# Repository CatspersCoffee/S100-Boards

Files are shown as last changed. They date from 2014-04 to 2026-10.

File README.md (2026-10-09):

# S100-Boards

S-100 bus boards designed, laid out and built for a home-built S-100 system between 2013 and 2016: Z80 and 80386 CPU cards, static and dynamic memory, I/O and SPI peripheral cards, an 18-slot backplane and bus termination. The designs are in KiCad, with Xilinx CPLD and FPGA logic on most boards.

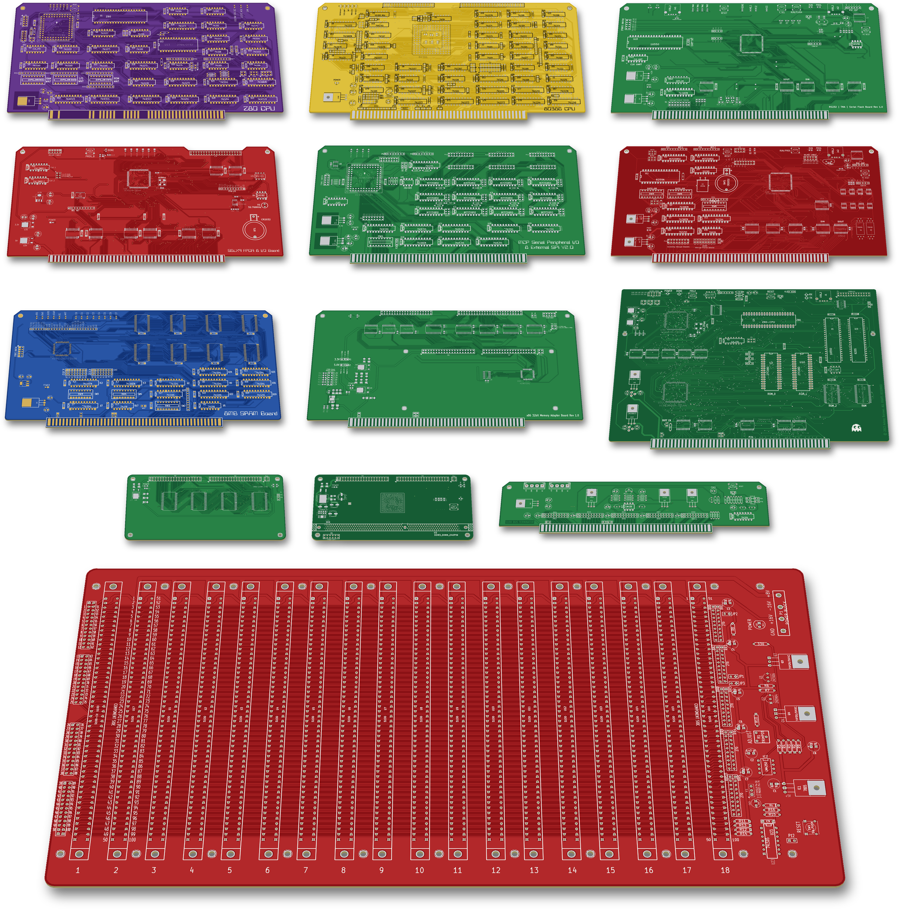
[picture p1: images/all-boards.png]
All boards, rendered from the KiCad files and fabrication gerbers


## Background

The S-100 bus began with the MITS Altair 8800 in 1975 and was standardised as IEEE-696 in 1983. Hobbyists still design new boards for it today. John Monahan's S100Computers.com and the N8VEM project are two well-known sources, and several boards here started from their designs.

This work ran from 2013 to 2016:
- **2013:** a Z80 single-board computer and the 18-slot backplane.
- **2014:** the Z80 CPU card, the 8MB SRAM boards, the serial-flash development board and the Spartan-6 I/O card.
- **2015:** the CPLD versions of the Z80 card, the 80386 CPU card, the SPI I/O board and the 32-bit memory experiments.
- **2016:** a revised backplane and the 8259A/SPI board.

The original S-100 cards of the 1970s and 80s were built from dozens of TTL chips, and later from HCMOS. A thread running through these boards is to move that glue logic into Xilinx CPLDs (XC9572, XC9572XL, XC95288XL) and Spartan-6 FPGAs. This covers bus status decoding, board select and address compare, memory bank and chip-select decoding, and I/O port decoding.
- **8MB SRAM board:** Rev 1 uses 27 TTL logic chips. Rev 2 does the same job with 14, one of them an XC9572XL.
- **Z80 CPU card:** from REV 4.0 an XC9572 takes over the S-100 status and control logic.
- **Other boards:** the CPLD or FPGA implements I/O ports and SPI interfaces that would otherwise need extra discrete logic.

## Boards

| Board | Folder | What it is | Status |
|---|---|---|---|
| Z80 CPU | [`Z80-CPU/`](Z80-CPU/) | Z80 bus-master CPU card, four revisions (REV 1.0–5.0); XC9572 CPLD from REV 4.0 | Built (all revisions) |
| 80386 CPU (V3.1) | [`80386-CPU/`](80386-CPU/) | John Monahan's S100Computers 80386 CPU board with small changes | Built |
| 18-slot backplane | [`Backplane-18-Slot/`](Backplane-18-Slot/) | 18-slot motherboard with active termination, Rev 1.0 and Rev 2.0 | Built (both) |
| Serial Flash board | [`Flash-UART/`](Flash-UART/) | USB UART, TMA lines and four SPI flash chips loaded over USB (CH341A); XC95288XL CPLD | Built |
| S6LX9 FPGA & I/O | [`S6LX9-FPGA-IO/`](S6LX9-FPGA-IO/) | Spartan-6 XC6SLX9 I/O card with RTC and serial RAM/flash | Built |
| MCP Serial Peripheral I/O | [`XC9500-IO/`](XC9500-IO/) | XC9572 CPLD + 12× MCP23S08 SPI port expanders (96 I/O lines) | Built |
| PIC-SPI | [`PIC-SPI/`](PIC-SPI/) | 8259A interrupt controller, SPI RTC/port expanders, 8× SPI flash; XC95288XL CPLD | Built |
| 8MB SRAM | [`SRAM-8MB/`](SRAM-8MB/) | 16 × 512 KB SRAM card, Rev 1 (TTL) and Rev 2.0 (XC9572XL CPLD) | Built (both) |
| x86 Memory Adapter + 4Mbit module | [`x86-Memory-Adapter/`](x86-Memory-Adapter/) | 32-bit memory adapter card (XC9572XL) and a 128K × 32 SRAM mezzanine (XC9536XL) | Module built; adapter not built |
| 4GB DRAM | [`DRAM-4GB-Unfinished/`](DRAM-4GB-Unfinished/) | Spartan-6 XC6SLX45 + DDR3 DIMM mezzanine for the memory adapter | Unfinished |
| Bus terminator | [`Bus-Terminator/`](Bus-Terminator/) | Plug-in active S-100 bus terminator | Built |
| Z80 FPGA SBC | [`Z80-FPGA-SBC/`](Z80-FPGA-SBC/) | 2013 Z80 single-board computer with XC95288XL CPLD and XC6SLX9 FPGA | Not built |
| SX6-MEM | [`SX6-MEM/`](SX6-MEM/) | Spartan-6 + SDRAM DIMM daughterboard, schematic only | Unfinished |
| NOR-SRAM loader | [`NOR-SRAM-Loader/`](NOR-SRAM-Loader/) | XC9572XL CPLD design for a serial-NOR-to-SRAM loader board | CPLD only |

Each folder has its own README with the parts, how the board works, the files, and a short "Things to check" list where something in the files looks worth a second look.

## Board views

Front and back of each board, rendered from its fabrication gerbers (or from the PCB file where no gerbers were made).

### Z80 CPU: [`Z80-CPU/`](Z80-CPU/)
The Z80 bus-master CPU card (REV 5.0 shown), with an XC9572 CPLD for the S-100 status and control logic.

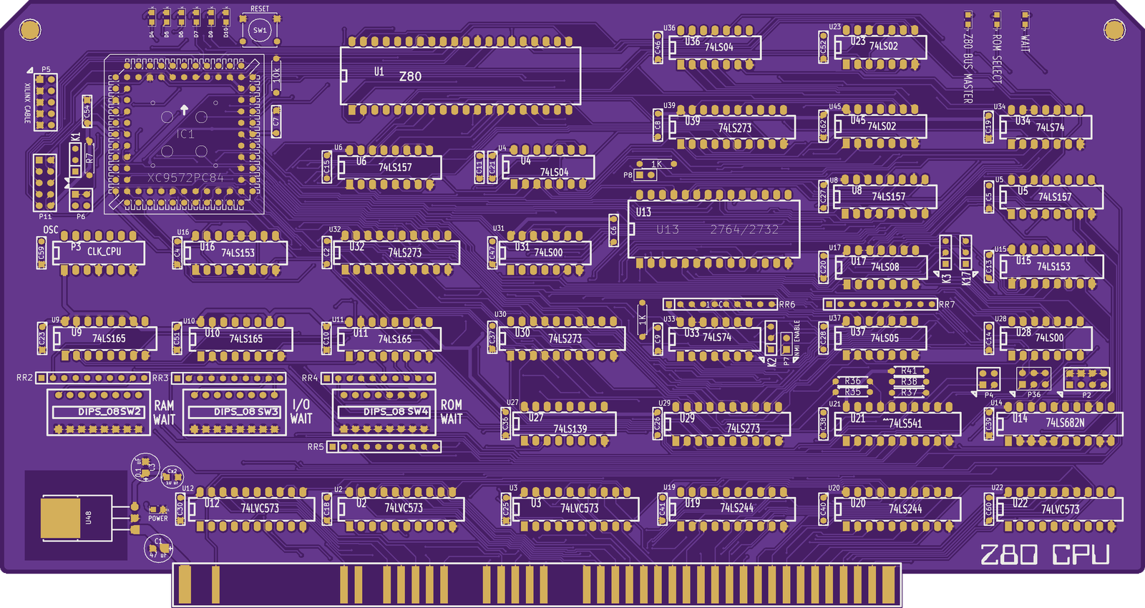
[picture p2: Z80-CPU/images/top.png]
Z80 CPU REV 5.0, front
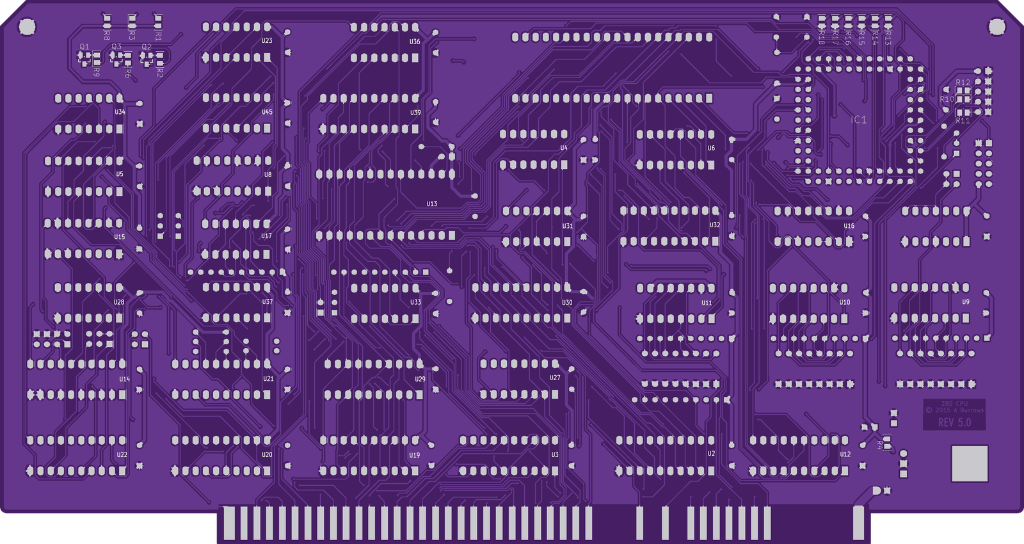
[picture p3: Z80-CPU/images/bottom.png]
Z80 CPU REV 5.0, back
 

### 80386 CPU (V3.1): [`80386-CPU/`](80386-CPU/)
John Monahan's S100Computers.com 80386 CPU board, with small V3.1 changes (TO-220 5 V regulator in place of the TO-3 7805, SMD status LEDs, a power LED).

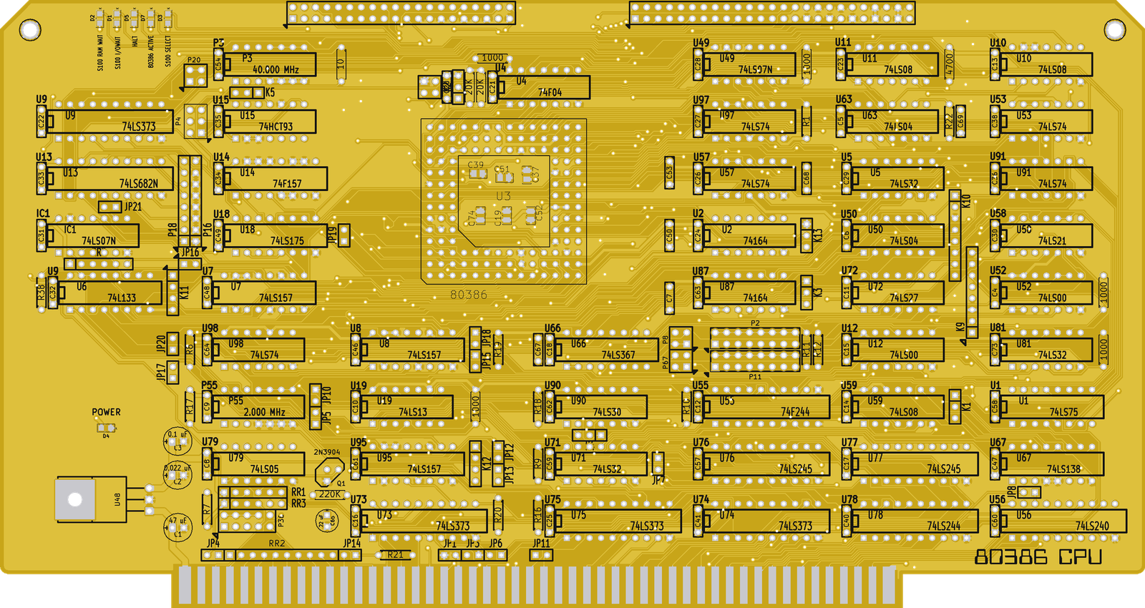
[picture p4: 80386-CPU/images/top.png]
80386 CPU, front
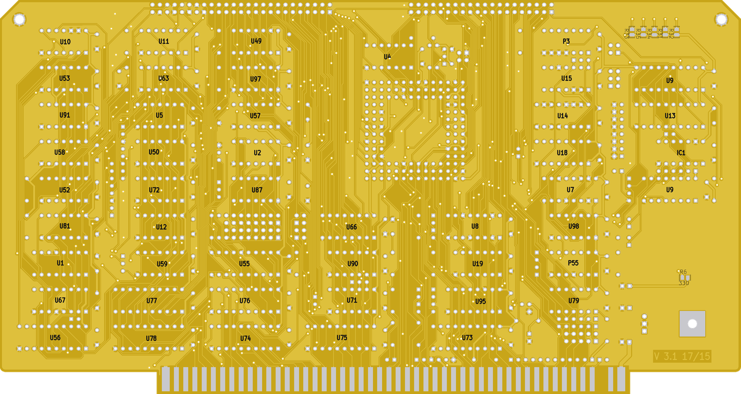
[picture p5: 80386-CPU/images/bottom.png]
80386 CPU, back
 

### 18-slot backplane: [`Backplane-18-Slot/`](Backplane-18-Slot/)
An 18-slot S-100 motherboard with on-board active termination and a reset circuit (Rev 2.0 shown).

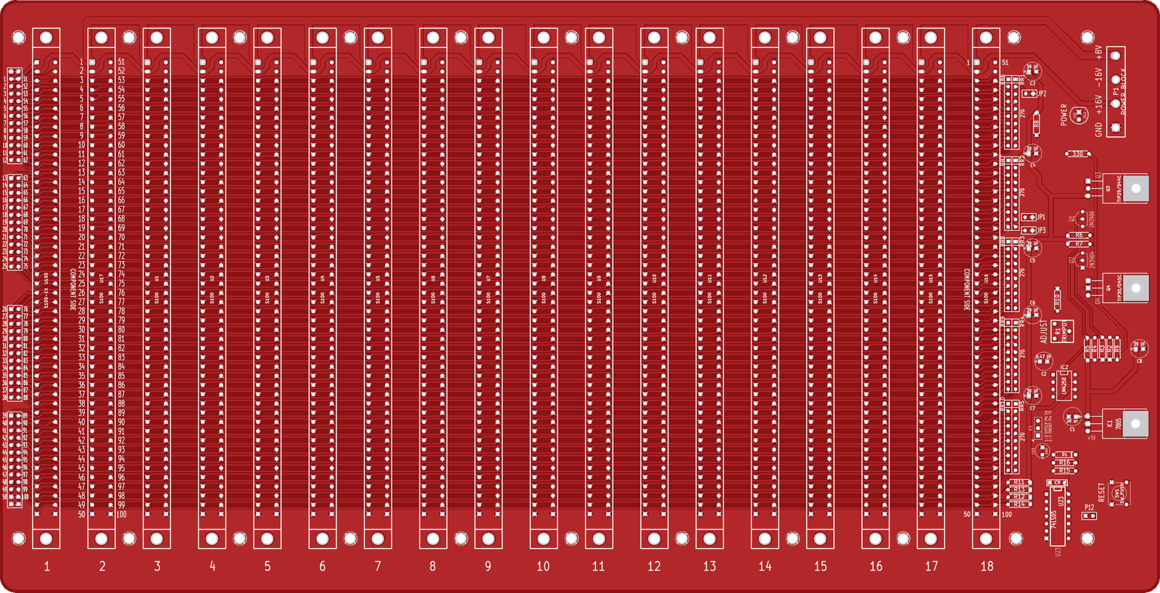
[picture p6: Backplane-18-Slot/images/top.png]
Backplane, front
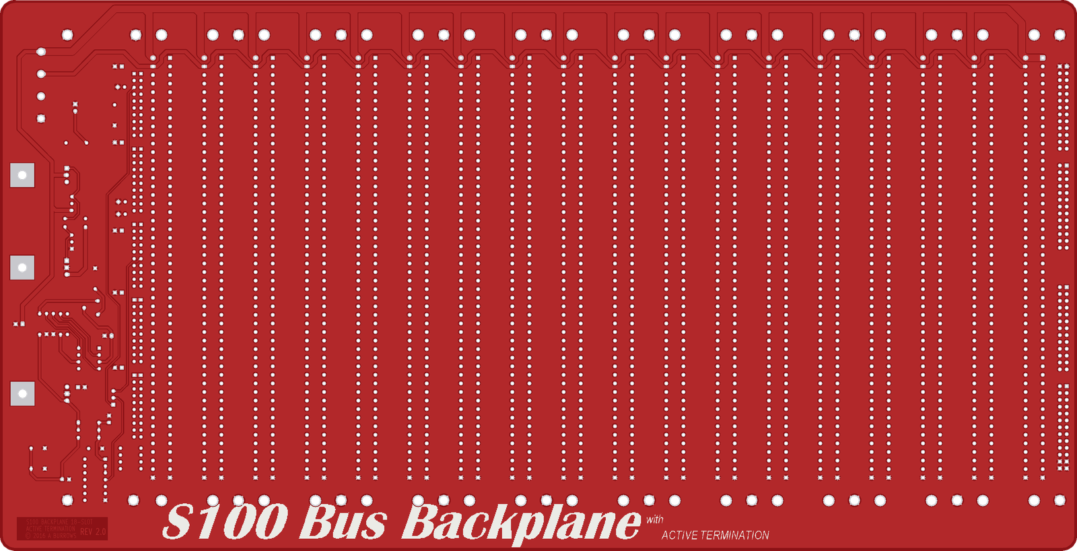
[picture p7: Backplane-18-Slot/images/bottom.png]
Backplane, back
 

### Serial Flash board: [`Flash-UART/`](Flash-UART/)
A USB serial port plus four SPI flash chips that a PC loads over USB and the S-100 side reads back into RAM, for quick development turnaround.

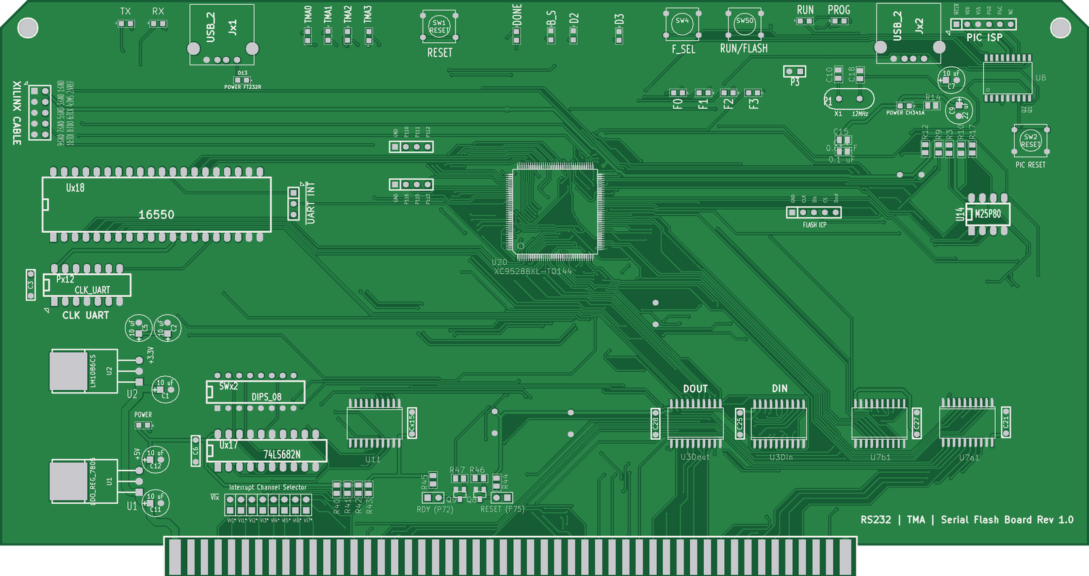
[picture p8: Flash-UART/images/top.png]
Serial Flash board, front
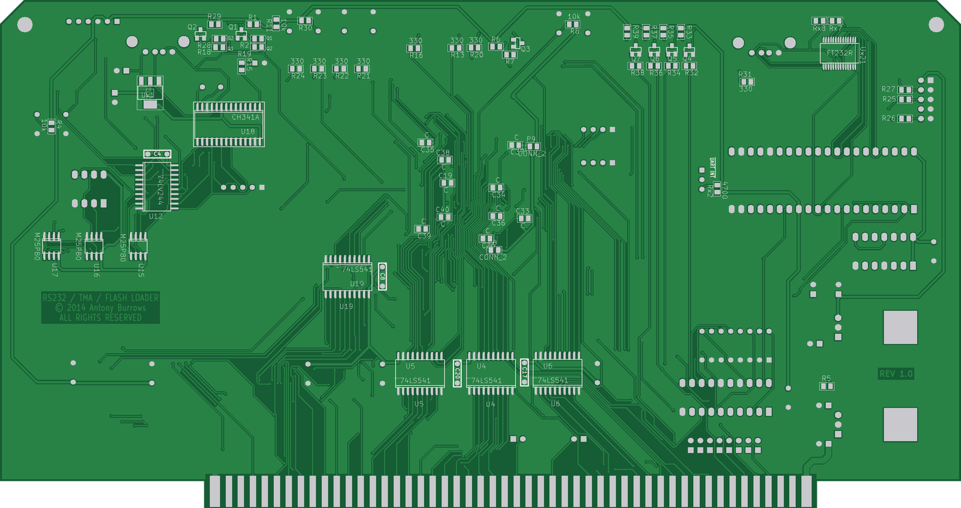
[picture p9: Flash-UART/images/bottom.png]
Serial Flash board, back
 

### S6LX9 FPGA & I/O: [`S6LX9-FPGA-IO/`](S6LX9-FPGA-IO/)
A general-purpose S-100 I/O card built around a Spartan-6 XC6SLX9, with a DS1302 RTC, serial RAM and SPI flash.

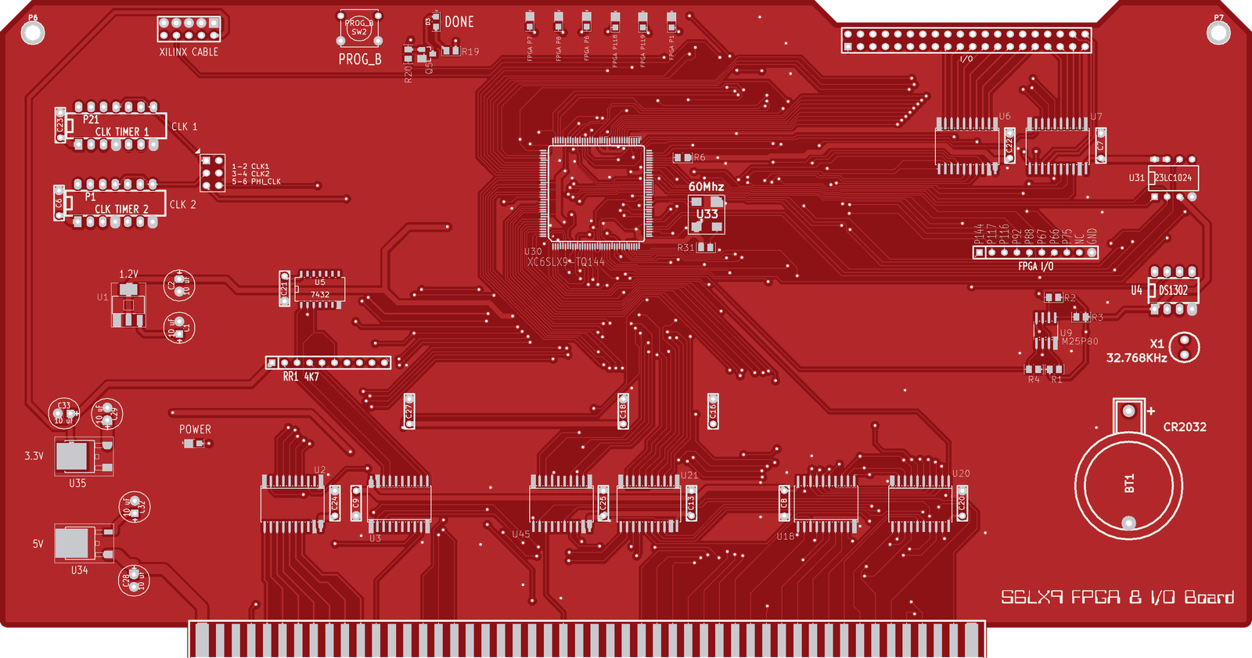
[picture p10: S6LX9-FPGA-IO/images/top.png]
S6LX9 FPGA and I/O board, front
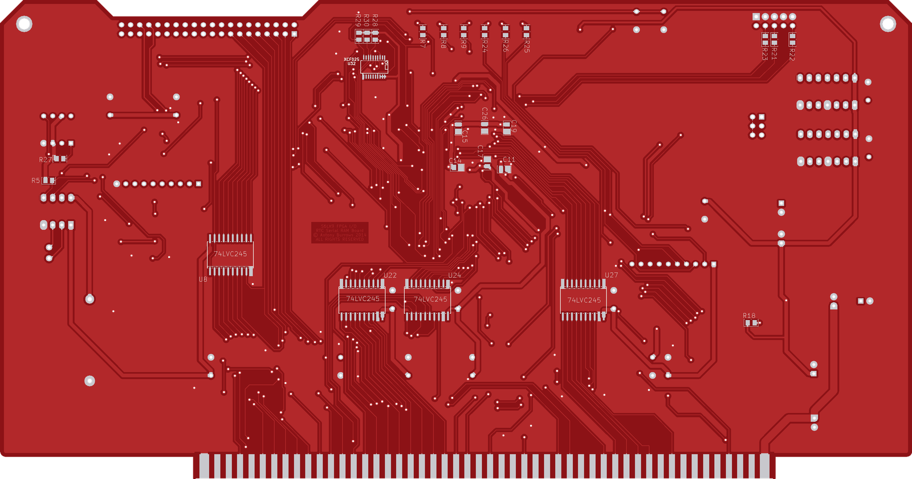
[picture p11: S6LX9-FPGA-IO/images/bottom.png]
S6LX9 FPGA and I/O board, back
 

### MCP Serial Peripheral I/O: [`XC9500-IO/`](XC9500-IO/)
An XC9572 CPLD driving twelve MCP23S08 SPI port expanders for 96 I/O lines, plus two external SPI ports.

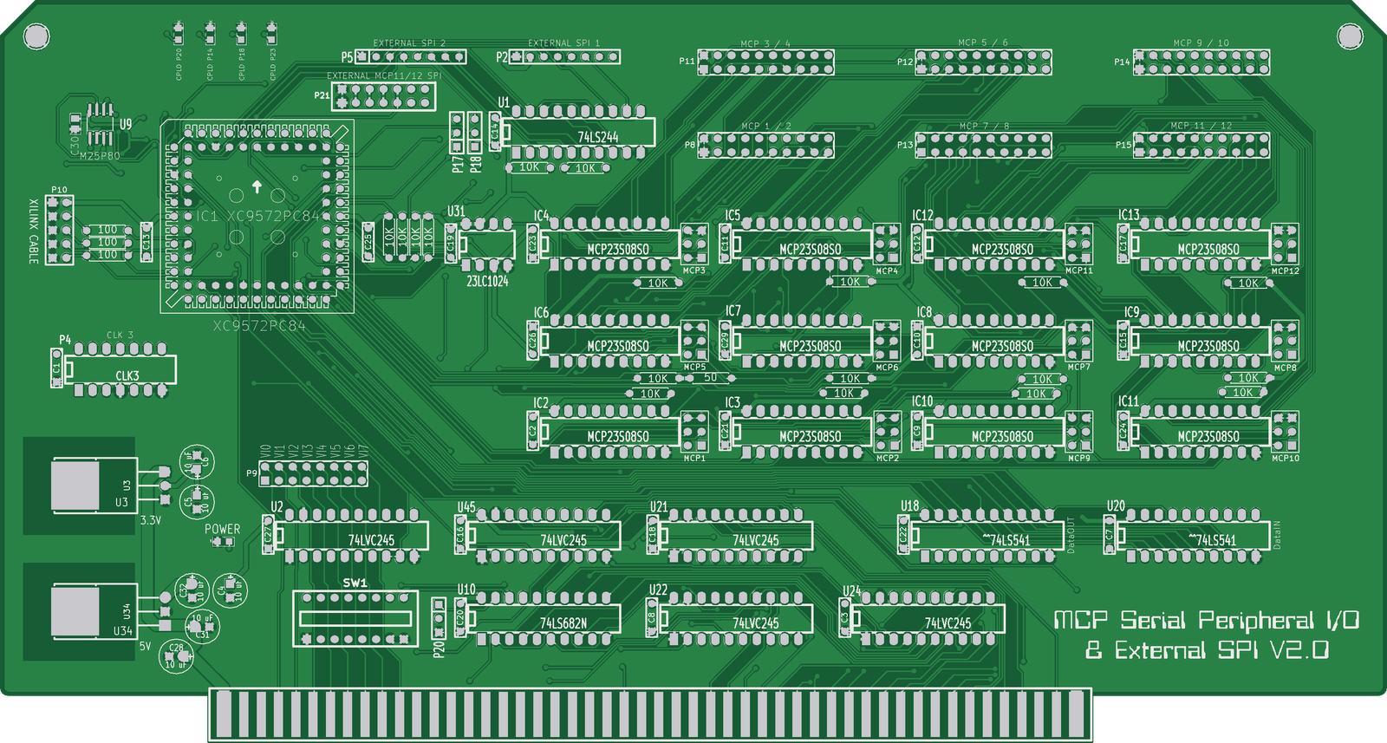
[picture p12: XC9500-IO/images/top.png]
MCP Serial Peripheral I/O, front
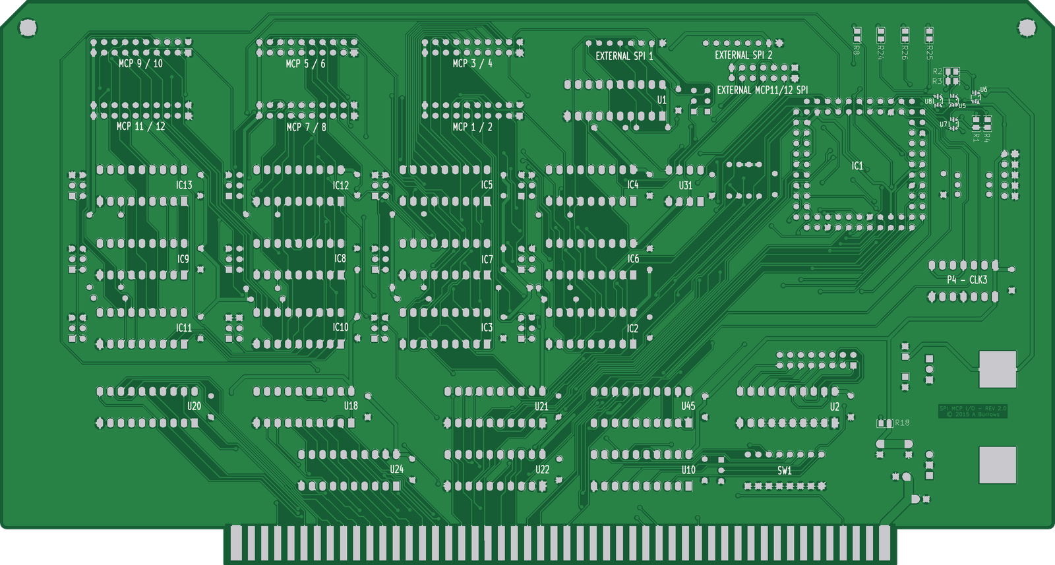
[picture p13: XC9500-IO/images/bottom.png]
MCP Serial Peripheral I/O, back
 

### PIC-SPI: [`PIC-SPI/`](PIC-SPI/)
An 8259A interrupt controller on the vectored-interrupt lines, with an XC95288XL CPLD running an SPI bus (RTC, port expanders) and eight SPI flash chips.

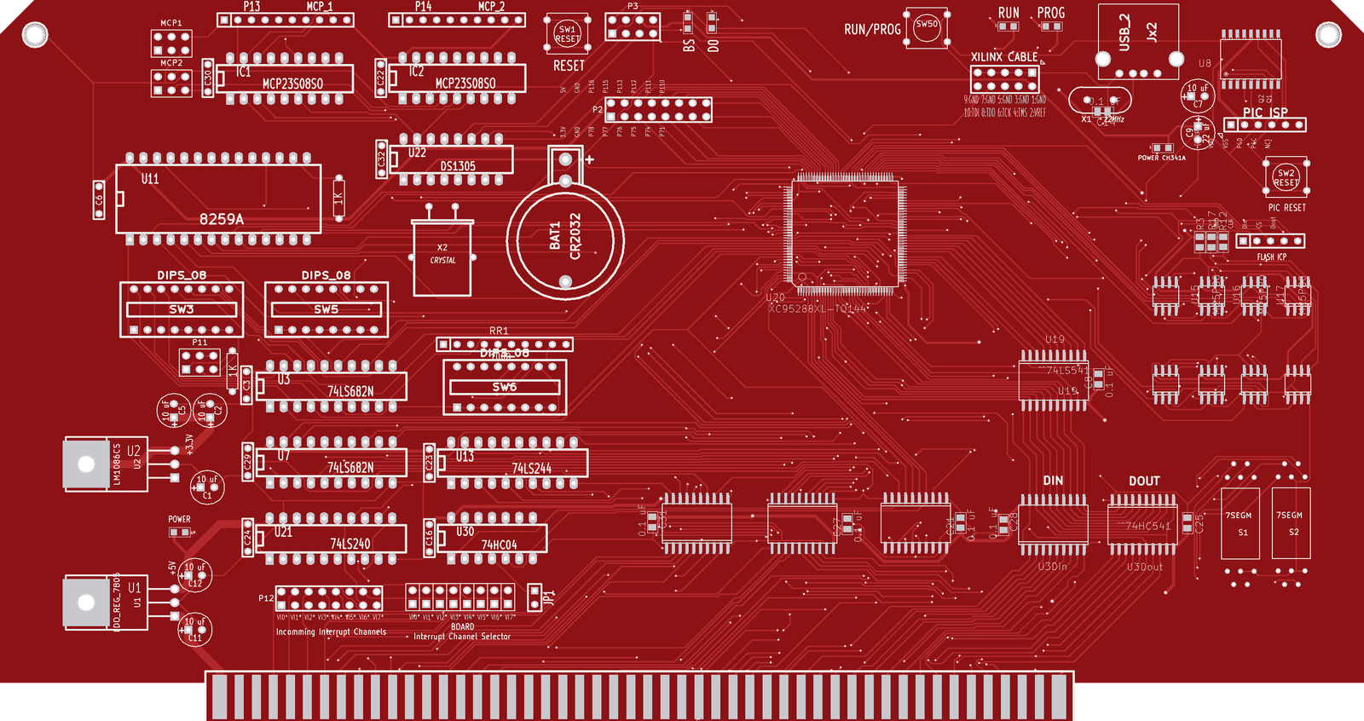
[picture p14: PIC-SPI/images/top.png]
PIC-SPI, front
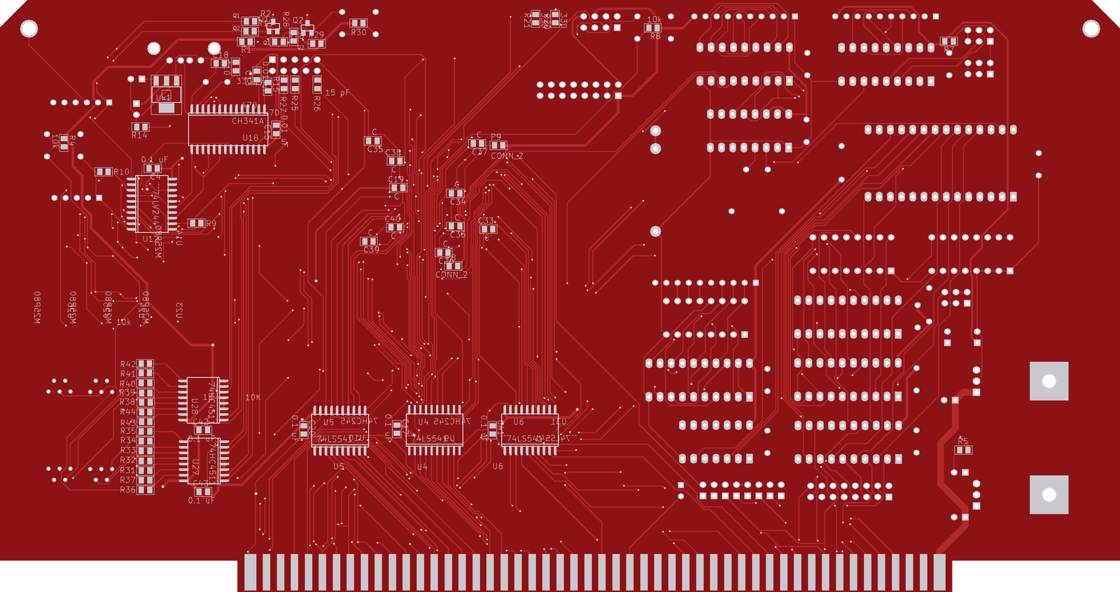
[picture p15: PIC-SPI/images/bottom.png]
PIC-SPI, back
 

### 8MB SRAM: [`SRAM-8MB/`](SRAM-8MB/)
Sixteen 512 KB SRAMs as a 16-bit, 8 MB memory card; Rev 2.0 (shown) moves the TTL bus logic into an XC9572XL CPLD.

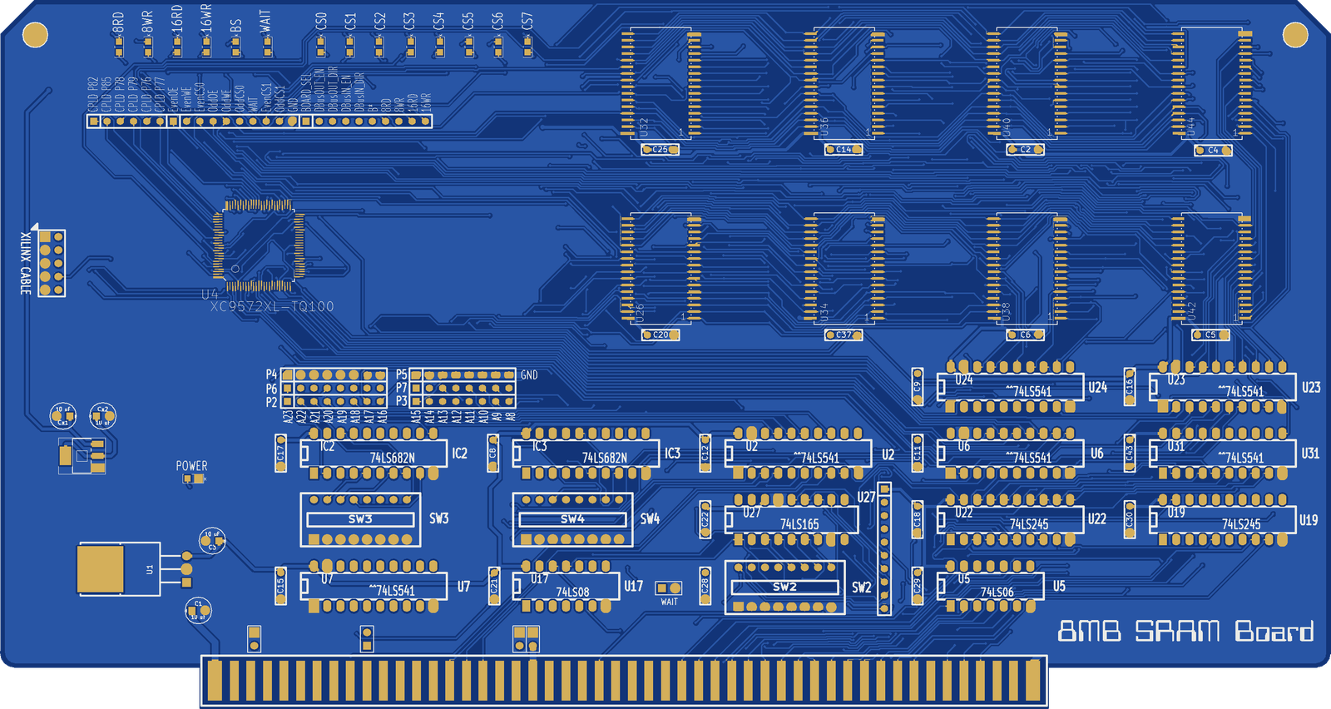
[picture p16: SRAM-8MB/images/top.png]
8MB SRAM Rev 2.0, front
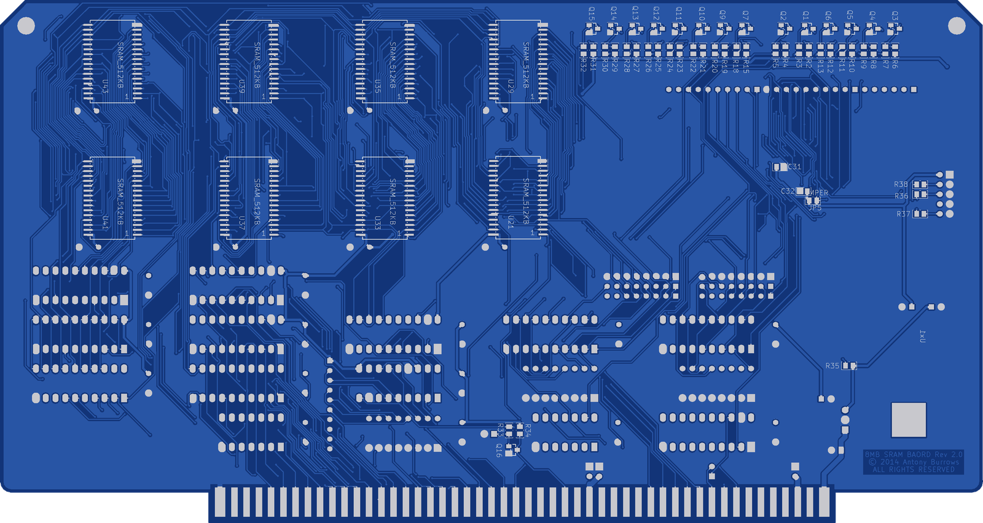
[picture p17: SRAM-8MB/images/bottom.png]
8MB SRAM Rev 2.0, back
 

### x86 Memory Adapter and 4Mbit SRAM module: [`x86-Memory-Adapter/`](x86-Memory-Adapter/)
A 32-bit memory adapter card with an XC9572XL and 3.3 V buffers (top pair), and the 128K × 32 SRAM mezzanine that plugs onto it (bottom pair).

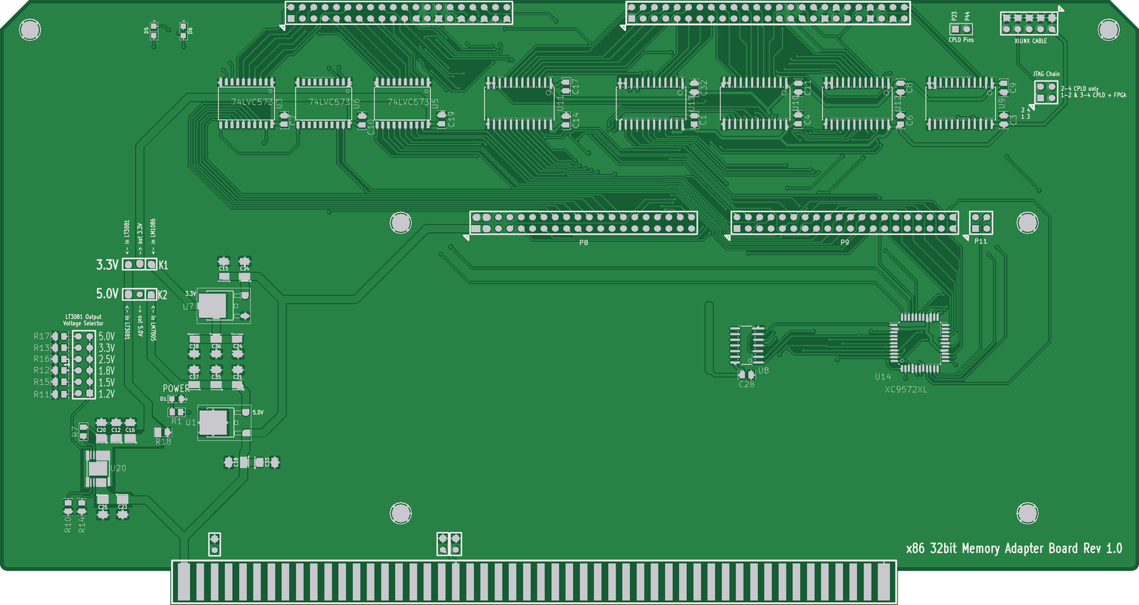
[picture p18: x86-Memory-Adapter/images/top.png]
x86 Memory Adapter, front
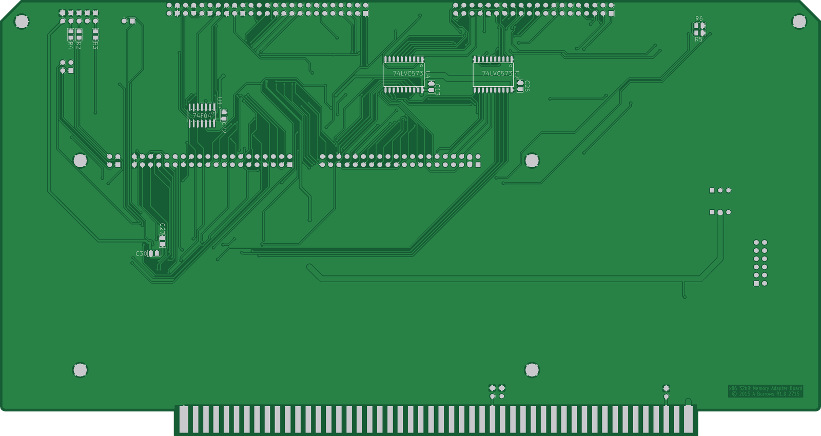
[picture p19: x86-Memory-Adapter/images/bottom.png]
x86 Memory Adapter, back
 
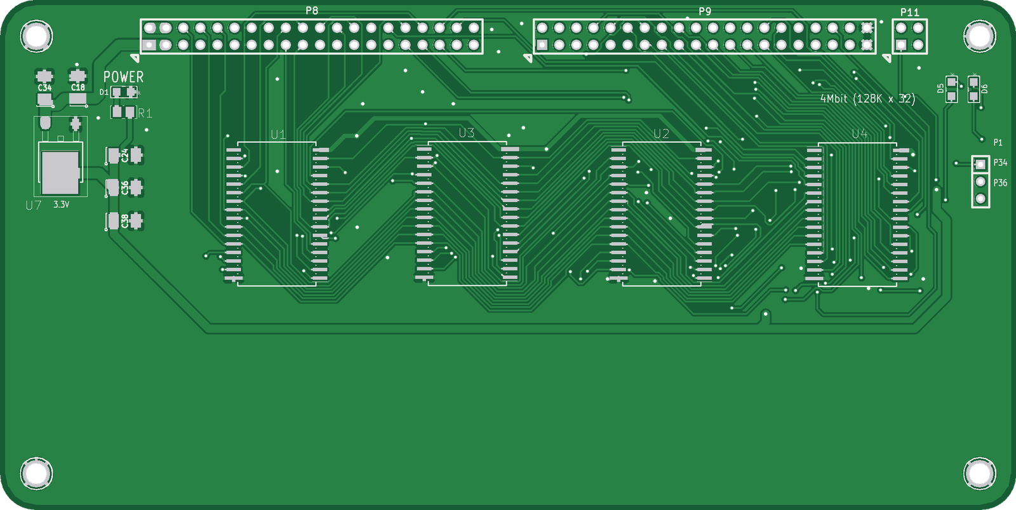
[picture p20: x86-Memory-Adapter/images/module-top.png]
4Mbit SRAM module, front
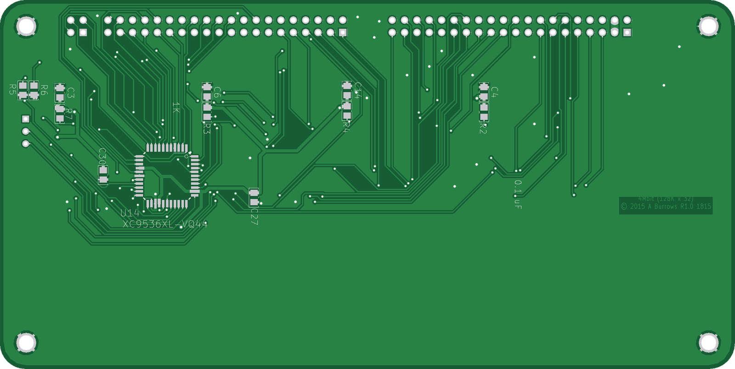
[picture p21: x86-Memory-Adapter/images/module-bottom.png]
4Mbit SRAM module, back
 

### 4GB DRAM (unfinished): [`DRAM-4GB-Unfinished/`](DRAM-4GB-Unfinished/)
A Spartan-6 XC6SLX45 and DDR3 DIMM mezzanine for the memory adapter; parts are placed but the DDR3 routing was never done.

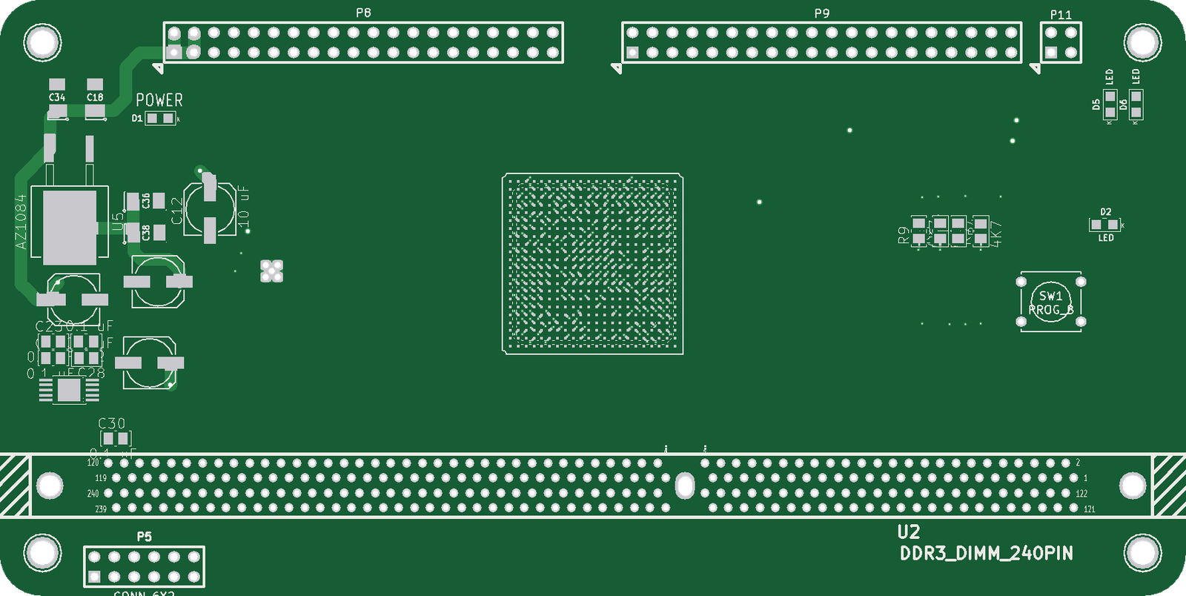
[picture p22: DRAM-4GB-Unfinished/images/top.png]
4GB DRAM, front
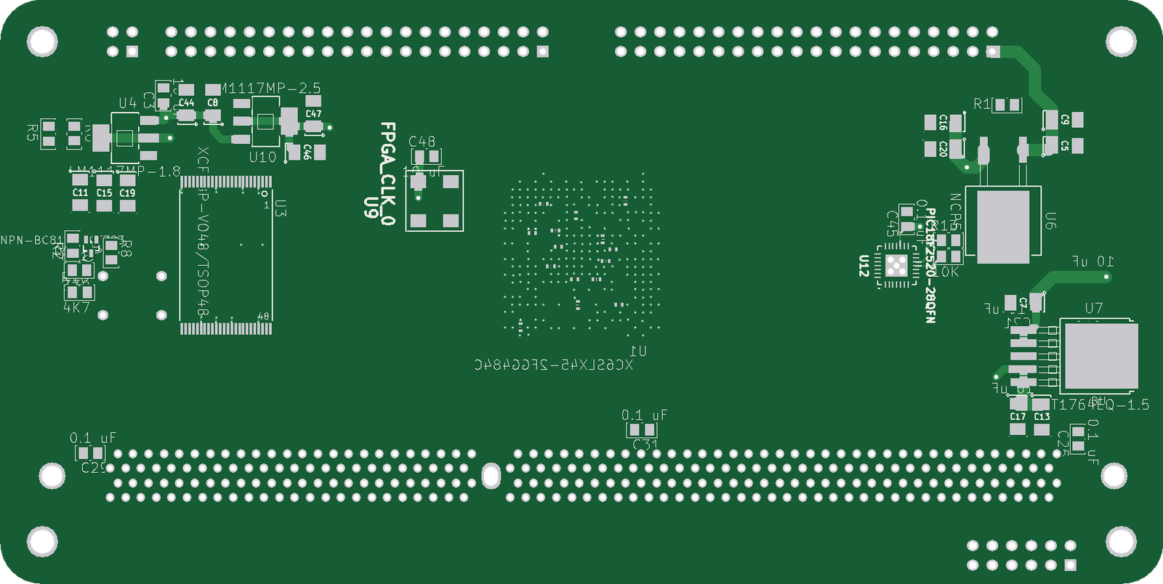
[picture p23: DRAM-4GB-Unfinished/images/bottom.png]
4GB DRAM, back
 

### Bus terminator: [`Bus-Terminator/`](Bus-Terminator/)
A plug-in active terminator card that holds the S-100 lines at a regulated termination voltage, plus a reset circuit and two +5 V Molex power outlets.

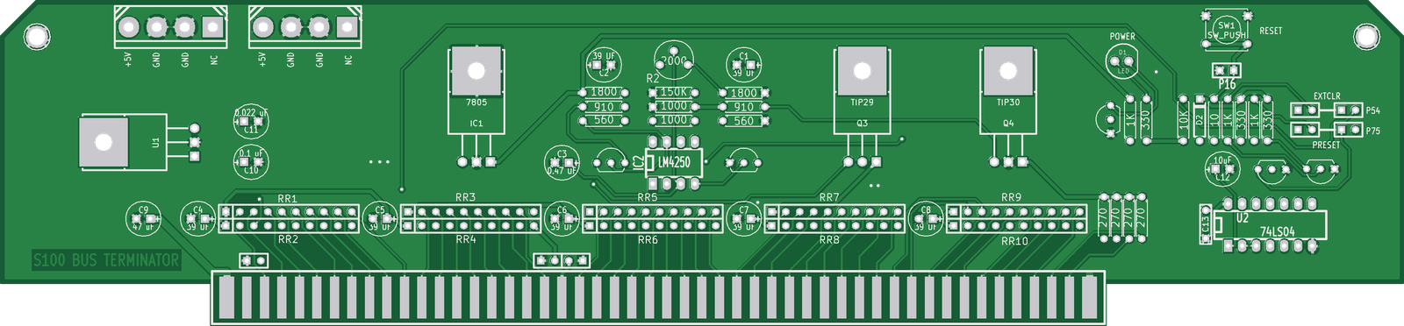
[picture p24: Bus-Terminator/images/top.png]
Bus terminator, front
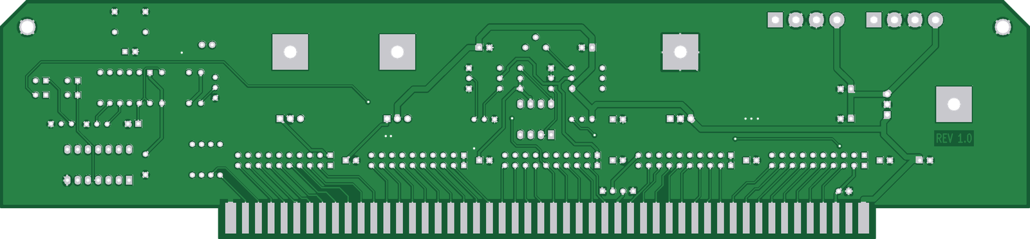
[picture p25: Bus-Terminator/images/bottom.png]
Bus terminator, back
 

### Z80 FPGA SBC: [`Z80-FPGA-SBC/`](Z80-FPGA-SBC/)
A 2013 Z80 single-board computer on an S-100 card with an XC95288XL CPLD, a Spartan-6 XC6SLX9, SRAM, a 16550 UART on USB and an 8255 (REV 2.0 layout shown).

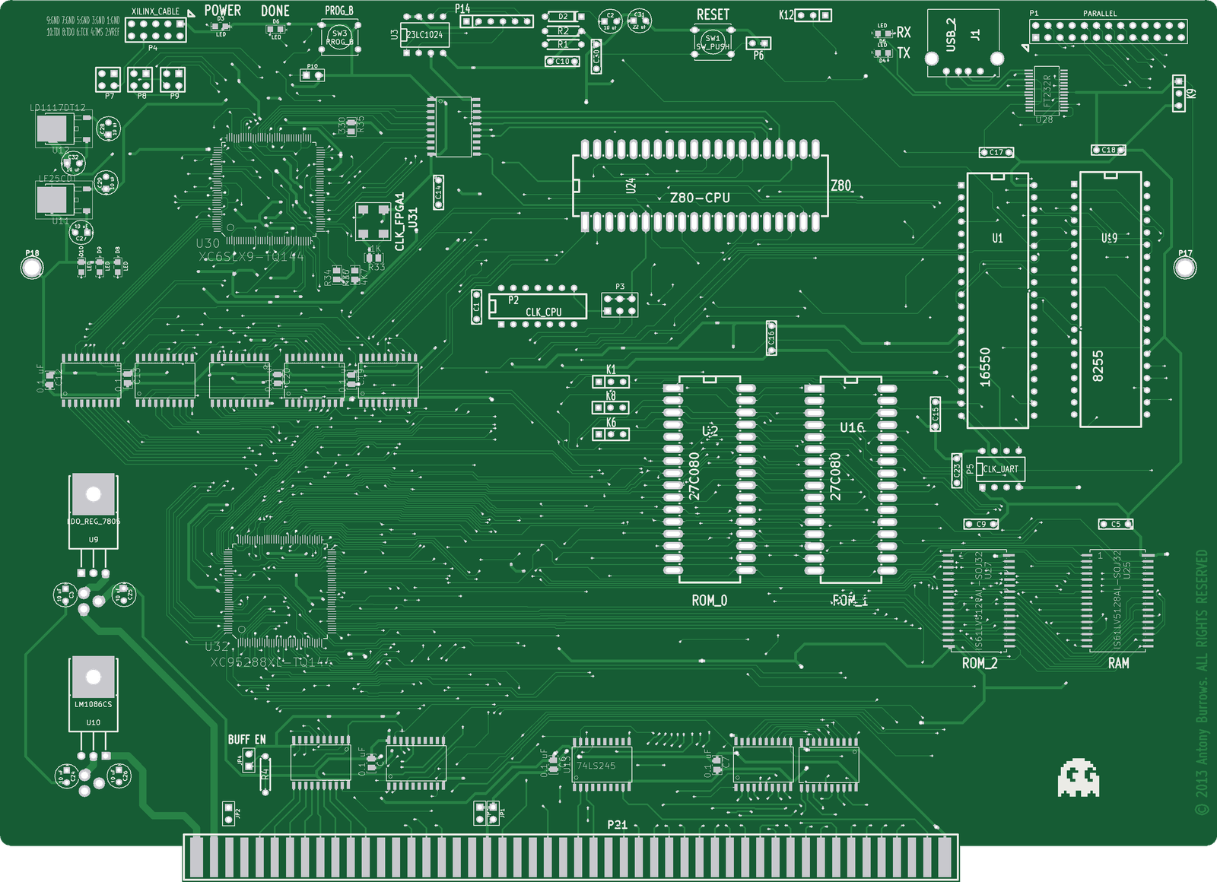
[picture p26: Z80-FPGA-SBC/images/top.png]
Z80 FPGA SBC, front
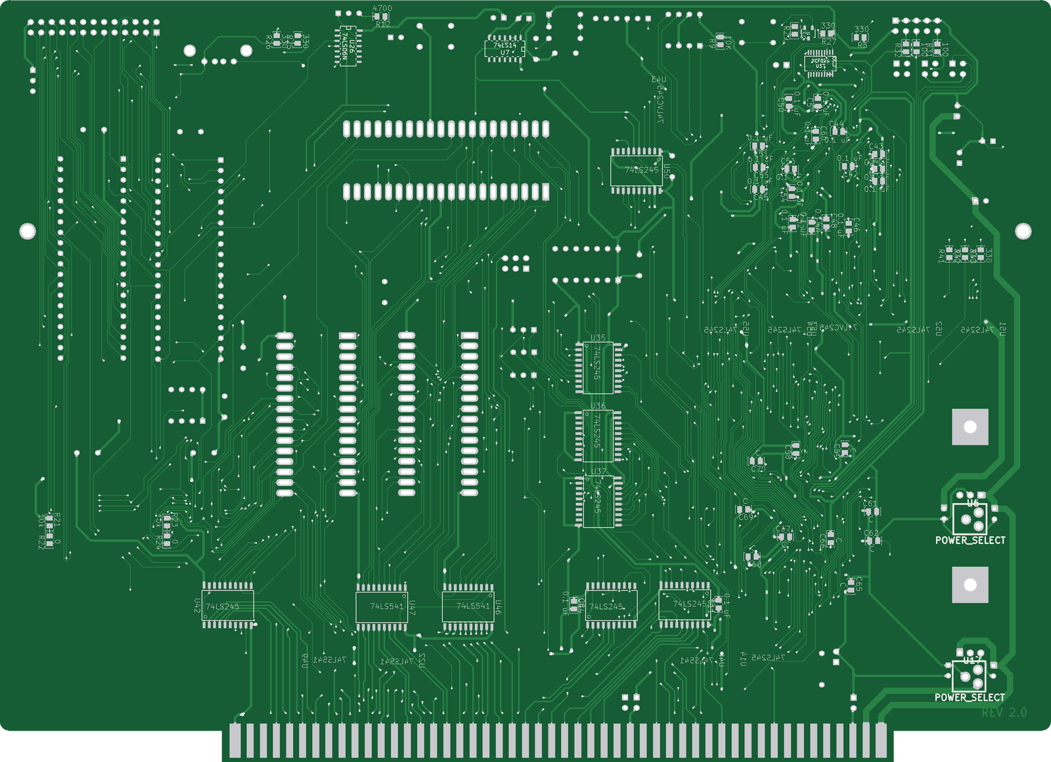
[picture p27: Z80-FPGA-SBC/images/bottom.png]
Z80 FPGA SBC, back
 

### SX6-MEM: [`SX6-MEM/`](SX6-MEM/)
A schematic for a Spartan-6 XC6SLX25 and 168-pin SDRAM DIMM daughterboard. No PCB layout was made.

### NOR-SRAM loader: [`NOR-SRAM-Loader/`](NOR-SRAM-Loader/)
An XC9572XL CPLD design for a board that would copy a serial NOR flash into 1 MB of SRAM. Only the CPLD design exists.

## Tools
- KiCad 2013-07-07 (BZR 4022). The schematics use the legacy `.sch` format; newer KiCad versions need the symbol remap step when opening them.
- Xilinx ISE 14.7 for the CPLD and FPGA designs (schematic entry, `.ucf` pin maps, `.jed`/`.bit` programming files).

## History
The git history replays the original dated project backups, oldest first, with each commit dated from the files it contains (NZ time). Boards are interleaved by date. The last commit adds the READMEs, images and licenses.

Not included: tool output, KiCad backup and autorouter files, PDFs and datasheets, and third-party originals that were kept alongside the projects.

## Credits
Several boards started from other people's designs: John Monahan (S100Computers.com), Andrew Lynch and the N8VEM project, and Godbout/CompuPro. See [NOTICE](NOTICE) and each board's README.

## License
- Board and CPLD/FPGA designs: [CERN-OHL-S-2.0](LICENSES/CERN-OHL-S-2.0.txt).
- Documentation and images: [CC-BY-4.0](https://creativecommons.org/licenses/by/4.0/).

These cover the original work only; third-party parts keep their authors' rights (see [NOTICE](NOTICE)). Copyright text on fabricated boards ("ALL RIGHTS RESERVED") is left as built; these licenses apply to the files.

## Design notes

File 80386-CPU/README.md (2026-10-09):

# 80386 CPU (V3.1)

An S-100 bus 80386 CPU card. It is mostly **John Monahan's S100Computers.com "S-100 80386 CPU Board, Version 3"**, with small changes by me (V3.1, 2014–2015). Full credit for the design goes to him.

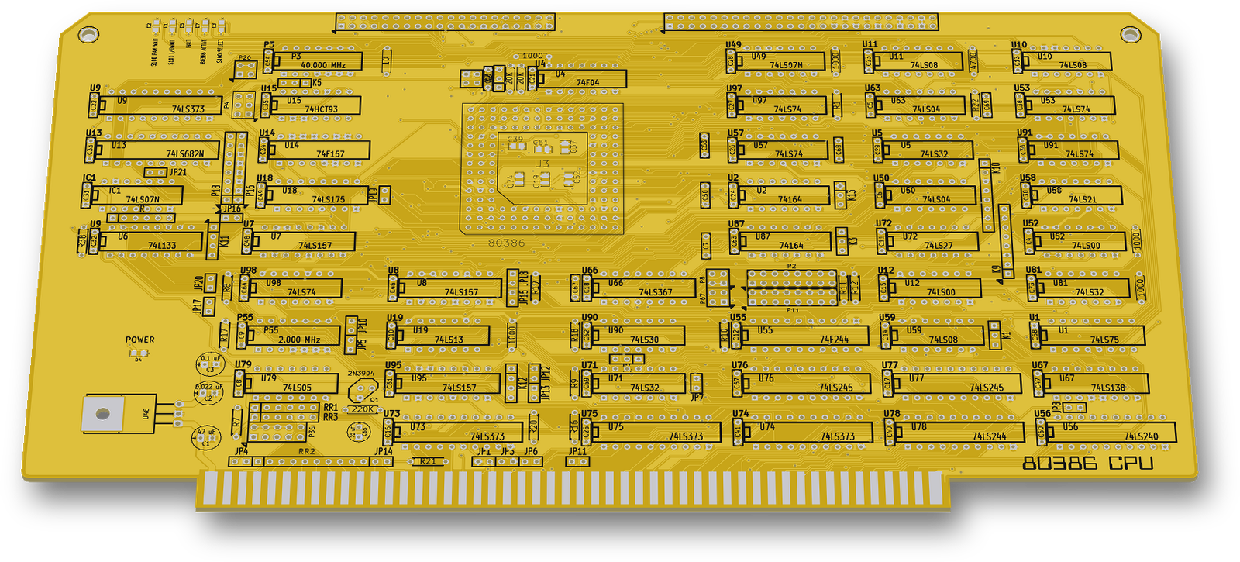
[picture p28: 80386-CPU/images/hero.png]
80386 CPU


 

## Status

Built. The gerbers were sent to PCBway on 28-07-2015. The original working folder holds a copy named `GERBERS/SENT to PCBway 28-07-2015/`, identical to `gerbers/` here.

The fabricated silkscreen says only "80386 CPU" (front) and "V 3.1 17/15" (bottom copper). It has no S100Computers.com text, because the original "S100Computers.com & N8VEM" and "S-100 80386 CPU BOARD VERSION 03" lines were removed in V3.1. The board files are kept as fabricated, and the credit is in this README.

## Hardware

| Ref | Part | Role |
|---|---|---|
| U3 | 80386 (PGA-132) | CPU |
| P3 / P55 | 40.000 MHz / 2.000 MHz | oscillators (14-pin DIP) |
| U13 | 74LS682 | compares A24–A31 |
| U9, U73, U74, U75 | 74LS373 | address latches |
| U76, U77 / U78 / U55 / U56 | 74LS245 / 74LS244 / 74F244 / 74LS240 | bus buffers |
| U7, U8, U95 / U14 | 74LS157 / 74F157 | multiplexers |
| U2, U87 | 74164 | shift registers |
| U66 | 74LS367 | drives the status LEDs |
| U48 | LDO 7805 (TO-220) | +5 V from the S-100 +8 V rail |
| Q1 | 2N3904 | |

- Board: 254.0 x 134.62 mm (10.0 x 5.3 in, including the edge connector), 2 layers.
- KiCad (2013-07-07 BZR 4022)-stable. The files are in the legacy `.sch` / `.brd` formats.
- LEDs: D2 "S100 RAM WAIT", D1 "S100 I/OWAIT", D5 "HALT", D7 "80386 ACTIVE", D3 "S100 SELECT", D4 "POWER".
- Jumpers and headers: JP1, JP3–JP21 and K1–K13. Also:
  - P10 (20x2): CPU address lines;
  - P12 (25x2): D0–D31 and 80386-RESET;
  - P2 / P11 (8x2);
  - P36 (5x2): TMA0*–TMA3* bus-master selection.

## How it works

- The 386 runs on the S-100 bus through TTL latches and buffers. The schematic notes label the data buffers "EVEN TO CPU 8 BITS", "ODD FROM CPU 8 BITS", "ODD TO CPU 8 BITS" and "EVEN FROM CPU 8 BITS".
- U13 (74LS682) compares the top address bits A24–A31. The schematic notes mark "LOW FOR RAM > 16M" and "LOW/HIGH FOR S-100 BUS ACCESS".
- A schematic note reads "FORCE FFFFFFF0 TO 000FFFF0 TO PC BIOS/MONITOR".
- S-100 signals used include:
  - pSYNC, pSTVAL*, pDBIN, pWR*, MWRT and sINTA;
  - RDY, XRDY, HOLD* and pHLDA;
  - TMA0*, SLAVE_CLR*, sXTRQ* and PHANTOM*;
  - RESET*, INT*, NMI* and ERROR*.
- S-100 pins 20 and 70 go to GND through JP1 and JP3.

### Changes in V3.1 (compared with John Monahan's V3 files of 30 May 2014)

- The 7805 in a TO-3 package was replaced by an LDO 7805 in TO-220 (U48). C1 changed from 33 µF to 47 µF, and C2 (0.022 µF) was added.
- POWER LED D4 with R6 (330 Ω) added.
- The status LEDs D1/D2/D3/D5/D7 became 0805 SMD parts with their own 330 Ω resistors (R31–R35). They replace the 470 Ω resistor pack RR4.
- Six decoupling capacitors inside the 386 socket (C19, C37, C39, C51, C52, C74) became 0805 SMD parts.
- JP2 (S-100 pin 53 to GND) was removed, and so was edge finger 53.
- GND copper pours were added on both layers, and IC reference labels on both sides.
- An "80386 CPU" logo was added, along with rounded shoulders at the edge connector.
- About 96 % of the original tracks are unchanged.

## Files

| Path | What |
|---|---|
| `s100_80386 V3.sch`, `s100_80386 V3-cache.lib` | Schematic and its symbol cache |
| `s100_80386 V3.brd` | PCB layout (as fabricated) |
| `s100_80386 V3.net`, `.cmp`, `.pro` | Netlist, footprint assignments, project |
| `gerbers/` | Gerbers sent to PCBway (the `.drl` is an RS-274X file exported by gerbv) |
| `s100_80386 V3.csv`, `.xlsx` | IC parts list |

## History

The git history replays the files of the original working folder at their save dates (2014-07-18 to 2016-01-10).

## Things to check (TODO)

- U6 (74L133) is labelled "U9" on both silkscreen sides, so "U9" appears twice on each side.
- Edge finger 53 is missing from the S-100 connector footprint (99 of 100 pads). JP2 was removed with it.

## Credits

- **This board is mostly John Monahan's design** (S100Computers.com): the circuit, the parts and almost all of the layout. Full credit goes to him. The original V3 board carried the silkscreen line "S100Computers.com & N8VEM".
- The schematic symbols come from the N8VEM KiCad libraries.

## License

John Monahan's original design is his work. His rights are not relicensed here (see the repo NOTICE).

The repository licence covers only my own changes listed above. For hardware that is CERN-OHL-S-2.0; for docs and images it is CC-BY-4.0.

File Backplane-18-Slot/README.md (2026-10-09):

# S100 Backplane 18-Slot

An 18-slot S-100 bus backplane with on-board active termination. Rev 1.0 is from 2013–2014 and Rev 2.0 from 2015–2016.

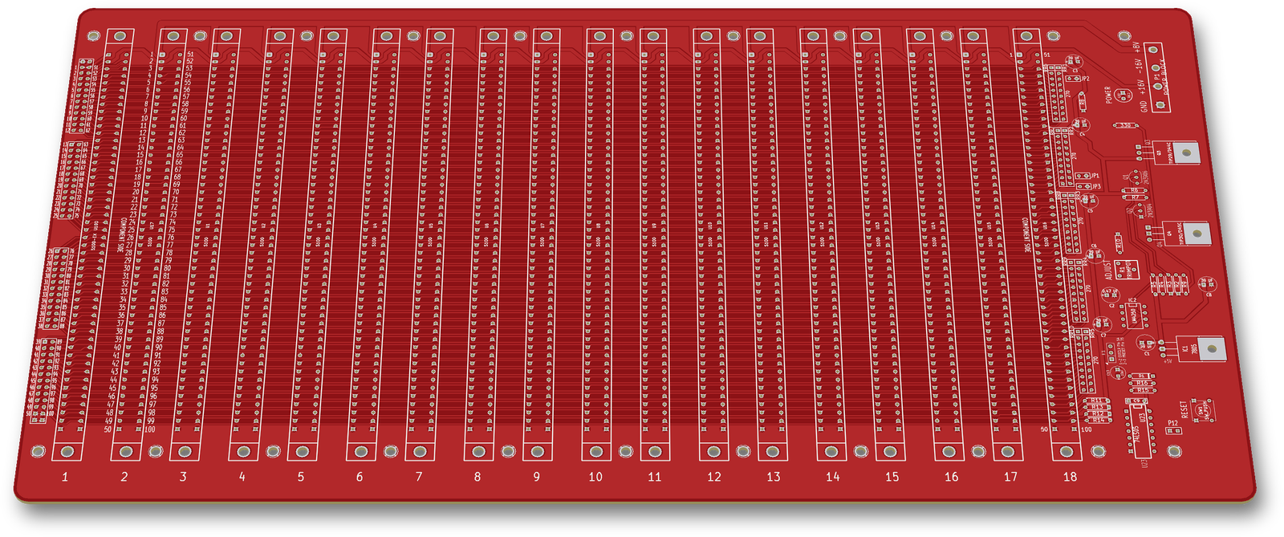
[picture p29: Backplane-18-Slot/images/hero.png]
S100 Backplane 18-Slot


 

## Status
Built. Both Rev 1.0 and Rev 2.0 were made. Rev 1.0 has a red solder mask.

## Hardware
- **Board:** 15.70 × 8.00 in (398.8 × 203.2 mm), 2 layers, rounded corners. The outline is the same for both revisions.
- **Slots:** 18 S-100 100-pin connectors at 0.75 in pitch. The silkscreen numbers them 1–18. All 18 are wired pin-for-pin in parallel.
- **Board text:**
  - Rev 1: back copper reads `S100 BACKPLANE 18SL`, `© 2014 A BURROWS`, `REV 1.0`.
  - Rev 2: back copper reads `S100 BACKPLANE 18-SLOT`, `ACTIVE TERMINATION`, `© 2016 A BURROWS`, `REV 2.0`.
  - The back silkscreen of both carries the "S100 Bus Backplane with ACTIVE TERMINATION" logo.
- **KiCad:** EESchema/Pcbnew (2013-07-07 BZR 4022)-stable. These are legacy `.sch`/`.brd` files.

| Ref | Part | Role |
|---|---|---|
| IC2 | LM4250 | Programmable op-amp that regulates the termination rail (`Vacc`) |
| Q1, Q2 | 2N3906, 2N3904 | Drivers, switched by the LM4250 supply currents |
| Q3, Q4 | TIP29 / D44C (NPN), TIP30 / D45C (PNP) | Push-pull pass transistors from +8 V and to GND |
| R1 | Trimpot (silk "ADJUST") | Sets the termination voltage |
| RR1–RR10, R11–R14 | 270 Ω SIP networks + 4 resistors | Terminate 94 bus lines to `Vacc` |
| IC1 | 7805 | Local +5 V for the reset logic, reference divider and POWER LED |
| U23 | 74LS05 (Rev 2) / 74LS04 (Rev 1) | Reset buffer |
| SW1, P12 | Push button / 2-pin header | RESET button / external reset button |
| K1 | 3-pin header | Reset target: 1-2 /EXTCLR (pin 54), 2-3 /PRESET (pin 75) |
| JP1, JP2, JP3 | 2-pin jumpers | Tie bus pin 20, 53 or 70 to GND |
| P1 | 4-way barrier strip "POWER BLOCK" | Power input: GND, +16 V, −16 V, +8 V |
| D12 | LED (silk "POWER") | +5 V power indicator (R47 330 Ω) |
| P25–P28 | 2×13 headers | Together bring out all 100 bus pins |

## How it works
- **Power:** comes in on P1.
  - +8 V goes to bus pins 1 and 51, +16 V to pin 2 and −16 V to pin 52.
  - GND goes to pins 50 and 100.
  - The 7805 (IC1) makes a local +5 V from the +8 V rail.
- **Active termination:**
  - Every bus line except the power and ground pins (94 lines) has a 270 Ω resistor to the `Vacc` rail.
  - The LM4250 (IC2) holds `Vacc` at a voltage set by the R9 / R1 / R10 divider from +5 V (R1 is the "ADJUST" trimpot, filtered by C2). It is biased by R2 150K and has R4 1K feedback.
  - Its supply currents flow through R5 and R3 (560 Ω) and turn on Q1 and Q2. These drive Q3, which sources current from +8 V, and Q4, which sinks it to GND.
  - C3–C7 (39 µF) decouple the rail.
- **Reset:**
  - R16 10K and C13 10 µF make a power-on delay, and D1 discharges C13 at power-off. SW1 (or a button on P12) pulls the node low through R15 10 Ω.
  - Two inverters of U23 buffer it. K1 sends the result to /EXTCLR (pin 54) or /PRESET (pin 75).
- **Jumpers:** JP1, JP2 and JP3 can ground pins 20, 53 and 70.

## Revisions
| Folder | Board text | Dates | Changes |
|---|---|---|---|
| `rev1/` | REV 1.0, © 2014 | Aug 2013 – Mar 2014 | First version. The POWER LED is switched by Q13 2N3904 / R46 1K. U23 is a 74LS04. |
| `rev2/` | REV 2.0, © 2016 | Oct 2015 – Dec 2016 | Q13/R46 removed: the LED is fed from +5 V directly. U23 changed to a 74LS05 (open-collector). K1 moved. "ACTIVE TERMINATION" added to the board text. |

## Files
- `rev1/`
  - `S100-Backplane.sch`, `.brd`, `.pro`, `-cache.lib`: KiCad project.
  - `.net`, `.cmp`: netlist and component/footprint list.
  - `S100-Backplane.csv/.txt`: early BOM exports, Aug 2013.
  - `Gerbers/`: fabrication files, Mar 2014.
  - `BOM/`: bill of materials, Mar 2014.
- `rev2/`
  - `S100-Backplanev2.*`: KiCad project, netlist and component list.
  - `Gerbers/`: final fabrication set, Oct 2016. Most layers were post-processed in gerbv; the top copper is a KiCad export.
  - `Gerbers/kicad-export/`: the same design exported directly from KiCad, Oct 2016.
  - `BOM/`: BOM with Digi-Key part numbers (`.csv`, `.xlsx`).

Current KiCad versions need *Remap Symbols* to open the 2013-format schematics. Run it in the GUI with the included `-cache.lib`.

## History
The git history replays the original dated backups:
- Rev 1: 16 commits, Aug 2013 → Mar 2014.
- Rev 2: 3 commits, Dec 2015 → Dec 2016.

Early Rev 1 snapshots (Aug–Oct 2013) also contain the ATX PSU sub-board and some experimental logic (CPLD, FPGA, USB, MSX slot) in the same schematic and board. These were removed before the Rev 1.0 release.

## Things to check (TODO)
- **Rev 2 reference divider:** in the Rev 2 schematic, R1 (pins 1 and 3), R9 pin 1 and R10 pin 1 have no net. On the Rev 2 board they are joined by tracks that carry no net. Check the divider against Rev 1, where it is wired R9–R1–R10 in the schematic.
- **Net name for +16 V:** the +16 V input (P1 pin 3, bus pin 2) is named `+18_V` in the schematic, while the silkscreen says +16V.

## Credits
- **N8VEM S-100 backplane v02 (Andrew Lynch, N8VEM).** This design started from that KiCad project, an 8-slot backplane. The two share the active-terminator section with the same reference designators and values. The S-100 connector symbol is from the N8VEM-KiCAD library.
- **Godbout Electronics / CompuPro Active Terminator (1981).** The termination circuit follows this design: LM4250, 2N3904/2N3906, D44C/D45C, trimpot, 270 Ω bus resistors. The same circuit is used on the N8VEM and S100Computers.com (John Monahan) backplanes.

## License
Hardware: CERN-OHL-S-2.0 for the original work in this folder. See the repo NOTICE for third-party parts.

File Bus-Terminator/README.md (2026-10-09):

# S100 Bus Terminator

"S100 BUS TERMINATOR / REV 1.0": a plug-in active bus terminator card for an S-100 system (2014).

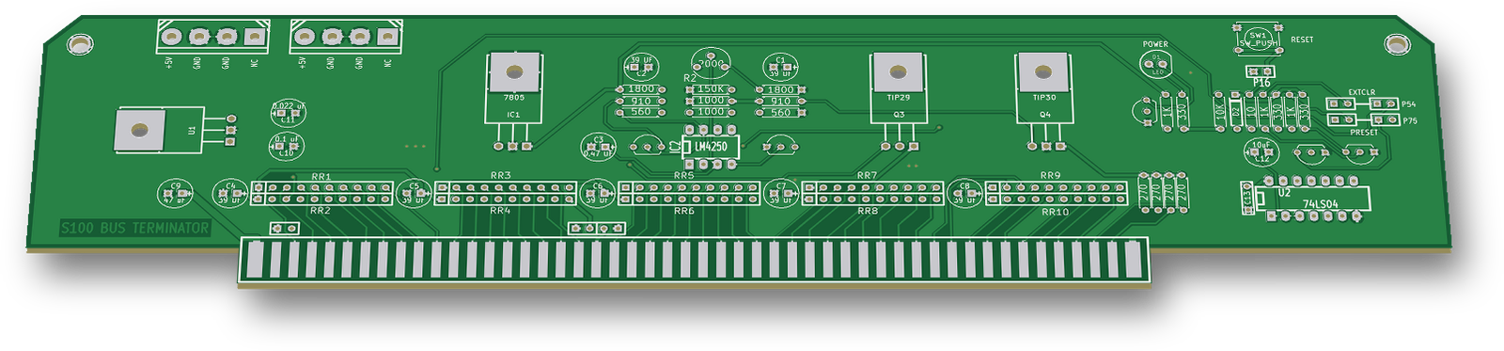
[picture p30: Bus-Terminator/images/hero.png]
S100 Bus Terminator


 

## Status

Built. The fab gerbers are in `GERBERS/` and are dated 3 August 2014. They include top/bottom copper, top silkscreen, both masks, Edge.Cuts and an Excellon drill file. There is no bottom silkscreen layer.

## Hardware

| Ref | Part | Role |
|---|---|---|
| IC2 | LM4250 (8-DIP) | Micropower op-amp, voltage follower for the termination rail `Vacc` |
| Q1 / Q2 | 2N3906 / 2N3904 | Driven from the LM4250 supply pins |
| Q3 / Q4 | TIP29 / TIP30 (TO-220) | Push-pull pass pair: sources from +8 V and sinks to GND |
| R2 | 2 kΩ trimmer | Sets `Vacc` (divider R1/R2/R3 = 1800/2000/1800 Ω on +5 V) |
| RR1–RR10 | 9 × 270 Ω SIP networks | Line terminations to `Vacc` |
| R19–R22 | 270 Ω | Terminations on pins 48, 49, 98, 99 |
| IC1 | 7805 (TO-220) | +5 V for the logic and the reference |
| U1 | 5 V regulator (TO-220) | Separate +5 V for P2/P3 |
| P2, P3 | 4-pin Molex drive-power headers | +5V / GND / GND / NC |
| U2 | 74LS04 | Reset buffer |
| Q5, Q6, Q7 | 2N3904 | POWER LED driver; /PRESET and /EXTCLR open-collector drivers |
| C4–C8 | 39 µF | Rail decoupling |

- **Board:** 2-layer, 10.0 × 2.0 in (254.0 × 50.8 mm) plus the edge-finger tab, 2.3 in (58.4 mm) overall. There is a ground pour on both layers.
- **Silkscreen labels:**
  - RESET (SW1) and P16 (2-pin header for an external reset button);
  - POWER (D1);
  - PRESET / P75 and EXTCLR / P54 (output jumpers);
  - +5V (P2, P3).
- **Jumpers:**
  - JP1 / JP3 / JP2 tie S-100 pins 20 / 70 / 53 to GND;
  - JP4 + JP7 route the reset to /PRESET (pin 75);
  - JP5 + JP6 route the reset to /EXTCLR (pin 54).
- **Tools:** KiCad (2013-07-07 BZR 4022)-stable, legacy `.sch` / `.brd` format.

## How it works

- **Termination rail:** a 270 Ω resistor connects each of 94 S-100 lines to `Vacc`. That is every pin except +8 V (1, 51), ±16 V (2, 52) and GND (50, 100).
- **Rail control:** the LM4250 follows the trimmer voltage, and its supply-pin currents drive Q1/Q2, which drive Q3/Q4. The rail can therefore both source and sink current. With these divider values the trimmer covers about 1.6–3.4 V.
- **Power:** +8 V from the bus feeds IC1 (logic and reference) and U1 (the two drive-power headers).
- **POWER LED:** D1 lights whenever the +5 V logic supply is present.
- **Reset:**
  - SW1 or P16 discharges a 10 kΩ / 10 µF power-on delay, with D2 as the discharge diode.
  - Two 74LS04 gates buffer it.
  - Q6/Q7 then pull /PRESET and/or /EXTCLR through the jumpers.
- The same active-terminator circuit was earlier part of the 18-slot backplane Rev 1.0 (see `../Backplane-18-Slot/`).

## Files

| Path | Contents |
|---|---|
| `S100_Bus Terminator.sch` | Schematic (KiCad legacy) |
| `S100_Bus Terminator-cache.lib` | Symbol cache. Needed to open the schematic in newer KiCad (Remap Symbols) |
| `S100_Bus Terminator.brd` | PCB (KiCad legacy) |
| `S100_Bus Terminator.pro` | KiCad project |
| `S100_Bus Terminator.net`, `.cmp` | Netlist and footprint assignments |
| `GERBERS/` | Fab gerbers and drill file |

## History

The git history replays the original dated backups from 3 August 2014 (11:53 to 13:25 NZST): placement, then re-placement, then the routed board with gerbers.

## Things to check (TODO)

- **Reset polarity:** U2 has two inverters in series (pins 1→2→3→4), so its output follows the RC node. That node is high when the button is released. Check whether Q6/Q7 then conduct and hold /PRESET and /EXTCLR low while JP4/JP7 or JP5/JP6 are fitted.

## Credits

- **Termination circuit:** Godbout Electronics / CompuPro S-100 "Active Terminator" (Bill Godbout Electronics; CompuPro board © 1980). This card has the same LM4250 reference with a complementary-transistor booster, the same component values (1.8 k / 2 k trimmer / 1.8 k, 150 k, 560 Ω, 910 Ω, 39 µF) and the same count of 94 × 270 Ω terminations, with renumbered reference designators.
- **KiCad library parts:** some come from the N8VEM KiCad library: the op-amp symbol used for the LM4250 (`o_analog.lib`) and the `molex-drive-connector` footprint.

## License

Hardware: CERN-OHL-S-2.0 for the original work in this folder; see the repo NOTICE for third-party parts.

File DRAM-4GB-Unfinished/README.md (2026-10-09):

# 4GB DRAM Board (4Mem v2): unfinished

A Spartan-6 XC6SLX45 + DDR3 DIMM mezzanine for the [x86 32bit Memory Adapter Board](../x86-Memory-Adapter/). It plugs onto the adapter's P8/P9 headers and isn't an S-100 card itself (2015).

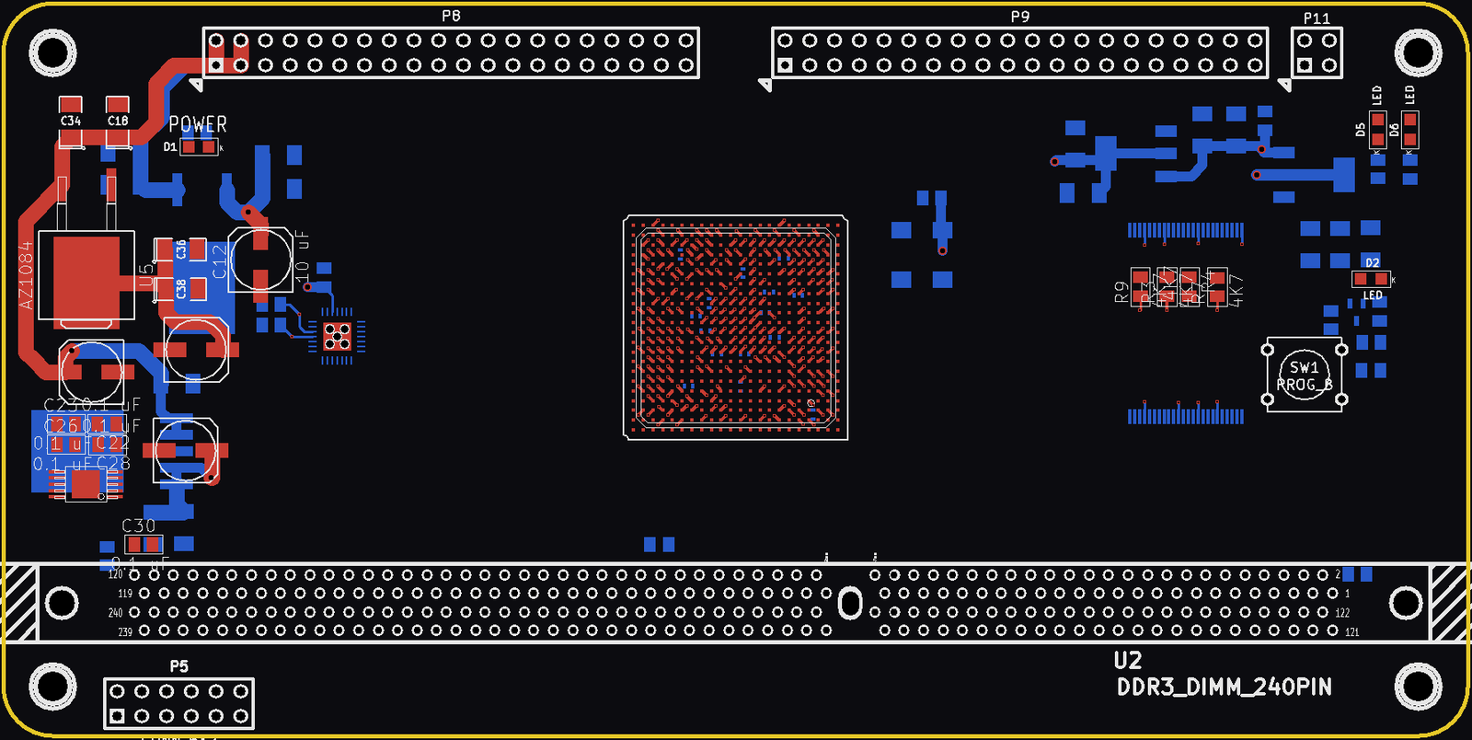
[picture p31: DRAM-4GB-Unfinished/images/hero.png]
4GB DRAM Board


 

## Status
**Unfinished: schematic and placed, partly routed PCB only. It was never routed or built.**
- The `GERBERS/` folder in the original project is empty.
- None of the 124 DDR3 nets or the 74 P8/P9 signal nets has a track. The PCB file reports 478 unrouted connections.
- The board has no title or revision text.

## Hardware
| Ref | Part | Role |
|---|---|---|
| U1 | XC6SLX45-2FGG484C | FPGA, DDR3 interface to the adapter board |
| U2 | 240-pin DDR3 DIMM socket | 64-bit unbuffered DIMM, 2 ranks |
| U3 | XCF08P (TSOP48) | FPGA configuration flash |
| U12 | PIC18F2520 (QFN28) | on the DIMM SPD I2C bus, 6 lines to the FPGA |
| U9 | oscillator | FPGA clock into ball M3 (GCLK); a 62.5 MHz 2.5 V part in `digikey.xlsx` |
| U5 | AZ1084 | 3.3 V from +8 V |
| U6 | NCP565 | 1.2 V (FPGA core) |
| U7 | LT1764EQ-1.5 | 1.5 V DIMM supply |
| U8 | RT9026 | DDR3 VTT / VREF |
| U4, U10 | LM1117-1.8, LM1117-2.5 | XCF08P core, oscillator |
| P8, P9 | 2x20 headers | to the x86 32bit Memory Adapter Board |
| P11 | 2x2 header | JTAG (TDI, TDO, TMS, TCK) |
| P5 | 2x6 header | PIC programming (MCLR/PGD/PGC) and UART (TX/RX) |
| SW1 | push button | FPGA PROG_B |
| D1, D2 | LEDs | POWER, FPGA DONE (via Q1) |

- Board: 150.4 x 75.2 mm, rounded corners, four corner mounting holes, 6 copper layers (Top, GND, Sig1, Sig2, POWER, Bottom).
- KiCad (2013-07-07 BZR 4022)-stable.

## How it works (as drawn)
- **P8/P9:** these carry 72 FPGA I/O lines plus +8 V (P8 pins 1–4) and GND (P9 pins 39–40). The pins and positions match P8/P9 on the [x86 32bit Memory Adapter Board](../x86-Memory-Adapter/): its 32-bit data bus (bD0–31), address bA2–22 and CPLD lines.
- **DDR3:** the FPGA connects to the whole DIMM interface: A0–A15, BA0–2, DQ0–63, DQS0–7, DM0–7, CK0/CK1, CKE0/1, S0/S1, ODT0/1, RAS/CAS/WE.
- **Configuration:** the FPGA boots from the XCF08P (D0–D7, CCLK), which shares the JTAG chain with the FPGA. SW1 pulls PROGRAM_B.
- **DIMM reset:** FPGA DONE drives the DIMM RESET# pin (through R8, 0 Ω) and the DONE LED.
- **PIC18F2520:** reads the DIMM SPD EEPROM (SCL/SDA, 10K pull-ups) and has 6 lines to the FPGA.
- **Power:** the board makes all its rails from the +8 V on P8.

## Files
| File | What it is |
|---|---|
| `4Mem board v2.sch` | schematic (single sheet) |
| `4Mem board v2-cache.lib` | symbol cache |
| `4Mem board v2.kicad_pcb` | PCB (placed, partly routed) |
| `4Mem board v2.pro` | KiCad project |
| `4Mem board v2.net`, `.cmp` | netlist and footprint assignments |
| `digikey.xlsx` | DigiKey parts list (NZD), including parts for the sibling SRAM/adapter boards |

There is no FPGA project for this board.

## History
- The git history replays the original dated backups, from 2015-05-03 to 2015-06-21.
- The project started as a copy of the [4Mbit (128K x 32) SRAM module](../x86-Memory-Adapter/sram-module/). It has the same outline and P8/P9 positions, and the module's "4Mbit (128K x 32)" text is still in the PCB file, outside the board edge.
- The last file activity is an autorouter (Specctra `.dsn`) export of the same PCB on 2016-12-06. It isn't included.

## Things to check (TODO)
- **FPGA supplies:** nets `/V1.2temp`, `/V1.5temp` and `/V3.3temp` are not joined to the regulator outputs `/V1.2`, `/V1.5` and `/V3.3`.
- **U4/U10 input:** `/+8Vitemp`, the input to U4 and U10, is not joined to `/+8Vi`.
- **XCF08P supply:** the XCF08P I/O supply is on a separate net, `/V3.3temp2`.
- **Loose pins:** one side of LEDs D5 and D6, and the PIC PGM pin, are unconnected.
- **DDR3 balls vs memory controller:** the DDR3 balls don't follow the Spartan-6 hard memory controller (MCB) pinout. For example, A0 is on G19, an M1A10 ball. The 64-bit DIMM is also wider than one MCB.
- **Net name:** `/DDR3_OFT1` is the DIMM ODT1 signal.
- **JTAG header:** P11 has no GND or VREF pin.
- **Schematic title block:** it still says "noname.sch".
- **Copper planes:** no copper zones are poured on the GND or POWER layers.

## Credits
- The DDR3 pin assignment follows a Spartan-6 DDR3 UDIMM reference document.
- The FPGA symbol comes from the author's own KiCad library.

## License
Hardware: CERN-OHL-S-2.0 for the original work in this folder; see the repo NOTICE for third-party parts.

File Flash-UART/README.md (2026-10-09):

# RS232 | TMA | Serial Flash Board Rev 1.0

An S-100 board with a USB serial port (16550 + FT232R), four TMA* bus-master request lines, and four SPI flash chips. The flash chips can be loaded from a PC over USB and then read from the S-100 side (2014–2015).

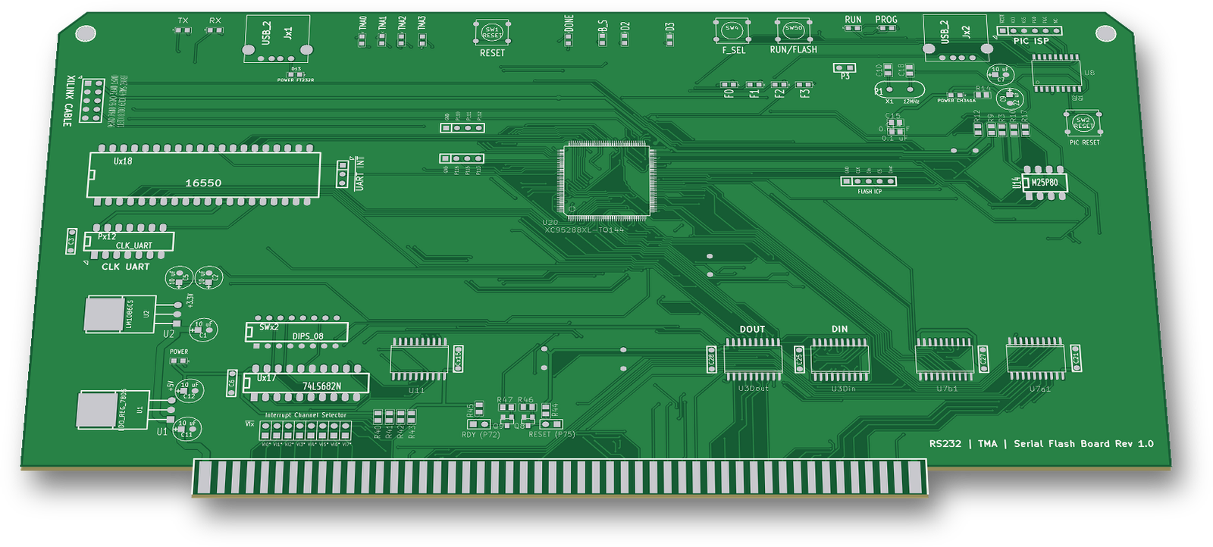
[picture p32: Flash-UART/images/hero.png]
RS232 | TMA | Serial Flash Board Rev 1.0


 

The idea is fast development turnaround:
1. Program the SPI flash chips from a PC through the CH341A.
2. Flip the RUN/FLASH switch.
3. An S-100 monitor/loader reads the flash contents into RAM through the CPLD's I/O ports.

The S-100 monitor/loader and the PIC18F1330 firmware are **not** in this repo.

## Status
Built. The gerbers are dated 16 Apr 2014 (`GERBERS/`). The CPLD design was brought up in June 2014 and revised in July and December 2015.

## Hardware
| Ref | Part | Role |
|---|---|---|
| U20 | XC95288XL-TQ144 | CPLD: S-100 glue, port decode, SPI bit-bang registers, flash chip select |
| Ux18 | 16550 | UART (clock from oscillator socket Px12 "CLK UART") |
| Ux21 | FT232R | USB to serial for the UART (Jx1) |
| U18 | CH341A | USB to SPI flash programmer (Jx2, 12 MHz crystal X1) |
| U14–U17 | M25P80 | SPI flash chips on a shared bus (U14 on top, U15–U17 on the bottom) |
| U12 | 74LV244 | Switches the flash bus between the CPLD and the CH341A |
| U8 | PIC18F1330 | Reads the RUN/FLASH and F_SEL switches and drives the U12 enables |
| Ux17 | 74LS682N | UART I/O address compare against DIP switch SWx2 |
| U3din1, U3dout1 | 74LS541 | S-100 DO → local data bus, local data bus → S-100 DI |
| U4, U5, U6 | 74LS541 | Address buffers A0–A23 |
| U11 | 74LS541 | TMA0*–TMA3* drivers |
| U19 | 74LS541 | Puts the flash data-out bit on local D0 |
| U7a1, U7b1 | 74HC245 | S-100 status/control input buffers |
| U2, U1, Ux1 | LM1086CS, 7805, 3.3 V SOT-223 | Power |

- **Board:** 10.0 × 5.0 in (254 × 127 mm), plus the S-100 edge-connector tab.
- **KiCad:** pcbnew `(2013-07-07 BZR 4022)-stable`, legacy schematic format (`EESchema Schematic File Version 2`).
- **CPLD tools:** Xilinx ISE 14.7 (`P.20131013`), XC95288XL-10-TQ144.
- **Switches:** RESET (SW1), PIC RESET (SW2), F_SEL (SW4), RUN/FLASH (SW50), DIP switch SWx2 (UART address: A3–A7 on sw 1–5, IORQ on sw 6, sw 7 and 8 to GND).
- **LEDs:** TMA0–TMA3, DONE, B_S (board select), D2, D3, F0–F3 (flash selected), RUN, PROG, TX, RX, and power LEDs for the board, the FT232R and the CH341A.
- **Headers:**
  - XILINX CABLE (JTAG), PIC ISP, FLASH ICP (GND, CLK, Din, CS, Dout on the CH341A side), UART INT
  - CPLD I/O (P10: P110–P112, P2: P113/P115/P116)
  - RDY (P72), RESET (P75)
  - Interrupt Channel Selector (VI0*–VI7*)

## How it works
- **I/O request:** the CPLD makes IOREQ from sINP OR sOUT and passes it to the 74LS682. When A7–A3 and IOREQ match SWx2, the 74LS682 selects the 16550. A2–A0 go straight to the UART. The CPLD makes the UART's RD*/WR* strobes from pDBIN/pWR* and drives the two data-bus buffers.
- **SPI flash ports:** the CPLD decodes ports 90h–97h. A3 is not decoded, so 98h–9Fh mirror them. Each write latches D0, except port 96h, which takes D0–D2.

  | Port | Function |
  |---|---|
  | 90h | CLK |
  | 91h | Din (data to flash) |
  | 92h | CS |
  | 93h | read flash data-out on D0 |
  | 94h | DONE LED |
  | 95h | bit 0: flash select source |
  | 96h | bits 2..0: flash number |

  A loader bit-bangs SPI through these ports.
- **Flash chip select:** the CS from whichever side owns the bus (CPU or CH341A) goes through a 3-to-8 decoder in the CPLD to FLASHSEL0–3 (U14–U17). LEDs F0–F3 show which chip is selected.
  - After reset (port 95h bit 0 = 0) the selection is U16. A note in the CPLD schematic says this position was used for a 256 KB 25L020 "for quick programming".
  - With bit 0 = 1, port 96h picks the chip.
  - In the 2014 CPLD versions the PIC chose the chip instead, through lines PIC18F_0..2.
- **CH341A or S-100:** all four flash chips share CLK/Din/Dout. One half of the 74LV244 connects them to the CPLD, the other half to the CH341A and the FLASH ICP header. The PIC18F1330 enables one half or the other, following the RUN/FLASH switch. At power-up the CPLD (S-100) side has the bus.
- **TMA:** an OUT to port **EEh** latches D0–D3 onto TMA0*–TMA3* (S-100 pins 55, 56, 57, 14) through U11. In U20v2 a 1 asserts the line (low), and reset leaves all four lines high.
- **Reset:** S-100 SLAVE_CLR*, the RESET button or a PIC line clears the CPLD registers and resets the UART. The RESET button also pulls S-100 RESET* (pin 75) through Q8 and jumper JP4.
- **UART:** the 16550's TTL serial lines (SIN, SOUT, RTS, CTS, DTR, DSR) go to the FT232R and USB socket Jx1. The UART interrupt goes to the "UART INT" jumper.

## Files
| Path | What |
|---|---|
| `S100_B1FU.sch`, `S100_B1FU-cache.lib`, `S100_B1FU.pro` | KiCad schematic, symbol cache, project |
| `S100_B1FU.kicad_pcb` | KiCad PCB |
| `S100_B1FU.net`, `S100_B1FU.cmp` | Netlist and component/footprint list |
| `GERBERS/` | Fabrication gerbers and drill file (16 Apr 2014) |
| `cpld/U20v2.sch` | Current CPLD schematic (Xilinx ISE schematic, XML) |
| `cpld/U20v1.sch` | Previous CPLD schematic (July 2015) |
| `cpld/pinmap.ucf` | CPLD pin constraints |
| `cpld/S100BFURev1/S100BFURev1.xise` | ISE project (top: `../U20v2.sch`, constraints `../pinmap.ucf`) |
| `cpld/S100BFURev1/U20v1.jed`, `U20v2.jed` | Programming files |
| `cpld/outdated/` | The first U20 test schematic and pin map (May 2014) |

## History
The git history replays the original dated backups of the KiCad project and the CPLD project, from April 2014 to December 2015.

## Things to check (TODO)
- On the PCB, 16550 (Ux18) pins 18 (WR*), 21 (RD*) and 35 (MR) have no net. The CPLD's RD, WR and RESET outputs (pins 113, 116, 115) only go to header P2. Check the wiring from P2 to the UART.
- CPLD pin 39 (`IOREQtoUx17`, an output) and U7a1 pin 6 (74HC245 output from S-100 pin 69) are on the same net (`/IOREQbb`). Check that only one of them drives it.

## Credits
- The UART section (16550 and FT232R with TTL serial labels, and its schematic notes) follows the N8VEM ECB SBC V2 schematic. Credit to Andrew Lynch and the N8VEM project.
- KiCad symbol libraries include N8VEM community libraries.

## License
Hardware: CERN-OHL-S-2.0 for the original work in this folder; see the repo NOTICE for third-party parts. The bottom-copper text "© 2014 Antony Burrows ALL RIGHTS RESERVED" is left as fabricated; this license applies.

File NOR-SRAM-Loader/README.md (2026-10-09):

# 8Mb Serial NOR to 1MB SRAM Loader (CPLD only)

A Xilinx CPLD design (U11) for an S-100 board that would load a serial NOR flash into 1 MB of SRAM, 2014. The board itself was never laid out; only the CPLD files exist.

## Status
Not built: there is no schematic or PCB for the board. The CPLD design was compiled to a JED file (`cpld/U11/U11v3.jed`, 2014-07-22).

## Hardware (from the pin map)
- **CPLD:** U11, XC9572XL-10-TQ100. Xilinx ISE 14.7 project `cpld/U11/U11.xise`.
- **Planned parts, as named in `cpld/pinmap.ucf`:**
  - a UV EPROM (`CPLDP12ROM1OE`, `CPLDP92ROM1CS`);
  - a second ROM/RAM with two banks (`ROM2_0_CS`, `ROM2_1_CS`, `ROM2_OE`, `ROM2_WE`);
  - a 25P80 serial NOR flash (`NOR_CLK` P93, `NOR_DIN` P95, `NOR_CS` P96, `NOR_DOUT` P97);
  - a 74LS682 board-select input (`BOARDSELECT` P41);
  - data-bus buffer enables;
  - LEDs: board select, ROM, SRAM, and "Board load to Memory DONE".
- **S-100 inputs:** A0–A15, A20–A23, D0–D7, sM1, sOUT, sINP, sMEMR, MWRT, pWR*, pDBIN, sWO*, PHI, CLOCK, SLAVE_CLR*.

## How it works
- **v1 and v2** (`U11v1.sch`, `U11v2.sch`) carry I/O port notes for a bit-banged SPI link to the NOR flash: 0x80 CLK, 0x81 data system→NOR, 0x82 CS, 0x83 data NOR→system. They also note "Low When 0x80-0x8F RW".
- **v3** (`U11v3.sch`, the one the ISE project builds) contains:
  - the UV EPROM select: active on a memory read with A12–A15 and A20–A23 all low (the lowest 4 KB). It also enables the data-out buffer and the board-select LED.
  - a "DONE" LED flip-flop, loaded from D0 by an OUT to port 0x70 and cleared by SLAVE_CLR*.
- In v3, the `ROM2_*` outputs are tied inactive, and the `NOR_*` outputs have no driver.

## Files
- `cpld/U11v1.sch`, `cpld/U11v2.sch`, `cpld/U11v3.sch`: ISE schematics, three versions.
- `cpld/pinmap.ucf`: pin map ("PIN MAP OF U11 on 8Mb Serial NOR to 1MB SRAM board").
- `cpld/U11/U11.xise`: ISE project (builds `U11v3.sch`).
- `cpld/U11/U11v3.jed`: programming file.

The pin map of this design was also the starting template for the CPLD of the [8MB SRAM Board](../SRAM-8MB/).

## History
The git history replays the original files of this design, 2014-04-02 to 2014-07-22.

## License
Hardware: CERN-OHL-S-2.0 for the original work in this folder; see the repo NOTICE for third-party parts.

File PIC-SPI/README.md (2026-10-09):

# PIC-SPI

An S-100 interrupt and SPI board: an 8259A interrupt controller on the bus vectored-interrupt lines, an XC95288XL CPLD driving an SPI bus (DS1305 RTC, two MCP23S08 port expanders) and eight M25P80 SPI flash chips that can be loaded over USB (2016). The project name is `S100 PIC_SPI_v1`; the board carries no title text.

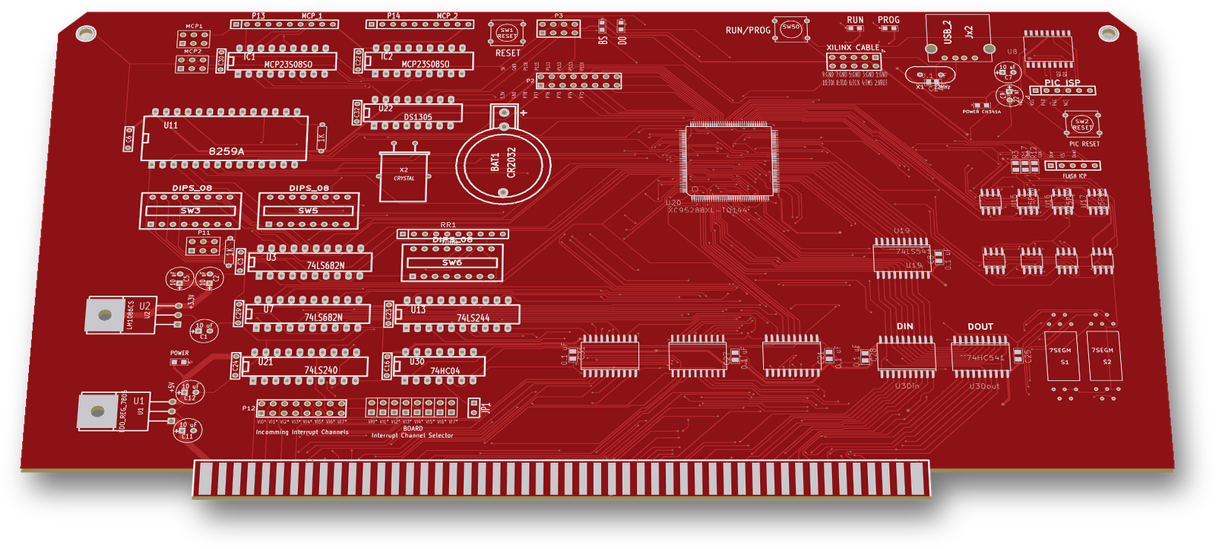
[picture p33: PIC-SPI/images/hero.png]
PIC-SPI


 

## Status
Built.

## Hardware

| Ref | Part | Role |
|---|---|---|
| U20 | XC95288XL-TQ144 | CPLD: S-100 bus logic, chip selects, SPI master, flash select, 7-segment data |
| U11 | 8259A | Interrupt controller on VI0*–VI7*, output to INT* |
| U22 | DS1305 + X2 + BAT1 (CR2032) | SPI real-time clock with battery backup |
| IC1, IC2 | MCP23S08 | SPI 8-bit port expanders, brought out on P13 "MCP_1" and P14 "MCP_2" |
| U14–U17, U23–U26 | M25P80 ×8 | 8 Mbit SPI flash each, one select line per chip from the CPLD |
| U18 | CH341A (12 MHz X1, USB Jx2) | USB-to-SPI bridge for loading the flash |
| U8 | PIC18F1330 | Switches the flash SPI bus between the CPLD and the CH341A |
| U12 | 74LV244 | Flash SPI bus switch, enabled by the PIC18F1330 |
| U3, U7 | 74LS682 | Address compare against DIP switches SW3 and SW5 (U7 → 8259 select) |
| U21 | 74LS240 | Inverts VI0*–VI7* to the 8259 IR0–IR7 inputs |
| U13 + SW6 | 74LS244 + DIP switch | Interrupt vector byte set by switch, put on the bus by the CPLD |
| U27, U28 + S1, S2 | 74HC4511 ×2 + 7-segment ×2 | Two-digit display driven by the CPLD |
| U4–U6, U19, U31, U3din1, U3dout1, U9, U10 | 74xx541 / 74HC245 | S-100 address, data and status buffers |
| U1, U2, Ux1 | 7805-type LDO, LM1086CS, 3.3 V SOT-223 | +5 V and 3.3 V from the S-100 +8 V rail |

- Board size: 254.0 × 134.1 mm (10.0 × 5.28 in), standard S-100 outline, 2 layers.
- KiCad: 2013-07-07 stable (BZR 4022); `.kicad_pcb` format version 3.
- Headers: P12 "Incomming Interrupt Channels" (jumpers route each VIx* line to 8259 IRx); JPx1–JPx8 "BOARD Interrupt Channel Selector" (picks the VIx* line for the board's own interrupt); JP1 (8259 INT to S-100 INT*); P19 "XILINX CABLE" (JTAG); P5 "PIC ISP"; P1 "FLASH ICP" (GND/CLK/Din/CS/Dout); P3 "EXT SPI"; P2 spare CPLD I/O.
- Switches: SW1 "RESET", SW2 "PIC RESET", SW50 "RUN/PROG"; DIP switches SW3, SW5 (address) and SW6 (interrupt vector).
- LEDs: "RUN", "PROG", "BS" (board select), "D0", "POWER", "POWER CH341A".

## How it works
- The CPLD sits behind buffered S-100 address (A0–A23), data (DI0–DI7, DO0–DO7) and status/control lines (sINP, sOUT, sMEMR, sM1, sINTA, sWO*, pDBIN, pWR*, MWRT, PHI, CLOCK*, RESET*, SLAVE_CLR*).
- Interrupts: incoming VI0*–VI7* reach the 8259A IR inputs through P12 jumpers and a 74LS240; the 8259A INT output goes to S-100 INT* (pin 73) through JP1. The 8259A chip select is decoded by U7 (CPLD pin 69 `in8259CS*`) and driven back out by the CPLD (pin 70 `out8259CS*`).
- The CPLD can also raise its own interrupt (pin 110 `BOARD_INTERRUPT_VECTb`) on any one VIx* line chosen with JPx1–JPx8, and can put a switch-set vector byte (SW6 via U13) on the data bus.
- SPI: CPLD pins 57/58/59 are SPI CLK/Din/Dout to the DS1305, both MCP23S08s and P3. Chip selects come from CPLD pins 25 (DS1305), 26/27 (IC1/IC2) and 17 (P3).
- Flash: the eight M25P80s share one SPI bus with a separate select each (CPLD pins 80–83 and 85–88). The 74LV244 connects that bus either to the CPLD or to the CH341A USB bridge; the PIC18F1330 controls which.
- The CPLD can also drive the S-100 bus-master request lines TMA0*–TMA3* and sXTRQ*.
- No CPLD project for this board is in the backups.

## Files
All files are in this folder:

| File | What it is |
|---|---|
| `S10_PIC_SPI_v1.sch` | Schematic (single sheet) |
| `S10_PIC_SPI_v1-cache.lib` | Symbol cache for the schematic |
| `S10_PIC_SPI_v1.kicad_pcb` | PCB layout |
| `S10_PIC_SPI_v1.net` | Netlist |
| `S10_PIC_SPI_v1.cmp` | Footprint assignments |
| `S10_PIC_SPI_v1.pro` | KiCad project |

## History
The git history replays the original dated KiCad backups, 3–10 January 2016. The first commit is the Flash-UART layout with its tracks removed, and the Flash-UART netlist and footprint files are carried over unchanged.

## Things to check (TODO)
- The P2 header silkscreen labels (P71–P78, P110–P116) are Flash-UART net names; on this board those pins go to CPLD pins 105–100 and 93–98.
- The final layout reports 1 unrouted connection.

## Credits
- Started from the user's own [Flash-UART](../Flash-UART) design.
- The S-100 edge connector symbol (`S100_MALE`) comes from the N8VEM KiCad library.
- John Monahan's 8259A test programs for his S100Computers.com PIC/RTC board (2010) were kept in the original project folder as reference. They are not included here.

## License
Hardware: CERN-OHL-S-2.0 for the original work in this folder; see the repo NOTICE for third-party parts.

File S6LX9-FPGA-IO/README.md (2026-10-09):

# S6LX9 FPGA & I/O Board

An S-100 I/O card built around a Xilinx Spartan-6 XC6SLX9 FPGA, with a DS1302 real-time clock and serial RAM/flash (2013–2015). The original KiCad project is `TMRINT`, in a folder called `FPGA_TIMER_INT_CONTROLLER`. The gateware in this repo is an I/O-port and DS1302 test, not a timer or interrupt controller.

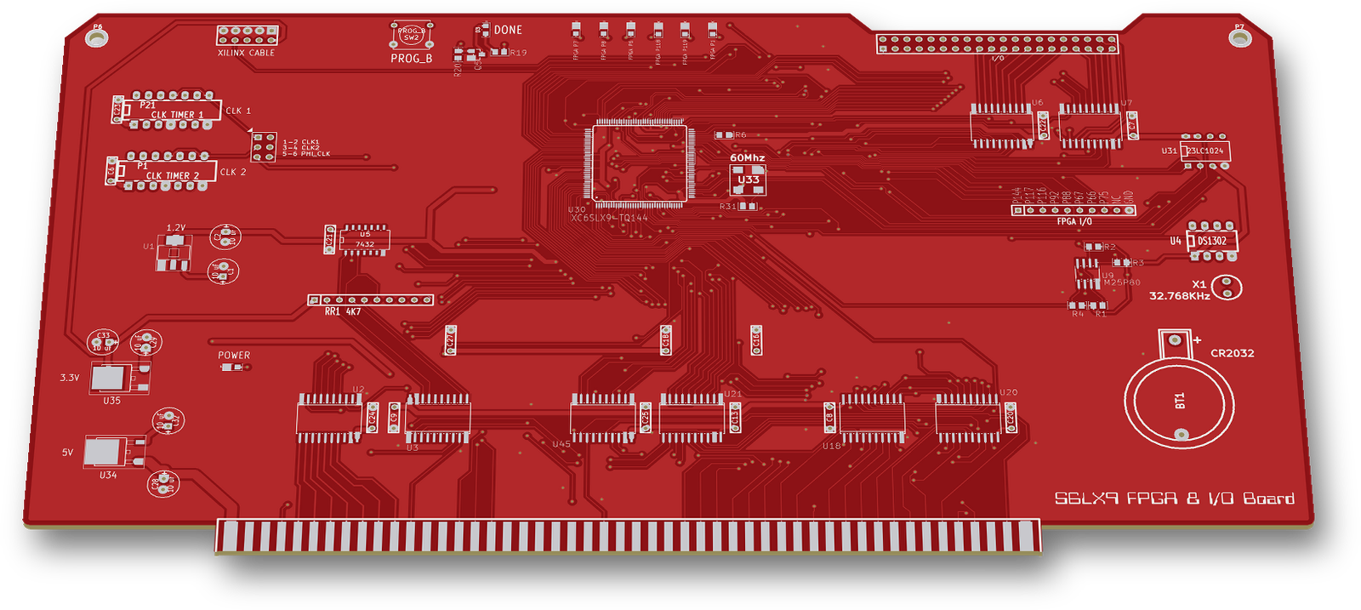
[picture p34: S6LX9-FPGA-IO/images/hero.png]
S6LX9 FPGA & I/O Board


 

## Status

**Built.** Gerbers (7 layers + drill) and a BOM were generated on 11 March 2014. The FPGA bitstream and PROM files were built in June 2014 and August 2015.

Silkscreen:
- top: "S6LX9 FPGA & I/O Board";
- bottom: "S6LX9 FPGA I/O / RTC Serial RAM Board / © Antony Burrows 2014 / ALL RIGHTS RESERVED".

## Hardware

| Ref | Part | Role |
|---|---|---|
| U30 | XC6SLX9-TQ144 | Spartan-6 FPGA |
| U32 | XCF02S | FPGA configuration PROM (see *Things to check*) |
| U9 | M25P80 | 8 Mbit SPI NOR flash |
| U31 | 23LC1024 | 1 Mbit SPI SRAM |
| U4 | DS1302 | Real-time clock (X1 32.768 kHz, BT1 CR2032 backup) |
| U33 | 60 MHz oscillator | FPGA clock (U30 pin 51) |
| P21, P1 | DIL14 sockets "CLK TIMER 1/2" | Oscillator sockets, selected by jumper P25 (1-2 CLK1, 3-4 CLK2, 5-6 PHI_CLK) |
| U2, U6, U7, U8, U20, U21, U22, U24, U27, U45 | 74LVC245 | 3.3 V buffers between the S-100 bus and the FPGA |
| U3, U18 | 74HC245 | Bus buffers (VI0\*/NMI\*/RESET\*/RDY outputs; DO bus) |
| U5 | 7432 | OR gate (RESET\* drive gated by the FPGA DONE signal) |
| U34 / U35 / U1 | 7805 / LM1086 / SOT-223 regulator | 5 V / 3.3 V / 1.2 V from the S-100 +8 V rail |

- **Board size:** 254.0 × 133.2 mm (10.0 × 5.0 in plus the edge-finger tab), the standard S-100 card.
- **KiCad:** Pcbnew (2013-07-07 BZR 4022)-stable; legacy `.sch`/`.brd` formats.
- **Headers and controls:** XILINX CABLE (P20, JTAG), PROG_B push-button (SW2), DONE and POWER LEDs, six FPGA LEDs labelled "FPGA P7, P8, P6, P118, P119, P1", the "FPGA I/O" test header P3 (P144 P117 P116 P92 P88 P67 P66 P75 NC GND), and a 40-pin "I/O" header P2 (internal D0–D7 plus spare I/O).
- **S-100 signals buffered to the FPGA:** A0–A23; sOUT, sINP, sMEMR, sM1, MWRT, SLAVE_CLR\*; pDBIN, pWR\*, sWO\*, CLOCK\*, PHI; VI1\*–VI7\*. Outputs through U3: VI0\*, NMI\*, RESET\*, RDY.

## How it works

The FPGA design (`fpga/U30v3.sch`, an ISE 14.7 schematic for xc6slx9-3 tqg144, pins in `fpga/pinmap.ucf`) is gate-level logic:

- **Address decode:** A7–A0 only, for ports **F0h** and **F1h**. The I/O write strobe is sOUT · pWR\*.
- **OUT F0h:** latches D0–D5 into the six FPGA LEDs (P7, P8, P6, P118, P119, P1).
  - On the board, U3 also routes P7 to **VI0\*** and P6 to **NMI\***. P8 is ORed with DONE in U5 and goes to **RESET\***.
  - So bits of port F0h also drive those S-100 lines.
- **OUT F1h:** bit-bangs the DS1302. D4 = CE/RST (pin P61), D6 = SCLK (P64), D7 = data out, and D5 = DQ tristate control (DQ on P62).
- **IN F1h:** returns the DS1302 DQ bit on D0.
- **Bus buffers:**
  - `DBUSIN` (P2) enables U18 on the S-100 DO lines when F0h/F1h is addressed.
  - `DBUSOUT` (P5) enables U20 on the DI lines during an IN from F1h.
  - `U8DIR` (P74) controls the internal data buffer U8.
- **Other outputs:** CLK1 (P85, from the CLK_SEL jumper) ÷ 16 appears on P144. Write strobes and bus signals go to the P3 test header.
- **Reset:** SLAVE_CLR\* (P97) clears all latches.
- **Not used by the gateware:** the 23LC1024, M25P80 and 60 MHz oscillator.

Gateware versions:
- `U30v1.sch` (2014-06): F0h LEDs only.
- `U30v2.sch` (2015-08-01): the buffer enable is also qualified by pWR\*.
- `U30v3.sch` (2015-08-08): adds the DS1302 port at F1h. This is the version the project builds.

## Files

| Path | What |
|---|---|
| `TMRINT.sch`, `TMRINT-cache.lib` | KiCad schematic and its symbol cache |
| `TMRINT.brd` | KiCad PCB |
| `TMRINT.net`, `TMRINT.cmp`, `TMRINT.pro` | Netlist, component/footprint list, project file |
| `GERBERS/` | Fabrication gerbers and drill file |
| `BOM/TMRINT.csv` | Bill of materials |
| `fpga/U30v1.sch`, `U30v2.sch`, `U30v3.sch` | Xilinx ISE schematics for U30 |
| `fpga/pinmap.ucf` | U30 pin constraints |
| `fpga/TIMER_INT1/TIMER_INT1.xise` | ISE 14.7 project (top `U30v3`; sources referenced as `../U30v3.sch`, `../pinmap.ucf`) |
| `fpga/u30v3.bit` | Final bitstream |
| `fpga/U30v3.prm` | PROM map with the `promgen` command used to make the PROM image |

## History

The git history replays the original dated backups of the KiCad project and the ISE project, from November 2013 to August 2015.

## Things to check (TODO)

- **U18, U20 and U8:**
  - They are drawn as 74HC245/74LVC245 (BOM too), but each has DIR (pin 1) tied to /OE (pin 19), which is the wiring for a 74x541.
  - Check which way data passes (U18: S-100 DO ↔ internal D; U20: internal D ↔ S-100 DI; U8: internal D ↔ FPGA) against the part actually fitted.
  - U18 was a 74LS541 in the schematic until November 2013, and the UCF comments still say "541".
- **Configuration PROM:** U32 is an XCF02S in the schematic and BOM. `fpga/U30v3.prm` was generated for an XCF04S, and the XC6SLX9 bitstream (about 2.7 Mbit) is larger than an XCF02S holds.
- **IN F1h:** check the polarity of the D0 IOBUF tristate control in `U30v3.sch`. As drawn, it is the inverse of `DBUSOUT`, which tristates D0 during the read.

## Credits

The board and gateware are original work. Some KiCad symbols come from community libraries listed in the schematic header (N8VEM and others).

## License

Hardware: CERN-OHL-S-2.0 for the original work in this folder; see the repo NOTICE for third-party parts.

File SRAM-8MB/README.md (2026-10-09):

# 8MB SRAM Board

An S-100 static RAM card holding 8 MB as 16 × 512 KB SRAMs in a 16-bit even/odd byte array. Silkscreen: "8MB SRAM BAORD" (rev1) and "8MB SRAM BAORD Rev 2.0" (rev2), 2014–2015.

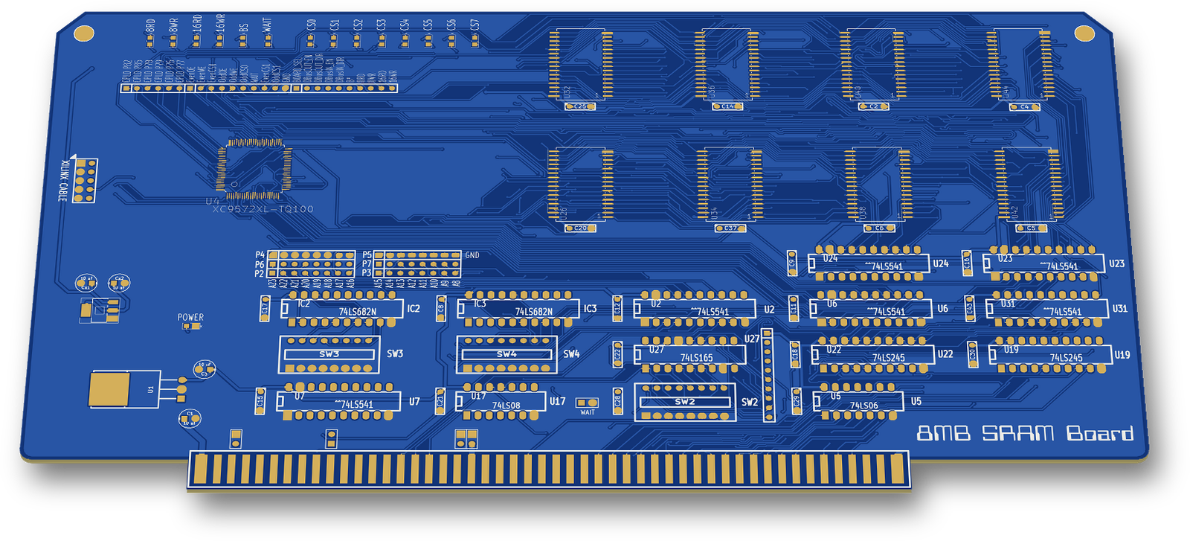
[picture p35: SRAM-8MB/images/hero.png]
8MB SRAM Board


 

Rev1 (discrete TTL):

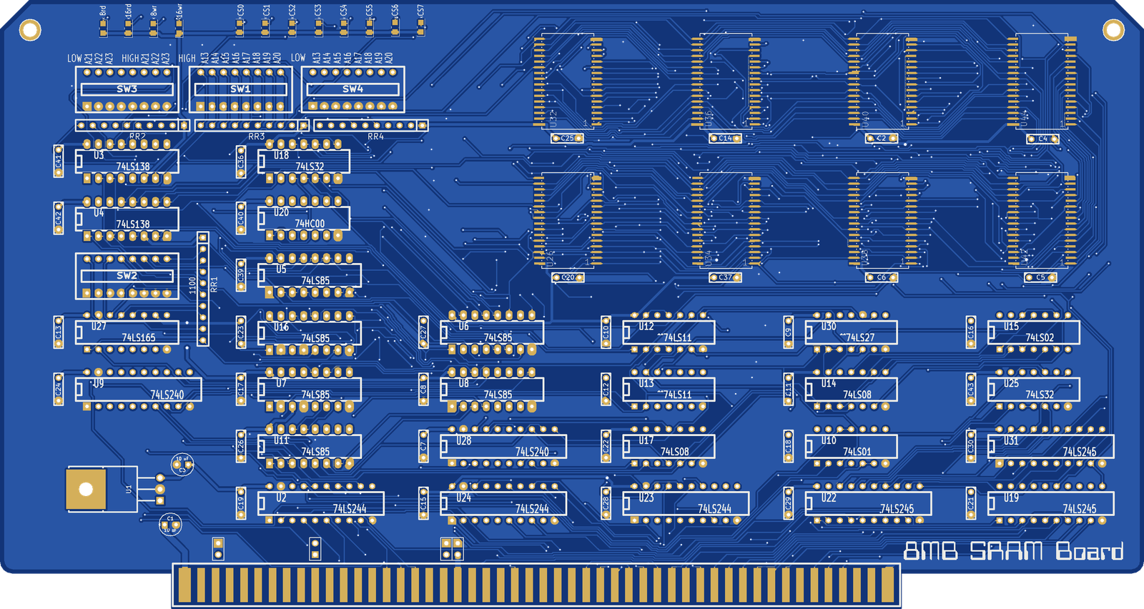
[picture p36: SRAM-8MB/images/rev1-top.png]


## Status
Both revisions were built. Fabrication gerbers are in `rev1/GERBERS` (2014-03-24) and `rev2/GERBERS` (2014-04-16).

## Hardware
**Rev2** (`rev2/`):

| Ref | Part | Role |
|---|---|---|
| U4 | XC9572XL-TQ100 | CPLD: board select, 8/16-bit strobes, bank decode, bus-buffer control |
| U26 U32 U34 U36 U38 U40 U42 U44 | SRAM 512K × 8 (SOP32) | even byte bank (ED0–7) |
| U21 U29 U33 U35 U37 U39 U41 U43 | SRAM 512K × 8 (SOP32) | odd byte bank (OD0–7) |
| IC2, IC3 | 74LS682 | board-address compare against SW3 / SW4 |
| U2 U6 U7 U23 U24 | 74LS541 | address and status buffers |
| U31 | 74LS541 | even-to-odd byte bridge for 8-bit transfers |
| U22 / U19 | 74LS245 | data in from DO0–7 / data out to DI0–7 |
| U27 | 74LS165 | wait-state generator, pattern set by SW2 |
| U17 / U5 | 74LS08 / 74LS06 | BOARD_SYNC gate / PHI inverter |
| Q16 | BC817 | open-collector drive of RDY (bus pin 72) |
| Q1–Q15 | BC817 | LED drivers |
| U1, Ux1 | 7805, 3.3 V SOT-223 | 5 V and 3.3 V regulators |
| P9 | 2×5 header | Xilinx JTAG cable |

**Rev1** (`rev1/`): the same 16 SRAMs, with the logic in TTL:
- U5 U6 U7 U8 U11 U16: 74LS85 address-range comparators with DIP switches SW1, SW3, SW4;
- U3, U4: 74LS138 bank decode;
- U27: 74LS165 wait generator with SW2, driving RDY through a 74LS01;
- U2 U23 U24: 74LS244, U9 U28: 74LS240 and U19 U22 U31: 74LS245 for the bus.

**Board size:** 254.0 × 134.9 mm (Edge.Cuts extents, including the edge-connector tab).

**Made with:** KiCad (2013-07-07 BZR 4022)-stable; Xilinx ISE 14.7 for the CPLD.

**Switches, jumpers and LEDs:**
- **Rev2:**
  - SW3/SW4: board address. SW2: wait states.
  - JP4 "WAIT": disables wait states. JP8: SIXTN*. JP1/JP2/JP3: bus 0V pins 20/53/70 to GND.
  - Headers P2/P3 (address rows A23–A16 and A15–A8), P4/P5 (GND rows) and P6/P7 (comparator inputs) pick which address lines are compared.
  - Test headers P8, P10, P11.
  - LEDs: `8RD 8WR 16RD 16WR BS WAIT CS0–CS7`, plus POWER.
- **Rev1:**
  - DIP switches labelled `LOW A21 A22 A23 / HIGH A21 A22 A23` (SW3), `HIGH A13…A20` (SW1) and `LOW A13…A20` (SW4).
  - LEDs: `8rd 16rd 8wr 16wr CS0–CS7`.

## How it works
- **Banking:** every SRAM gets address lines A1–A19, and A0 picks the even or odd byte ("EVEN BYTE RAM" / "ODD BYTE RAM" in the schematic). One even plus one odd chip is a 1 MB 16-bit bank. A20–A22 pick one of 8 banks; the `CS0`–`CS7` LEDs show which.
- **16-bit transfers** (sXTRQ*, bus pin 58, low): the even byte arrives on DO0–7 and the odd byte leaves on DI0–7, both banks enabled.
- **8-bit transfers:** only the bank matching A0 is enabled. The U31 bridge (`B*`) copies the byte across for an 8-bit read at an even address or an 8-bit write at an odd address.
- **Board address, rev1:** two 74LS85 chains compare A23–A13 against a LOW start address and a HIGH end address set on the DIP switches.
- **Board address, rev2:** IC2/IC3 (74LS682) compare up to 16 address bits (A23–A8) against SW3/SW4. A shunt on P6/P7 connects each comparator input either to its address line or to GND.
- **CPLD (U4, `cpld/U4v1.sch`, `cpld/pinmap.ucf`):**
  - `BS` = a memory read (pDBIN) or write (pWR*) that is not an I/O or interrupt cycle (sINP, sOUT, sINTA) while both comparators report equal.
  - From BS it makes `RD8/WR8/RD16/WR16`, the even/odd OE and WE strobes, the per-bank chip selects (A20–A22 through 74x138 decoders), the bridge enable `B*`, and the U19/U22 buffer enables.
- **Wait states:** done in TTL, not in the CPLD. `BOARD_SYNC` (BS AND pSYNC) loads U27 (74LS165) from SW2, PHI* shifts it, and its output pulls RDY low through Q16.
- **UCF note:** the header of `pinmap.ucf` says "U5", but the CPLD is U4 on the board. All 57 pin assignments match the nets of U4.

## Revisions
| Folder | Silkscreen | Dates |
|---|---|---|
| `rev1/` | 8MB SRAM BAORD | 2014-03-20 → 2014-04-07 |
| `rev2/` | 8MB SRAM BAORD Rev 2.0 | 2014-04-11 → 2015-07-17 |
| `cpld/` | U4 on rev2 | 2014-05-02 → 2015-12-25 |

## Files
- `rev1/`:
  - KiCad schematic, board, netlist and `-cache.lib`;
  - `GERBERS/`;
  - `BOM/` (csv, xlsx);
  - `other/`: board logo artwork and its footprint `LOGO8MBSRAM3.kicad_mod`.
- `rev2/`: KiCad schematic, board, netlist, `-cache.lib`, `GERBERS/`.
- `cpld/`:
  - `U4v1.sch`: ISE schematic;
  - `pinmap.ucf`: pin map;
  - `SRAM_B_V2/SRAM_B_V2.xise`: ISE project;
  - `SRAM_B_V2/U4v1.jed`: programming file for XC9572XL-7-TQ100.

Left out: KiCad backups and router files, PDFs and ISE build output.

## History
The git history replays the original dated backups of this board, 2014-03-20 to 2015-12-25.

## Things to check (TODO)
- In `cpld/U4v1.sch` the bank-decoder outputs for banks 6 and 7 are unconnected, so the final JED never drives `EVENRAM_CS6/7` or `ODDRAM_CS6/7` (pins P64, P74, P50).
- In the final fit, `CS2_LED` is placed on P65. `pinmap.ucf` assigns P65 to `EVENRAM_CS7`, and the rev2 board routes it to U44 pin 22 (`EvenRAMCS7*`).
- On the rev2 board, the `CS2_LED` net goes only to R22; it is not wired to a CPLD pin.

## Credits
- **John Monahan, S-100 16MB SRAM board V01** (S100Computers.com, with N8VEM): the rev1 bus logic follows this board's design. The evidence:
  - the even/odd data buses `ED0–7`/`OD0–7`;
  - the `8rd 8wr 16rd 16wr` strobes;
  - `BOARD_SYNC` and `buffered_A0`;
  - the 74LS165 wait-state generator;
  - the same bus-buffer set.

  The SRAM array, address compare, bank decode, PCB layout and the rev2 CPLD design are original to this board.
- **Schematic symbols:** the N8VEM KiCad libraries.

## License
Hardware: CERN-OHL-S-2.0 for the original work in this folder; see the repo NOTICE for third-party parts. The "© 2014 Antony Burrows / ALL RIGHTS RESERVED" copper text is left as fabricated; the license above applies.

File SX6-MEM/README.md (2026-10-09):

# SX6-MEM: SDRAM Board – S100 Daughterboard

A KiCad schematic for an S-100 daughterboard that pairs a Spartan-6 XC6SLX25 FPGA with a 168-pin SDRAM DIMM socket (sheet title "SDRAM Board - S100 Daughterboard", Rev 0, 2014).

**Unfinished: schematic only; the FPGA was never wired to the DIMM.**

## Status

- Not built. There is no PCB layout, no gerbers and no BOM for this design.
- The schematic was drawn March–June 2014.

## Hardware

| Ref | Part | Role |
|---|---|---|
| U2 | XC6SLX25-FT(G)256 | FPGA (drawn as 7 units) |
| U19 | SDRAM-168PIN_DIMM | 168-pin SDRAM DIMM socket |
| U32 | XCF02S | FPGA configuration PROM |
| U33 | Oscillator (CLK_FPGA1) | FPGA clock (`FPGA_CLK_0` to U2 pin M9) |
| U3, U5, U6, U7, U12 | 74LS373 | Address/data latches |
| U9–U11, U13–U16, U18, U21 | 74LVC245 | Bus buffers |
| U23–U26 | 74HC245 | Bus buffers |
| U27, U28, U22, U17/U20, U8 | 74164, 74LS138, 74LS32, 74HC04, 74HC14 | Glue logic |
| U34 | LDO_REG_7805 | 5 V regulator from the S-100 +8 V |
| U35 | LM1086 (TO-252) | 3.3 V regulator |
| U1 | SOT-223 regulator | 1.2 V rail (V1.2) |
| P19 | S100_MALE | S-100 edge connector |
| P5, P6 | 20×2 and 25×2 headers | Daughterboard connectors |
| P20 | 5×2 header "XILINX CABLE" | JTAG |

- **Jumpers:** JP5 feeds V1.2 to the FPGA's VCCINT pins. JP4 and JP6–JP9 feed V3.3 to VCCAUX and the I/O-bank supplies.
- **Other controls:**
  - SW2 "PROG_B" push button;
  - P1 "MODE" header;
  - LEDs D1–D8.
- **Tools:** KiCad (2013-07-07 BZR 4022) stable, EESchema file format version 2. It is one A0 sheet.

## How it works

The design was planned as an FPGA SDRAM controller. The schematic stops before the FPGA is connected to the memory or the bus.

- **Wired:**
  - the FPGA power;
  - configuration from the XCF02S over JTAG (TCK on C14, TMS on A15);
  - the clock on M9;
  - PROG_B and the mode pins;
  - the power supply (the S-100 +8 V feeds the 5 V and 3.3 V regulators).
- **DIMM:** only its power pins are connected. Net labels for its signals are placed beside the socket (`SD_1_A0–A13`, `BA0–1`, `DQ0–63`, `DQMB0–7`, `CK0–3`, `CKE0–1`, `S0#–S3#`, `RAS`, `CAS`, `WE`) but aren't wired.
- **Bus logic:** the latch and buffer block is wired between the P5/P6 headers. It is not connected to the FPGA.
- **S-100 edge:** only GND and +8 V are connected.
- **Off-sheet symbols:** a second XC6SLX25 symbol (U100) and an XC6SLX9-CSG324 symbol (U?) sit off the sheet and are unconnected.

## Files

| File | What it is |
|---|---|
| `S100_SX6_MEM.sch` | The schematic |
| `S100_SX6_MEM-cache.lib` | Symbol cache for opening the schematic |
| `S100_SX6_MEM.pro` | KiCad project file |

## History

The git history adds the schematic at its last saved date (June 2014).

## Things to check (TODO)

- The `SD_1_*` labels beside U19 are not wired to the DIMM pins, and no FPGA pin carries an `SD_1_*` label.
- The 74LS373/74LVC245/74HC245 block on P5/P6 is not connected to U2 or to the S-100 edge P19.
- U100 (`XC6SLX25-XFTG256-`) is not in `S100_SX6_MEM-cache.lib`, so it may load as a missing symbol.
- U? (XC6SLX9-CSG324) has no reference number.
- The Spartan-6 hard memory controller (MCB) supports DDR, DDR2, DDR3 and LPDDR. A 168-pin SDR DIMM would need a controller built in the FPGA fabric.

## Credits

- The daughterboard header signals on P5/P6 follow the naming in John Monahan's S100Computers.com 80386 SRAM daughterboard. Examples are `bA2–bA31`, `cA20–cA31`, `mA2–mA19`, `D0–D31`, `DB_ADS*`, `DB_S100_SEL*`, `DB_PHANTOM*`, `DB_WAIT` and `80386-RESET`.
- The S-100 edge symbol comes from the N8VEM KiCad library.

## License

Hardware: CERN-OHL-S-2.0 for the original work in this folder; see the repo NOTICE for third-party parts.

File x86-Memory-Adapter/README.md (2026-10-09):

# x86 32bit Memory Adapter + 4Mbit SRAM module

Two boards from 2015–2016:
- **"x86 32bit Memory Adapter Board"**: an S-100-size card that connects the 80386 CPU board to a 32-bit, 3.3 V memory mezzanine.
- **"4Mbit (128K x 32)"**: an SRAM module for that mezzanine slot.

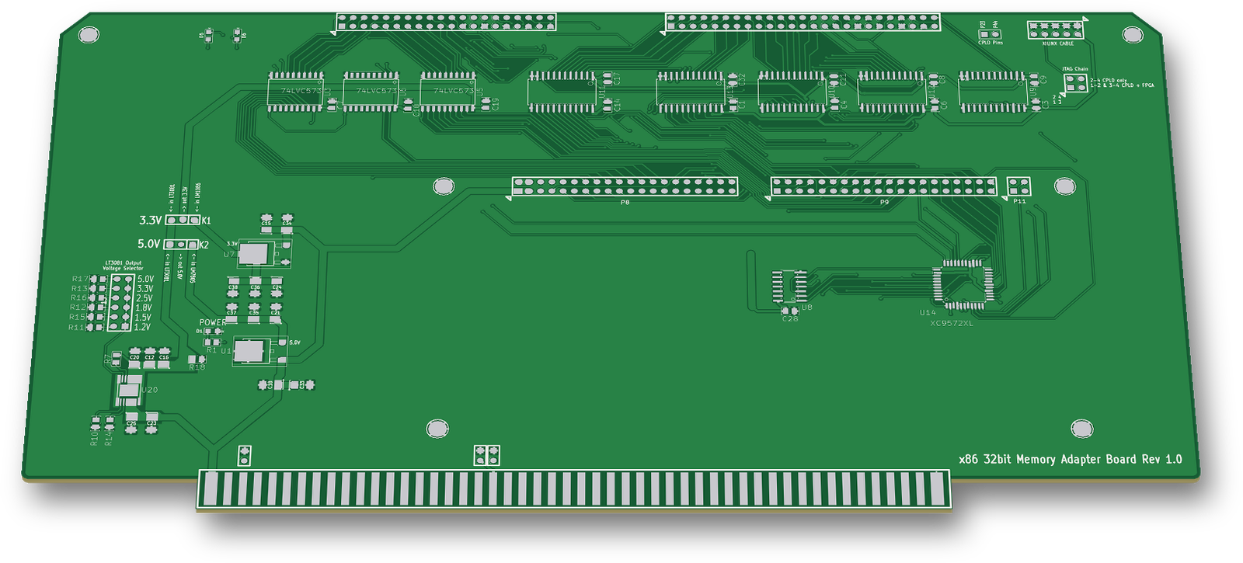
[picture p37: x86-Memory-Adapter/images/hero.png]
x86 32bit Memory Adapter Board


 

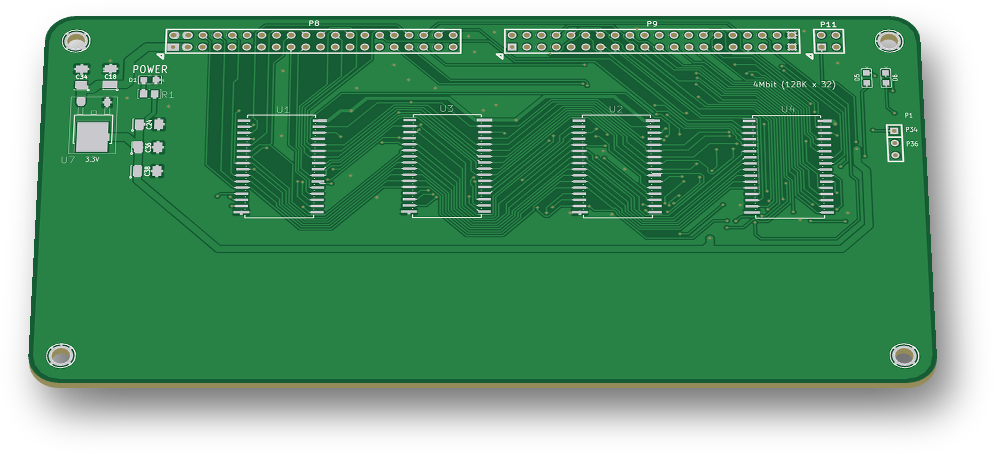
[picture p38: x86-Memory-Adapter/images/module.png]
4Mbit (128K x 32) SRAM module


## Status
- **Adapter:** not built. Gerbers were plotted on 2015-04-25 (`adapter/GERBERS/`). The layout was changed after that (CPLD moved to the bottom side, LM2596 added, board re-routed up to 2016-01). No gerbers exist for the final layout.
- **SRAM module:** built. Gerbers were plotted on 2015-05-02 (`sram-module/GERBERS/`).

## Hardware

### Adapter (`adapter/`)
| Ref | Part | Role |
|---|---|---|
| U14 | XC9572XL-VQ44 | Control CPLD |
| U2–U6 | 74LVC573 | Latch the 80386 address (mA2–19, cA20–31) and byte enables mBE0–3* on `DB_ADS` |
| U10–U13 | 74LVX3245 | 32-bit data buffers, D0–31 (5 V) ↔ bD0–31 (3.3 V) |
| U9 | 74LVX3245 | Drives `DB_PHANTOM*` and `DB_WAIT` back up to 5 V for the 80386 board |
| U17, U8 | 74F04, 74F14 | Clock, `S100_SEL*` and `DB_ADS` conditioning |
| U1 | LM7805 | 5 V |
| U7 | LM1086 | 3.3 V |
| U20 | LT3081 | Adjustable rail |
| U19 | LM2596 | Buck pre-regulator (added 2015-07) |
| P5, P6 | 2×20, 2×25 headers | Ribbon connections to the 80386 CPU board (address/byte enables and data/control) |
| P8, P9 | 2×20 headers | 32-bit memory mezzanine slot |
| P11 | 2×2 header | JTAG to the mezzanine |
| P20 | S-100 edge | Power only (+8 V on pins 1/51, GND on pins 50/100) |

- **Size:** 254.00 × 134.62 mm, 2 layers.
- **Jumpers and headers** (silkscreen names):
  - **LT3081 Output Voltage Selector** (P13): 5.0 / 3.3 / 2.5 / 1.8 / 1.5 / 1.2 V.
  - **3.3V** (K1): takes 3.3 V from the LM1086 or the LT3081.
  - **5.0V** (K2): takes 5 V from the LM7805 or the LT3081.
  - **JTAG Chain** (P12): "2-4 CPLD only, 1-2 & 3-4 CPLD + FPGA". The second setting adds the mezzanine's device to the chain.
  - **XILINX CABLE** (P7, 2×7).
  - **CPLD Pins** (P10: CPLD pins 23 and 44).
  - JP5–JP7: tie S-100 pins 20, 53 and 70 to GND.
- **LEDs:**
  - POWER (D1);
  - `BOARD_SELECT` (D2, CPLD pin 32);
  - D5 and D6 (CPLD pins 33 and 31).

### SRAM module (`sram-module/`)
| Ref | Part | Role |
|---|---|---|
| U1–U4 | 128K×8 SRAM, SOP32 | One byte lane each: D0–7, D8–15, D16–23, D24–31 |
| U14 | XC9536XL-VQ44 | Byte-lane chip enables and write enables |
| U7 | LM1086 | 3.3 V from +8 V (P8 pins 1–4) |
| P8, P9 | 2×20 headers | Mezzanine connection to the adapter |
| P11 | 2×2 header | JTAG (TDO/TMS/TDI/TCK) |
| K1 | 3-pin header | CPLD pins 1, 34 and 36 (silkscreen "P1 / P34 / P36") |

- **Capacity:** 128K × 32 = **512 KB (4 Mbit)**, using word address lines A2–A18.
- **Slot headroom:** the P8/P9 slot also carries A19–A22 (unused on this module), which is enough for up to 8 MB.
- **Size:** 150.37 × 75.18 mm, 2 layers, 4 mounting holes.
- **LEDs:** POWER (D1), and D5/D6 (CPLD pins 33 and 31).

**KiCad (both boards):** 2013-07-07 BZR 4022 stable. The schematics are `EESchema Schematic File Version 2` and the PCBs are `kicad_pcb` version 3.

## How it works
- **No S-100 bus signals are used.** The adapter takes only power and GND from the S-100 edge connector. The 80386 CPU board drives the memory directly over the P5/P6 ribbon connectors.
- **Address and byte enables:** the five 74LVC573s latch the 80386 address and byte enables on `DB_ADS`.
  - A2–A22 go to the mezzanine as bA2–bA22.
  - The upper address bits (cA23–cA31) and the byte enables BE0–3* go both to the adapter CPLD and, over P9, to the mezzanine CPLD.
- **Data:** four 74LVX3245s buffer the 32-bit data bus between the 5 V 80386 side and the 3.3 V mezzanine.
  - Adapter CPLD pin 36 drives T/R (direction) on U10–U13.
  - CPLD pin 39 is on the same net as OE* of U10–U13.
- **Wait and phantom:** the adapter CPLD returns `DB_WAIT` and `DB_PHANTOM*` to the 80386 board through U9.
- **On the module:** the byte enables BE0–3* arrive on XC9536XL pins 14, 16, 18 and 19. The CPLD's pins 41–44 go to the four SRAM chip enables and pins 37–40 to the four write enables, one pair per SRAM.
  - The shared output enable of all four SRAMs is on module CPLD pin 12. It is also wired to P9 pin 26 (adapter CPLD pin 29).
  - Six further P9 pins link the two CPLDs directly (pins 2, 3, 5–8 on both).
- **JTAG chain:** P11 continues the adapter's chain into the module CPLD.
- **No CPLD source:** there is no CPLD project (no UCF or JEDEC) for either board in the original files.

## Files
| Path | Contents |
|---|---|
| `adapter/s100_80386 SRAM V6.*` | Adapter KiCad project (`.sch`, `-cache.lib`, `.pro`, `.kicad_pcb`, `.net`, `.cmp`) |
| `adapter/GERBERS/` | Adapter gerbers and drill file, plotted 2015-04-25 from the April layout |
| `sram-module/4Mem board v1.*` | Module KiCad project |
| `sram-module/GERBERS/` | Module gerbers and drill file, plotted 2015-05-02 |

Notes on the files:
- The adapter project keeps the file name of the Monahan design it started from (see Credits).
- The module gerbers of 2015-05-02 still contain a trial DDR3 DIMM footprint. The final module `.kicad_pcb` (2015-07-12) does not.
- The module schematic has an unannotated `SRAM_512KB` symbol placed outside the sheet. It is not in the netlist.

## History
The git history replays the original dated backups of both boards, from 2015-04-24 to 2016-01-13.

## Things to check (TODO)
- **Adapter:** U10–U13 OE* (net `CPLD_P39`) is driven by U17 (74F04) from `S100_SEL*` through one inverter, and it is also wired to CPLD pin 39. Check the polarity, and check that CPLD pin 39 is used only as an input.
- **Adapter:** the U6 (74LVC573) inputs D2–D7 (pins 4–9) are unconnected. So are the unused A/B pins of U9 (74LVX3245, pins 5–10 and 14–19). Check whether they need to be tied off.
- **Adapter:** U15 is a placeholder part, "ZZZZ1", in the final netlist and PCB. Check what it is meant to be.
- **Module:** the schematic note says "XC9532XL VQ44", but U14 is an XC9536XL-VQ44.

## Credits
- **The adapter started from John Monahan's S100 80386 SRAM V6 board** (S100Computers.com), the 32/64 MB SRAM board for his 80386 CPU board. Full credit to him for that design.
  - Evidence: the adapter's schematic keeps 49 of his component timestamps and his project file name.
  - The **P5/P6 interface to the 80386 board** keeps his pinout exactly.
  - The S-100 edge connector, card outline and card-ejector holes also come from his files.
- **New work in this folder:**
  - the CPLD and its logic connections;
  - the 3.3 V latches and buffers;
  - the power section (LM1086, LT3081, LM2596);
  - the JTAG chain;
  - the single 32-bit P8/P9 mezzanine pinout (his design used four byte-wide mezzanines);
  - the whole SRAM module.

## License
Hardware: CERN-OHL-S-2.0 for the original work in this folder. See the repo NOTICE for third-party parts.

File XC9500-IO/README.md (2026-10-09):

# MCP Serial Peripheral I/O & External SPI V2.0

An S-100 I/O board from 2015. An XC9572 CPLD drives twelve MCP23S08 SPI port expanders, giving 96 I/O lines, plus two external SPI ports.

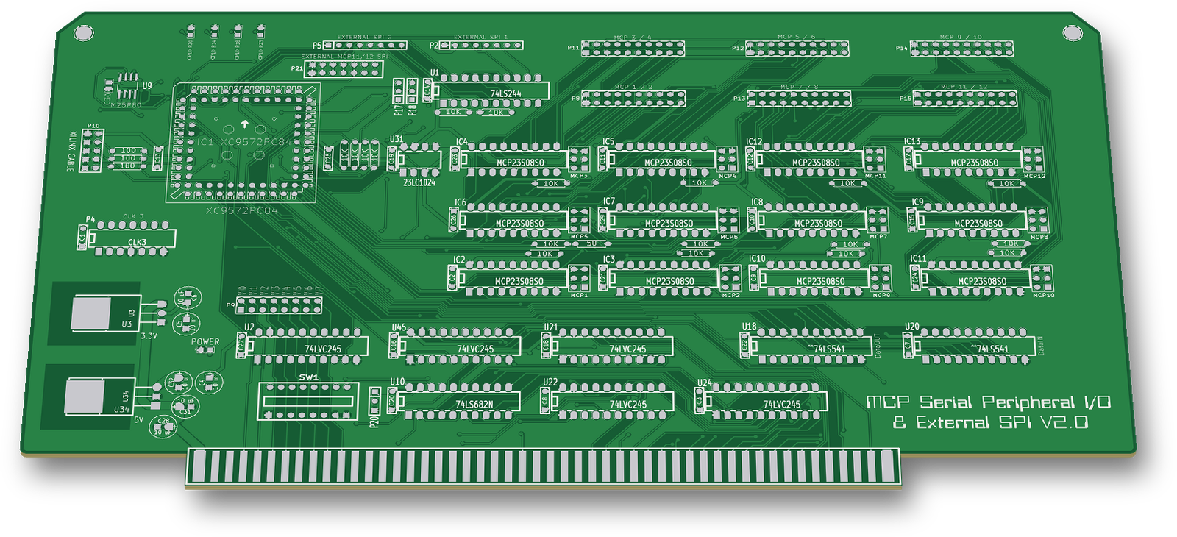
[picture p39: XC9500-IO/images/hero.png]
MCP Serial Peripheral I/O & External SPI V2.0


 

The renders come from the fabrication gerbers dated 29-07-2015.

## Status
Built. The gerbers in `GERBERS/` are dated 29-07-2015 and carry "SPI MCP I/O - REV 2.0 © 2015 A Burrows" in bottom copper.

The KiCad files hold a later revision (schematic 13-08-2015) that was not plotted to gerbers. It adds a second 74LS682 (U11), a 12-way SW1 and the VI0\* line on the vector jumper, and U9 moves to a DIP-8 footprint.

No CPLD project for this board survives in the backups.

## Hardware

| Ref | Part | Role |
|---|---|---|
| IC1 | XC9572 PC84 (PLCC-84 socket) | S-100 decode and SPI master |
| IC2–IC13 | MCP23S08 (DIP-18) | 12 × 8-bit SPI port expanders ("MCP1"–"MCP12") |
| U31 | 23LC1024 | SPI SRAM on the shared SPI bus |
| U9 | M25P80 | SPI flash, 3.3 V |
| U5–U8 | 74LVC1T45 | 5 V ↔ 3.3 V level shifting for U9 |
| U1 | 74LS244 | buffers for EXTERNAL SPI 1 and 2 |
| U21, U22, U24, U45 | 74LVC245 | S-100 address, status and control inputs |
| U2 | 74LVC245 | interrupt-vector driver to the P9 jumper |
| U18, U20 | 74LS541 | S-100 data out → CPLD, CPLD → data in |
| U10, U11 | 74LS682 | I/O address compare against SW1 (U11 in the later revision only) |
| U34 / U3 | 7805 / LM1086 | 5 V and 3.3 V from the S-100 +8 V |
| P4 | "CLK 3" DIP-14 oscillator | CPLD clock GCK2 |

- Board size: 254.0 × 135.6 mm (10.0 × 5.34 in, including the edge fingers).
- KiCad (2013-07-07 BZR 4022)-stable, legacy `.sch`/`.brd`.
- Jumpers and switches:
  - MCP1–MCP12: address jumpers, A0/A1 for each MCP23S08.
  - P17 "INT3" and P18 "INT4": interrupt source select.
  - P20: 8-bit or 16-bit I/O decode.
  - P9 "VI0…VI7": interrupt-vector select.
  - SW1: I/O address.
- Connectors:
  - P8, P11–P15 "MCP 1 / 2" … "MCP 11 / 12": port headers.
  - P2 "EXTERNAL SPI 1", P5 "EXTERNAL SPI 2" and P21 "EXTERNAL MCP11/12 SPI".
  - P10 "XILINX CABLE": JTAG.
- LEDs: "CPLD P14/P18/P20/P23" and "POWER".

## How it works
- **SPI bus:** the CPLD is the master. SCK is on P65, MOSI on P62 and MISO on P66, each with a 10 K pull-up. Every expander has its own chip select:

  | Device | CPLD pin |
  |---|---|
  | MCP1 | P83 |
  | MCP2 | P84 |
  | MCP3 | P44 |
  | MCP4 | P52 |
  | MCP5 | P54 |
  | MCP6 | P55 |
  | MCP7 | P48 |
  | MCP8 | P50 |
  | MCP9 | P57 |
  | MCP10 | P53 |
  | MCP11 | P58 |
  | MCP12 | P61 |
  | 23LC1024 | P56 |

  The CPLD drives `BOARD_RESET*` (P31) to all expanders and to the external headers.
- **Ports:** each 2×10 header carries two expanders. The odd pins 3–17 are GP0–7 of the first expander, the even pins 4–18 are GP0–7 of the second, pins 1–2 are GND and pins 19–20 are VCC.
- **Interrupts:**
  - MCP1 INT goes to P82 and MCP2 INT to P46.
  - Jumper P17 picks MCP3 or EXTERNAL SPI 1 for P51.
  - Jumper P18 picks MCP4 or EXTERNAL SPI 2 for P47.
- **External SPI:** P2 and P5 are 8-pin headers (GND, VCC, RESET\*, INT, SO, SI, CLK, CS) buffered by U1.
  - SPI 1: enable P11, CS P2.
  - SPI 2: enable P13, CS P3.

  P21 brings out the bus with the MCP11 and MCP12 chip selects.
- **SPI flash:** the M25P80 has its own 3.3 V SPI through the 74LVC1T45s: SI P4, SCK P1, CS P6, SO P7.
- **S-100 decode:** A0–A4 go to the CPLD. U10 compares A8–A15 with SW1, and P20 selects 16-bit or 8-bit I/O decode.
  - Later revision: U11 compares A5–A7 with SW1 and gives the board select on P70.
  - Gerber revision: the CPLD reads A5–A7 itself.
- **Bus signals:** data out comes in through U18 and data in goes out through U20, both on shared CPLD pins. The status and control lines (sOUT, sINP, sMEMR, MWRT, pWR\*, pDBIN, sWO\*, RESET\*, SLAVE_CLR\*) come in through the 74LVC245s. PHI and CLOCK feed GCK0 and GCK1.
- **Vector interrupt:** the CPLD drives P15 into U2, and jumper P9 routes it to one of VI0\*–VI7\*.

## Files
| Path | Contents |
|---|---|
| `XC9500v1.sch`, `XC9500v1-cache.lib` | schematic and its symbol cache |
| `XC9500v1.brd` | PCB layout |
| `XC9500v1.net`, `XC9500v1.cmp`, `XC9500v1.pro` | netlist, footprint assignments, project |
| `XC9500v1.csv`, `XC9500v1.xlsx` | BOM from July 2015 (matches the gerber revision: 8-way SW1, 7×2 P9) |
| `GERBERS/` | REV 2.0 gerbers and drill file, 29-07-2015 |
| `logo/` | title logo art and its KiCad footprint |

## History
The git history replays the original dated backups, 25-07-2015 to 14-12-2015.

## Things to check (TODO)
- U31 23LC1024: pin 5 (SI) is on the SCK net (P65) and pin 6 (SCK) is on the MOSI net (P62). Check this against the MCP23S08 bus wiring.
- U2 (interrupt-vector buffer): DIR is tied to GND (B → A). Check the direction against the intended CPLD → VI0\*–VI7\* path.

## Credits
- The S-100 edge-connector symbol (`S100_MALE`) is from the N8VEM KiCad library.
- Other symbols come from community Xilinx and Microchip KiCad libraries and the author's own library.

## License
Hardware: CERN-OHL-S-2.0 for the original work in this folder; see the repo NOTICE for third-party parts.

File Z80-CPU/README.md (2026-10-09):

# Z80 CPU

An S-100 bus-master CPU card built around a Zilog Z80, in four revisions (silkscreen REV 1.0 to REV 5.0), 2014–2016. From REV 4.0 on, most of the bus control logic is in a Xilinx XC9572 CPLD.

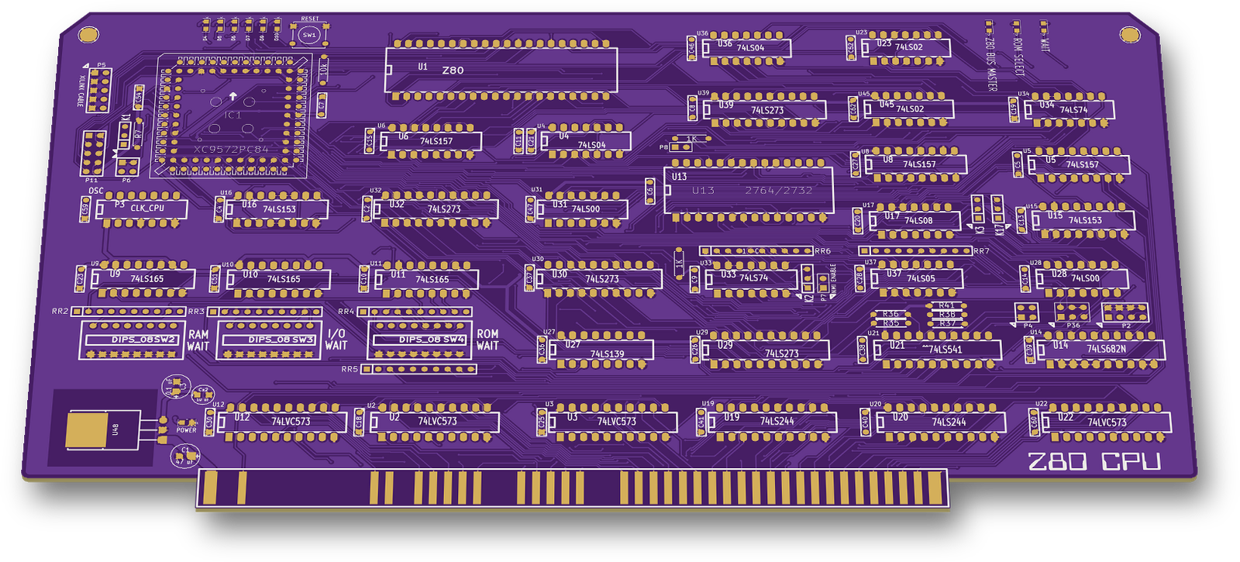
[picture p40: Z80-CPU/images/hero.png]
Z80 CPU


 

## Status
All four revisions were built: v2 (REV 1.0), v3 (REV 2.0), v4 (REV 4.0) and v5 (REV 5.0).
The v4 gerbers are in a folder named `SENT to PCBway 28-07-2015`.

## Revisions
| Folder | Silkscreen | Main change | Design dates |
|---|---|---|---|
| `v2/` | "Z80 CPU BOARD", REV 1.0 | First board, all TTL, 2732 ROM. Files keep the `s100_Z80 V2` name of the S100Computers "VERSION 02" design they started from | Jun 2014 (schematic notes to Aug 2015) |
| `v3/` | "Z80 CPU" logo, REV 2.0 | Re-layout, master oscillator and CLK DIVISION jumpers, pSYNC DIP switch | Jul–Aug 2014 |
| `v4/` | "Z80 CPU - REV 4.0 © 2015 A Burrows" | XC9572 PC84 CPLD (IC1) takes over the S-100 status/control logic, Xilinx JTAG header, CPLD I/O headers | Jun–Jul 2015 (schematic updated Dec 2015) |
| `v5/` | "Z80 CPU © 2015 A Burrows", REV 5.0 | 2764 ROM (2732 still fits), 74LVC573 latches instead of 74LS541 buffers, CPLD wired to the data bus, ROM LOCK and CLK SEL jumpers | Dec 2015–Jan 2016 (board edit Oct 2016) |

There is no REV 3.0.

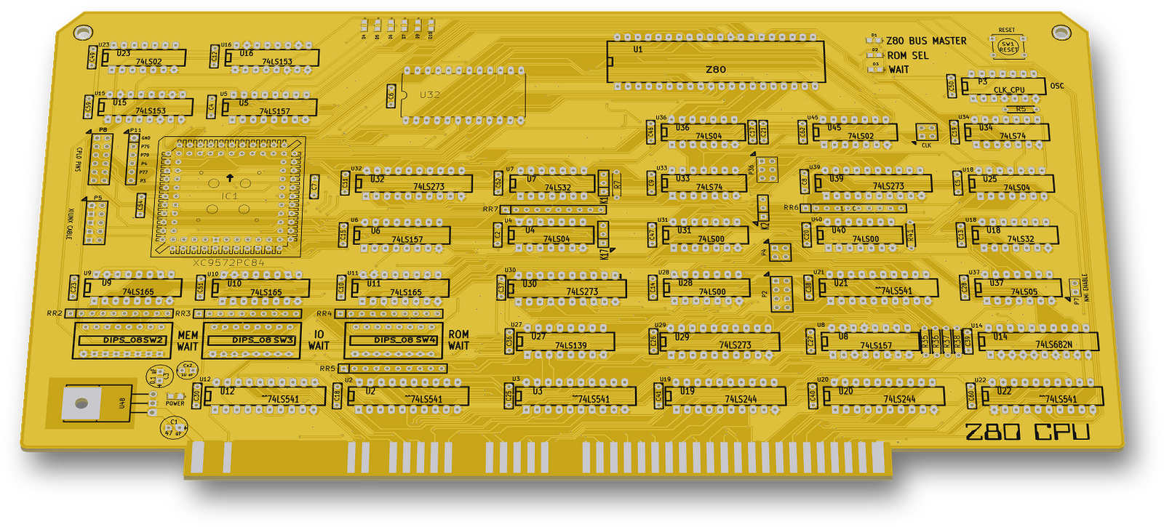
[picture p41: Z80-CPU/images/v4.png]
REV 4.0 (v4)
 REV 5.0 (v5)

Left: REV 4.0 (`v4/`). Right: REV 5.0 (`v5/`).

## Hardware (v5)
| Ref | Part | Role |
|---|---|---|
| U1 | Z80 (40-DIP) | CPU |
| IC1 | Xilinx XC9572, PC84 (PLCC socket) | Bus status/control, reset, wait and ROM-enable logic |
| U13 | 2764 EPROM (2732 also fits, silkscreen "2764/2732") | On-board ROM |
| U2, U3, U12, U22 | 74LVC573 | Address and status latches to the S-100 bus (v4: 74LS541 buffers) |
| U19, U20 | 74LS244 | Data bus buffers |
| U29, U30, U32, U39 | 74LS273 | Latches/ports |
| U21 | 74LS541 | Clock and control buffers to the bus |
| U9, U10, U11 | 74LS165 | Wait-state shift registers, loaded from DIP switches SW2–SW4 |
| U14 | 74LS682 | 8-bit comparator |
| P3 | DIL14 oscillator ("CLK_CPU", "OSC") | CPU clock source |
| U48 | 7805 LDO | 5 V regulator |

- **Board:** 254.0 x 134.6 mm (10.0 x 5.3 in), two layers, the same outline on all revisions.
- **Switches and jumpers (v5):** DIP switches "RAM WAIT", "I/O WAIT" and "ROM WAIT". SW1 "RESET". K1 "ROM LOCK". P6 "CLK SEL". P7 "NMI ENABLE". P5 "XILINX CABLE" (JTAG). P11 is the CPLD I/O header.
- **LEDs (v5):** "Z80 BUS MASTER", "ROM SELECT", "WAIT", "POWER", and D4–D7, D9, D10 driven from the CPLD.
- **Tools:** KiCad (pcbnew 2013-07-07 BZR 4022-stable) and Xilinx ISE 14.7.

## How it works
- The Z80 drives the S-100 bus as bus master. CPU control lines (M1\*, RD\*, WR\*, MREQ\*, IORQ\*, REFSH\*) go into the CPLD. The CPLD produces the S-100 status and control signals:

  | Signal | S-100 pin |
  |---|---|
  | sINP | 46 |
  | sOUT | 45 |
  | sMEMR | 47 |
  | MWRT | 68 |
  | sWO\* | 97 |
  | sINTA | 96 |
  | pSYNC | 76 |
  | pWR\* | 77 |

  Pin numbers are from the UCF comments. On v4, sINP leaves through U22 to pin 46 and sWO\* to pin 97.
- The CPLD handles reset: the RESET button and slave clear go in, and the Z80 RESET\* comes out on CPLD P17.
- Wait states come from three DIP switches through 74LS165 shift registers. The CPLD gates the wait signal (WAITen, pin 25 on v4).
- The on-board ROM is enabled through the CPLD. Its enable line is called RomEn (CPLD P37) and its address-range input RomAddr (P45).
- In the v4 pin map, four CPLD LEDs (D4–D7) sit on P39, P40, P41 and P81. Port D0/D1 bit 7 are inputs.
- v2 and v3 have no CPLD; the same functions are built from 74LS/74S gates.

## CPLD (`cpld/`)
Two Xilinx ISE projects for the XC9572 PC84. Both pin maps are for the v4 board:
- `cpld/Z80_Board_V4/`: the first design. Top schematic `IC1v1.sch`, PISO shift-register sub-sheet `test1.sch` (also referenced by the project as `V4board-t2/PISO.sch`), `pinmap.ucf`, `IC1v1.jed`. Speed grade -10, July 2015.
- `cpld/z80v42/`: the second design. Revisions `IC1v2.sch`, then `IC1v2_2` to `IC1v2_7.sch`. The project top is `IC1v2_7`, with `IC1v2pinmap.ucf` and `IC1v2_7.jed`. Speed grade -7, Aug–Dec 2015. The pin map header reads "PIN MAP OF IC1 on Z80 Board V4". It uses CPLD pins that the v4 schematic notes as wire modifications ("Modification: tied to CPLD P37", "tied to CPLD P45 …").

## Files
| Path | Contents |
|---|---|
| `v2/`, `v3/`, `v4/`, `v5/` | KiCad project per revision: `.sch` and `-cache.lib` (schematic with its symbols), `.kicad_pcb`, `.net`, `.cmp`, `.pro` |
| `v2/board.*` | v2 board files (the v2 PCB was named `board`) |
| `v2/`, `v4/` `*.csv`, `*.xlsx` | IC parts lists |
| `v*/GERBERS/` | Fabrication gerbers and drill file for each revision |
| `v5/logo/` | "Z80 CPU" logo bitmap and its KiCad footprint |
| `v2/Logisim circuits/1.circ` | Small Logisim sketch (A14, A15, IOREQ, S0, S1 decode) |
| `cpld/` | ISE schematics, pin maps, project files and final JEDEC files |

## History
The git history replays the original dated backups of all four revisions and the two CPLD projects, from June 2014 to October 2016.

## Things to check (TODO)
- **CPLD design for v5:** both CPLD projects target the v4 board with wire modifications. The v5 board connects IC1 differently in places. For example, P45 (RomAddr in the pin map) is on data bus D4, and P76 (Resbut in the pin map) goes to the U22 latch enable. A CPLD design for the v5 pinout is not in this folder.
- **v3 gerbers:** they are dated 2014-07-18. The v3 schematic and board were changed after that, up to 2014-08-09, so the gerbers don't match the final `v3/s100_Z80 V3.kicad_pcb`.
- **v5 board file vs gerbers:** `v5/s100_Z80 V5.kicad_pcb` was saved in Oct 2016, after the Jan 2016 gerbers. It has wider CLK_OSC traces and the bottom text "© 2016" (the gerbers say "© 2015").
- **v5 drill file:** `v5/GERBERS/s100_Z80 V5.drl` is about 21 hours older than the copper gerbers.
- **v4 drill file:** `v4/GERBERS/s100_Z80 V4.drl` is an RS-274X file exported from gerbv, not Excellon.

## Credits
- **Origin:** this board started from John Monahan's **S-100 Z80 CPU Board V2** ([S100Computers.com](http://www.s100computers.com)). Full credit to him for the original design.
  - The v2 files keep its `s100_Z80 V2` name, and the first v2 board file still carried its text "S-100 Z80 CPU BOARD VERSION 02".
  - All four schematics share component time stamps with the original.
  - The original files are not included here.
- **Libraries:** schematic symbols from the N8VEM KiCad libraries (`N8VEM-KiCAD`, `00N8VEM`; e.g. the S-100 edge connector), embedded in the `-cache.lib` files.

## License
Hardware: CERN-OHL-S-2.0 for the original work in this folder; see the repo NOTICE for third-party parts. Images and documentation: CC-BY-4.0.

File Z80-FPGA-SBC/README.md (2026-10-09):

# Z80 FPGA SBC

An S-100 Z80 single-board computer with an XC95288XL CPLD, a Spartan-6 XC6SLX9 FPGA, SRAM, EPROM, a 16550 UART on USB and an 8255 parallel port (2013).

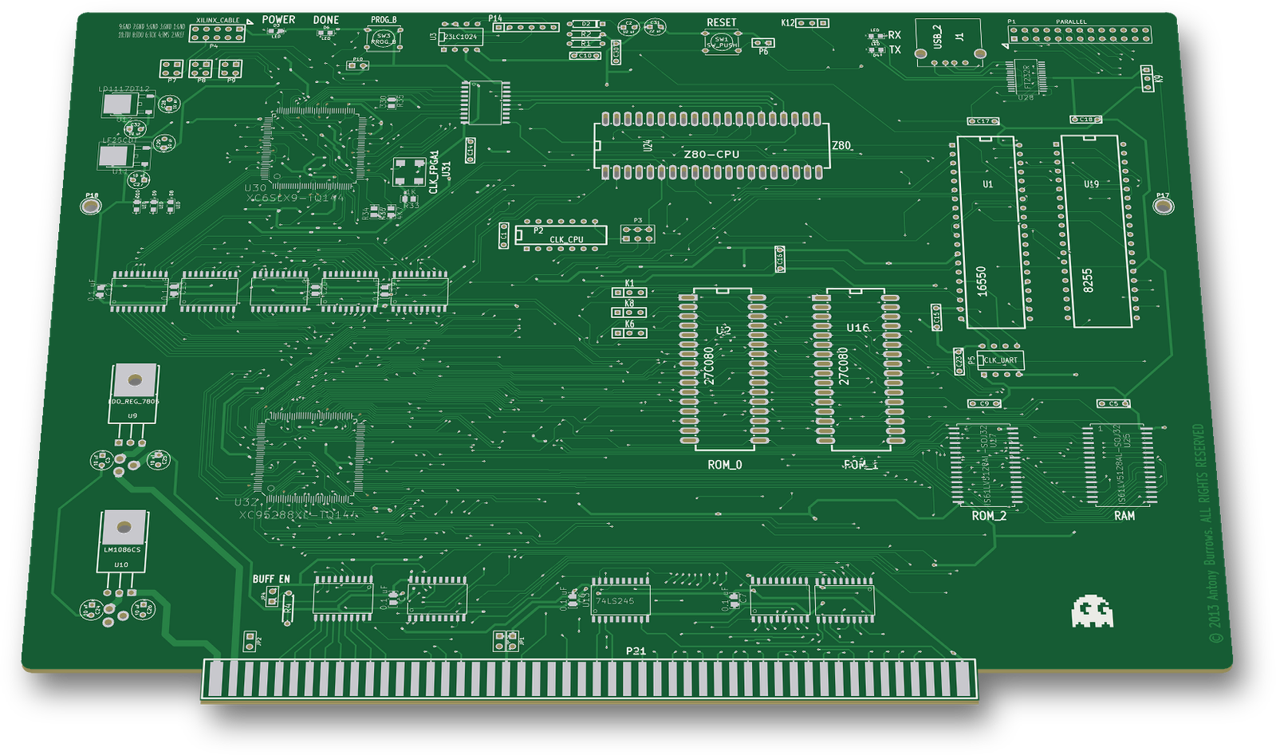
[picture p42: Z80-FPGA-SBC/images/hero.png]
Z80 FPGA SBC


 

## Status
Not built. REV 1.0 was plotted to gerbers (2013-07-22). REV 2.0 exists as a KiCad layout only.

## Hardware (REV 2.0)
| Ref | Part | Role |
|---|---|---|
| U24 | Z80 (DIP-40) | CPU |
| U32 | XC95288XL-TQ144 | CPLD: Z80 address/control decode, S-100 buffer enables |
| U30 | XC6SLX9-TQ144 | Spartan-6 FPGA |
| U33 | XCF02S | FPGA configuration PROM |
| U31 | oscillator (CLK_FPGA1) | FPGA clock |
| U2, U16 | 27C080 | EPROM sockets "ROM_0", "ROM_1" |
| U25, U27 | IS61LV5128AL (512K×8) | SRAM "RAM" and "ROM_2" |
| U3 | 23LC1024 | SPI SRAM on the FPGA |
| U1 | 16550 | UART |
| U28, J1 | FT232R, USB | USB serial for the 16550 |
| U19 | 8255 | parallel I/O on P1 "PARALLEL" |
| U13–U15, U35–U37, U42, U44, U50–U52, U54, U55 | 74LS245 | S-100 bus buffers |
| U22, U46–U49 | 74LS541 | S-100 address and data buffers |
| U43, U53 | 74LVC245 | 3.3 V / 5 V buffers |
| U9, U10, U11, U12 | 7805, LM1086CS, LF25CDT, LD1117DT12 | regulators (7805 and LM1086 fed from the S-100 +8 V) |
| U6, U17 | POWER_SELECT | 3-pin supply selects: U6 joins the 7805 output or +16 V to the 5 V rail; U17 joins the LM1086 output or −16 V to the 3.3 V rail |

- Board size: 254.0 × 183.9 mm (10.00 × 7.24 in) including the 0.30 in edge fingers, with 2 copper layers.
- KiCad: Pcbnew/Eeschema (2013-07-07 BZR 4022)-stable for REV 2.0, and PCBNEW (2011-07-08 BZR 3044)-stable for REV 1.0 and its gerbers.
- Switches: SW1 RESET, SW3 PROG_B (FPGA).
- LEDs: POWER, DONE, RX, TX.
- Jumpers:
  - JP1–JP3 connect S-100 pins 20, 53 and 70 to GND.
  - JP4 "BUFF EN" enables the S-100 buffers.
  - P3 CLK_SEL picks the CPU clock source.
- Clock sockets: P2 CLK_CPU, P5 CLK_UART.
- JTAG: P4 XILINX_CABLE, plus P7 CPLD_JTAG, P8 PF_JTAG and P9 S6_JTAG.

## How it works
- The Z80 runs from on-board EPROM and SRAM. The CPLD (U32) sees the whole Z80 address bus (A0–A7 on pins 100–107, A8–A15 on pins 79–87) and /M1, /MREQ, /IORQ, /RD, /WR (pins 28–33) and /RESET (pin 131).
- The CPLD drives the S-100 data buffer enables: /DBUSIN_EN (pin 132, U22) and /DBUSOUT_EN (pin 133, U49).
- S-100 address A0–A18 goes out through 74LS541s U46–U48. Data goes out through U22 and comes in through U49. Status and control lines (sM1, sOUT, sINP, sMEMR, pSYNC, pWR*, pDBIN, sINTA, sWO*, RDY, INT*, HOLD*, RESET*, PHI) go through 74LS245s.
- The 16550 (U1) talks to the FT232R (U28): FT232R TXD → 16550 SIN, and 16550 SOUT → FT232R RXD.
- The FPGA (U30) boots from the XCF02S and has a 23LC1024 SPI SRAM (U3) on pins 40, 41, 43 and 44, also brought out on header P14.
- No CPLD or FPGA design files for this board were kept.

## Revisions
| Folder | Layout text | Dates | Notes |
|---|---|---|---|
| `rev1.0/` | REV 1.0 | 2013-07-22 | Extra XC9572XL-VQ44 "CPLD2" (U8) for S-100 control, 14× MAX3002 level translators, MAX232, 6× LT3081 regulators. 10.00 × 6.91 in. |
| top level | REV 2.0 | 2013-08-26 → 2013-09-13 | Re-layout: U8, the MAX3002s, the MAX232 and the LT3081s replaced by 74LS245/74LS541/74LVC245 buffers and fixed regulators. |

## Files
- `SBC.sch`, `SBC-cache.lib`: schematic, KiCad legacy format. Newer KiCad needs *Remap Symbols* with the cache lib.
- `SBC.brd`: REV 2.0 layout.
- `SBC.pro`, `SBC.net`, `SBC.cmp`: project, netlist and footprint assignments.
- `BOM/SBC.csv`: bill of materials, exported 2013-08-12 (REV 1.0 era).
- `rev1.0/SBC_rev1.0.brd`: REV 1.0 layout, saved by KiCad as `SBC.000` and renamed so it opens as a `.brd`.
- `rev1.0/gerbers/`: REV 1.0 gerbers and drill file.

## History
The git history replays the original dated backups and working folder (2013-07-22 to 2013-09-13).

## Things to check (TODO)
- S-100 pins 59 and 63 are named CLOCK2 and IOREQb in this board's connector symbol, and 59 is driven by a 74LS245 (U15). IEEE-696 assigns 59/61–64 to A19–A23. Check this against the bus pinout before using the board with 24-bit address cards.
- CPLD U32 pins 9 and 17 are both on /D0, and pins 10 and 19 are both on /D1. Confirm this is intended.
- The cached XC95288XL symbol defines pins 50–54 and 56–59 four times each (stacked).
- In `SBC.net`, 74LVC245 U53 has no net on pin 1 (DIR) or pin 19 (/OE), and U43 has no net on pin 19 (/OE). Check before fitting.
- POWER_SELECT U17 has pins on −16 V (S-100 pin 52), the LM1086 output and the 3.3 V rail, and U6 has pins on +16 V, the 7805 output and the 5 V rail. Check the intended part or link for each before power-up.

## Credits
- The schematic was started from the **N8VEM SBC V2** (ECB SBC V2) KiCad design by **Andrew Lynch / the N8VEM project**.
  - The Z80, 16550, 8255, 27C080, 74LS14/74LS06, parallel port, reset and jumper parts keep the original KiCad timestamps (2008–2010).
  - The schematic uses the N8VEM KiCad symbol libraries.
- The S-100 edge-connector symbol comes from the S100Computers (John Monahan) Z80 V2 KiCad files.

## License
Hardware: CERN-OHL-S-2.0 for the original work in this folder; see the repo NOTICE for third-party parts (N8VEM). The board copper carries the text "© 2013 Antony Burrows. ALL RIGHTS RESERVED". It is left as designed. The licence above applies to the files in this repo.

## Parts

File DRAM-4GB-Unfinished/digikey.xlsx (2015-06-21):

Digikey part # | QTY | Price (NZD) | Manufacturer Part Number | Description
SER3709CT-ND | 1 | 3.05 |  | OSC XO 62.50MHZ CMOS SMD |  | 0.098" L x 0.079" W (2.50mm x 2.00mm) |  |  |  | Voltage - Supply | 2.5V
609-2025-ND | 6 | 0.50 |  | CONN PCI EXPRESS 36POS VERT PCB |  | (767-7020 is RS stock numner @ $3.62 each) |  |  |  | http://www.ebay.com/itm/36PIN-X1-PCI-E-PCI-Express-extender-Extension-cable-with-Gold-plated-Connector-/251935535767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
1028-1010-1-ND | 1 | 1.26 | RT9026 (http://www.richtek.com/download_ds.jsp?s=411) | IC DDR TERMINATION REG 10MSOP
LT1764EQ-1.5#PBF-ND | 1 | 11.81 | LT1764EQ-1.5#PBF | IC REG LDO 1.5V 3A 5DDPAK | 1.5V Regulator D2PAK-5pin |  | Voltage - Input 2.7 V ~ 20 V
LM1117MP-1.8/NOPBCT-ND | 1 | 1.60 | LM1117MP-1.8/NOPB | IC REG LDO 1.8V 0.8A SOT223 | 1.8V Reg SOT223 |  |  |  |  | SOT-223
NCP565D2T12R4GOSDKR-ND | 1 | 2.61 | NCP565D2T12R4G | IC REG LDO 1.2V 1.5A D2PAK | 1.2V Reg D2PAK-2pin+tab |  | Voltage - Input 2.5 V ~ 9 V |  |  | TO-263-3, D²Pak (2 Leads + Tab), TO-263AB
AZ1084CS2-3.3TRE1DICT-ND | 1 | 1.07 | AZ1084CS2-3.3TRE1 | IC REG LDO 3.3V 5A TO263-2 | 3.3V Reg D2PACK-2pin+tab |  | Voltage - Input 6.3 V ~ 12 V |  |  | TO-263-3, D²Pak (2 Leads + Tab), TO-263AB
LM1117MPX-2.5/NOPBCT-ND | 1 | 1.60 | LM1117MPX-2.5/NOPB | IC REG LDO 2.5V 0.8A SOT223 | 2.5V Reg SOT223 |  | Voltage - Input up to 15 V |  |  | SOT-223 |  | (RS: 785-2423 @ 1.744each pack of 5)
122-1465-ND | 1 | 1.93 | XC9536XL-5VQG44C | XILINX IC CPLD 36MC 5NS 44VQFP | XC9536XL Datasheet (http://www.xilinx.com/support/documentation/data_sheets/ds058.pdf) |  | (RS: 626-0652 @$2.13 each)
1450-1018-ND | 4 | 2.97 | AS6C1008-55SIN | IC SRAM 1MBIT 55NS 32SOP |  |  | (RS: 744-4542 @$3.51 each )
296-16843-1-ND | 1 | 0.92 | SN74LVC1T45DBVR | IC BUS TRANSCVR TRI-ST SOT23-6 | Level Translator 5-3.3 |  | SN74LVC1T45 (http://www.ti.com/lit/ds/symlink/sn74lvc1t45.pdf) |  | (RS: 825-3463 @0.681each in pack of 10)
MAX809STRGOSCT-ND | 1 | 0.63 | MAX809STRG | IC MPU SUPERVISORY 2.93V SOT23 | MAX809, MAX810, NCV809 Series (http://www.onsemi.com/pub_link/Collateral/MAX809S-D.PDF) |  |  | (RS: 688-8809 @0.555each Qty 2)

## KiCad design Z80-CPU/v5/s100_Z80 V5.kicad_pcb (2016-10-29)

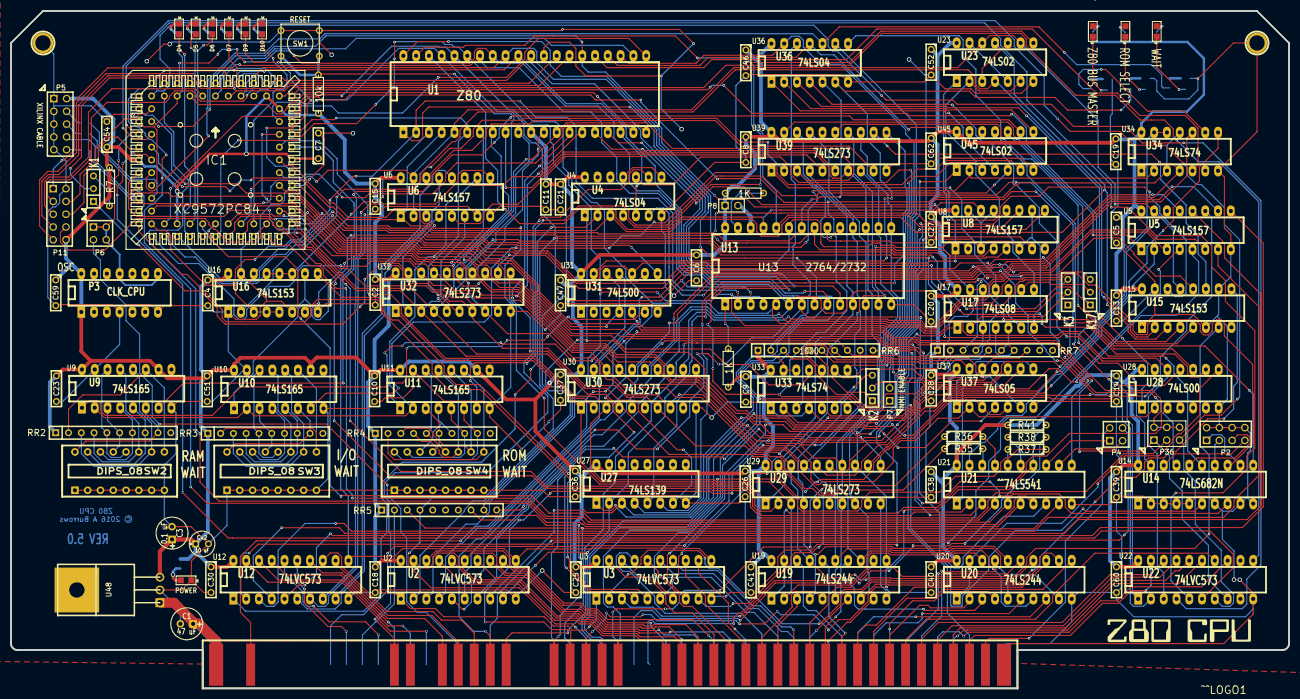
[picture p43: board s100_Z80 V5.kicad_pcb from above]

Board: 2 copper layers, 254.0 x 134.6 mm, 139 parts (0 on the bottom side), 300 nets.

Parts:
C1: 47 uF; C1V7
C2, C4, C5, C6, C7, C8, C9, C10, C11, C13, C14, C15, C18, C19, C20, C23, C25, C26, C27, C28, C30, C36, C37, C38, C39, C40, C41, C46, C47, C51, C52, C54, C59, C60, C62: 0.1 uF; C2
C3: 0.1 uF; C1V7
C21: 100nF; C2
Cx2: 10 uF; C1V5
D1: ACTIVE; ^^LED-0805
D2: ROM; ^^LED-0805
D3: WAIT; ^^LED-0805
D4, D5, D6, D7, D9, D10: CP1; ^^LED-0805
D8: D2-1; ^^LED-0805
IC1: XC9572PC84; ^^XILINX-PLCC-S84
K1: ROM LOCK; SIL-3
K2: CONN_3; SIL-3
K3: SLAVE_CLR; SIL-3
K17: EN_WAITS; SIL-3
P1: S100_MALE
P2: CONN_4X2; pin_array_4x2
P3: CLK_CPU; DIP-14__300_ELL
P4: CONN_2X2; PIN_ARRAY_2X2
P5: XILINX CABLE2; PIN_ARRAY_5X2
P6: CLK SEL; PIN_ARRAY_2X2
P7: NMI; PIN_ARRAY_2X1
P8: CONN_2; PIN_ARRAY_2X1
P11: CONN_5X2; PIN_ARRAY_5X2
P34, P35: CONN_1; 1pin
P36: CONN_3X2; pin_array_3x2
Q1, Q2, Q3: ^^NPN-SOT23; ^^SOT-23
R1, R3, R4, R8, R13, R14, R15, R16, R17, R18: 330; ^^SMD_Resistor-0805
R2, R6, R9: 470; ^^SMD_Resistor-0805
R5, R20: 1K; R3
R7: 4K7; R3
R10, R11, R12: 100; ^^SMD_Resistor-0805
R19: 10k; R3
R35, R36, R37, R38: 10; R3
R41: 4700; R3
RR2, RR3, RR4, RR5, RR6: 1000; r_pack9
RR7: 4700; r_pack9
SW1: RESET; SW_PUSH_SMALL
SW2, SW3, SW4: DIPS_08; SWDIP8
U1: Z80; DIP-40__600_ELL
U2, U3, U12, U22: 74LVC573; DIP-20__300_ELL
U4: 74LS04; 14DIP-ELL300
U5, U6: 74LS157; 16DIP-ELL300
U8: 74LS157; DIP-16__300_ELL
U9, U10, U11: 74LS165; DIP-16__300_ELL
U13: 2764; DIP-28__600_ELL
U14: 74LS682N; DIP-20__300_ELL
U15: 74LS153; DIP-16__300_ELL
U16: 74LS153; 16DIP-ELL300
U17: 74LS08; DIP-14__300_ELL
U19, U20: 74LS244; DIP-20__300_ELL
U21: ^^74LS541; DIP-20__300_ELL
U23, U45: 74LS02; DIP-14__300_ELL
U26: ^^LOGO1; ***Z80cpuV32
U27: 74LS139; DIP-16__300_ELL
U28, U31: 74LS00; DIP-14__300_ELL
U29, U30, U32, U39: 74LS273; DIP-20__300_ELL
U33, U34: 74LS74; DIP-14__300_ELL
U36: 74LS04; DIP-14__300_ELL
U37: 74LS05; DIP-14__300_ELL
U48: LDO_REG_7805; ^^TO220

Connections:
/27_ROM_LOCK: K1.1, U32.19
/27_ROM_OE: IC1.37, U13.22, U28.10, U36.5
/+8V: C1.1, P1.1, P1.51, U48.1
/A0: P1.79, U2.12
/A1: P1.80, U2.13
/A2: P1.81, U2.14
/A3: P1.31, U2.15
/A4: P1.30, U2.16
/A5: P1.29, U2.17
/A6: P1.82, U2.18
/A7: P1.83, U2.19
/A8: P1.84, U3.12
/A9: P1.34, U3.13
/A10: P1.37, U3.14
/A11: P1.87, U3.15
/A12: P1.33, U3.16
/A13: P1.85, U3.17
/A14: P1.86, U3.18
/A15: P1.32, U3.19
/A16: P1.16, U12.12
/A17: P1.17, U12.13
/A18: P1.15, U12.14
/A19: P1.59, U12.15
/A20: P1.61, U12.16
/A21: P1.62, U12.17
/A22: P1.63, U12.18
/A23: P1.64, U12.19
/ADSB: U2.1, U3.1, U4.2, U12.1
/ADSB*: P1.22, RR5.9, U4.1, U37.4
/BUSAK*: U1.23, U36.13, U37.11
/BUSRQ*: U1.25, U34.5
/CDSB*: P1.19, RR6.7, U37.8, U37.13
/CLK_CPU: IC1.68, U1.6, U9.2, U10.2, U11.2, U33.11
/CLK_CPUneg: IC1.70, U33.3, U34.3, U34.11
/CLK_OSC: IC1.9, P3.8, P3.11, P6.1, P6.2, P6.4
/CLOCK*: P1.49, P4.2
/CPLD2_TCK: IC1.30, R10.1
/CPLD2_TDI: IC1.28, R11.1
/CPLD2_TDO: IC1.59, P5.8
/CPLD2_TMS: IC1.29, R12.1
/CPLD_CLKout1: IC1.10, U21.7
/CPLD_CLKout2: IC1.12, U21.6
/CPLD_P1: IC1.1, U1.22
/CPLD_P2: IC1.2, U1.34, U2.5, U13.6, U14.11
/CPLD_P3: IC1.3, P11.9
/CPLD_P4: IC1.4, P11.5
/CPLD_P5: IC1.5, K1.2
/CPLD_P6: IC1.6, U1.19
/CPLD_P7: IC1.7, U1.33, U2.6, U13.7, U14.8
/CPLD_P11: IC1.11, U1.28
/CPLD_P13: IC1.13, U22.4
/CPLD_P14: IC1.14, P36.1, U22.8
/CPLD_P15: IC1.15, P11.4
/CPLD_P17: IC1.17, RR7.4, U1.26, U17.3, U17.12, U17.13, U34.10
/CPLD_P18: IC1.18, U22.5
/CPLD_P19: IC1.19, P36.5, U22.7
/CPLD_P20: IC1.20, U22.6
/CPLD_P21: IC1.21, U1.4, U4.3, U6.1, U15.3, U23.11
/CPLD_P23: IC1.23, P11.6
/CPLD_P24: IC1.24, U1.8, U13.15, U19.11, U20.9, U29.13, U30.13, U32.13, U39.13
/CPLD_P25: IC1.25, R9.2, U36.10
/CPLD_P26: IC1.26, U1.5, U5.15, U6.15, U15.13, U23.9, U23.12
/CPLD_P31: IC1.31, U1.12, U13.13, U19.13, U20.7, U29.14, U30.14, U32.14, U39.14
/CPLD_P32: IC1.32, U1.15, U13.12, U19.15, U20.5, U29.17, U30.17, U32.17, U39.17
/CPLD_P33: IC1.33, U1.14, U13.11, U19.17, U20.3, U29.18, U30.18, U32.18, U39.18
/CPLD_P34: IC1.34, U1.2, U13.2, U16.3, U16.4, U16.5
/CPLD_P35: IC1.35, U1.3, U16.11, U16.12, U16.13
/CPLD_P36: IC1.36, U1.36, U2.3, U13.4, U14.15
/CPLD_P39: D4.1, IC1.39
/CPLD_P40: D5.1, IC1.40
/CPLD_P41: D6.1, IC1.41
/CPLD_P43: IC1.43, U1.35, U2.4, U13.5, U14.13
/CPLD_P44: IC1.44, U21.4
/CPLD_P45: IC1.45, U1.7, U13.16, U19.8, U20.12, U29.8, U30.8, U32.8, U39.8
/CPLD_P46: IC1.46, U21.3
/CPLD_P47: IC1.47, P36.3
/CPLD_P48: IC1.48, U22.3, U28.12
/CPLD_P50: D10.1, IC1.50
/CPLD_P51: IC1.51, U21.5
/CPLD_P52: IC1.52, P11.8
/CPLD_P53: IC1.53, U1.10, U13.18, U19.4, U20.16, U29.4, U30.4, U32.4, U39.4
/CPLD_P54: IC1.54, U8.1, U23.2, U23.6, U31.10
/CPLD_P55: IC1.55, U21.2
/CPLD_P56: IC1.56, U1.9, U13.17, U19.6, U20.14, U29.7, U30.7, U32.7, U39.7
/CPLD_P57: IC1.57, U1.13, U13.19, U19.2, U20.18, U29.3, U30.3, U32.3, U39.3
/CPLD_P58: IC1.58, U31.4, U31.9, U31.12
/CPLD_P61: IC1.61, U28.9
/CPLD_P62: D9.1, IC1.62
/CPLD_P63: IC1.63, U1.20
/CPLD_P65: IC1.65, U29.2
/CPLD_P66: IC1.66, U2.11, U3.11, U12.11
/CPLD_P67: IC1.67, U30.2
/CPLD_P69: IC1.69, U21.8
/CPLD_P71: IC1.71, U1.37, U2.2, U13.3, U14.17
/CPLD_P72: IC1.72, U1.21
/CPLD_P74: IC1.74, U28.1
/CPLD_P75: IC1.75, P11.1
/CPLD_P76: IC1.76, U22.11
/CPLD_P77: IC1.77, P11.7
/CPLD_P79: IC1.79, P11.3
/CPLD_P80: IC1.80, U1.30, U2.9, U13.10, U27.2
/CPLD_P81: D7.1, IC1.81
/CPLD_P82: IC1.82, U1.32, U2.7, U13.8, U14.6
/CPLD_P83: IC1.83, U1.31, U2.8, U13.9, U27.3
/CPLD_P84: IC1.84, U1.27
/DATA_OUT_ENABLE: U20.1, U20.19, U28.8
/DI0: P1.95, U20.17
/DI1: P1.94, U20.15
/DI2: P1.41, U20.13
/DI3: P1.42, U20.11
/DI4: P1.91, U20.8
/DI5: P1.92, U20.6
/DI6: P1.93, U20.4
/DI7: P1.43, U20.2
/DO0: P1.36, U19.3
/DO1: P1.35, U19.5
/DO2: P1.88, U19.7
/DO3: P1.89, U19.9
/DO4: P1.38, U19.12
/DO5: P1.39, U19.14
/DO6: P1.40, U19.16
/DO7: P1.90, U19.18
/DODSB*: P1.23, RR5.8, U28.2, U37.2
/ERROR*: P1.98, RR6.10
/HALT*: U1.18, U4.5
/HOLD*: P1.74, RR5.4, U34.2, U45.2
/INT*: P1.73, RR5.3, U21.9
/MWRT: P1.68, P4.4
/NDEF3: P1.66, P6.3
/NMI*: P7.1, RR6.4, U1.17
/NMI*s100: P1.12, U4.9
/PHI: P1.24, R41.2, U21.14
/PU1K-J: RR6.2, U33.12, U33.13, U36.12
/PU1K-JJ: P1.60, RR5.2
/PU1K-K: P1.26, RR6.3, U37.10
/PU1K-N: K2.1, RR6.5
/PU1K-R: K3.3, RR6.6
/PU1K-T: P1.18, RR6.8, U36.9, U37.6
/PU1K-Y: P1.58, RR6.9
/PU1K-waits: K17.3, RR5.10
/PU5K-A: RR7.2, U33.10
/PU5K-B: RR7.3, U34.1, U34.4
/PU5K-D: RR7.5, U33.1, U33.4
/PU5K-E: P1.3, RR7.6, U17.5
/PU5K-H: P1.72, RR7.7, U17.4
/PU5K-I: RR7.8, U21.1, U37.12
/RESET*: P1.75, R19.2, SW1.2, U17.1
/ROM_SELECT: R6.2, U31.13, U36.6
/WAIT*: U1.24, U17.8, U36.11
/Z80_ACTIVE: R2.2, U34.9
/bA8: U1.38, U8.14, U13.25
/bA9: U1.39, U8.11, U13.24
/bA10: U1.40, U8.5, U13.21
/bA11: U1.1, U8.2, U13.23
/bINT*: U1.16, U21.11
/pDBIN: P1.78, R35.1
/pSTVAL*: P1.25, R37.1
/pSYNC: P1.76, R36.1
/pWR*: P1.77, R38.1
/sHLTA: P1.48, U22.19
/sINP: P1.46, U22.17
/sINTA: P1.96, U22.13
/sM1: P1.44, U22.14
/sMEMR: P1.47, U22.16
/sOUT: P1.45, U22.18
/sWO*: P1.97, U22.15
GND: C1.2, C2.2, C3.2, C4.2, C5.2, C6.2, C7.2, C8.2, C9.2, C10.2, C11.2, C13.2, C14.2, C15.2, C18.2, C19.2, C20.2, C21.2, C23.2, C25.2, C26.2, C27.2, C28.2, C30.2, C36.2, C37.2, C38.2, C39.2, C40.2, C41.2, C46.2, C47.2, C51.2, C52.2, C54.2, C59.2, C60.2, C62.2, Cx2.2, D8.2, IC1.8, IC1.16, IC1.27, IC1.42, IC1.49, IC1.60, P1.50, P1.100, P2.2, P2.4, P2.6, P2.8, P3.4, P3.7, P5.1, P5.3, P5.5, P5.7, P5.9, P11.2, P34.1, P35.1, Q1.2, Q2.2, Q3.2, R13.1, R14.1, R15.1, R16.1, R17.1, R18.1, SW1.1, SW2.1, SW2.2, SW2.3, SW2.4, SW2.5, SW2.6, SW2.7, SW2.8, SW3.1, SW3.2, SW3.3, SW3.4, SW3.5, SW3.6, SW3.7, SW3.8, SW4.1, SW4.2, SW4.3, SW4.4, SW4.5, SW4.6, SW4.7, SW4.8, U1.29, U2.10, U3.10, U4.7, U5.8, U6.8, U8.3, U8.6, U8.8, U8.10, U8.13, U8.15, U9.8, U9.15, U10.8, U10.15, U11.8, U11.15, U12.10, U13.14, U13.20, U14.2, U14.3, U14.4, U14.5, U14.7, U14.9, U14.10, U15.1, U15.6, U15.8, U15.10, U15.15, U16.1, U16.6, U16.8, U16.10, U16.15, U17.7, U19.10, U20.10, U21.10, U22.10, U23.7, U27.8, U28.7, U29.10, U30.10, U31.7, U32.10, U33.7, U34.7, U36.7, U37.7, U39.10, U45.7, U48.2
unnamed: K1.3, R7.2
unnamed: U4.4, U23.8
unnamed: U5.6, U30.15
unnamed: U5.1, U39.19
unnamed: U5.3, U30.12
unnamed: U5.4, U12.2
unnamed: U5.5, U29.15
unnamed: U5.10, U30.19
unnamed: U5.11, U29.19
unnamed: U3.5, U16.7
unnamed: U3.6, U8.4
unnamed: U3.8, U8.9
unnamed: U6.14, U39.9
unnamed: U6.5, U39.5
unnamed: U3.3, U15.7
unnamed: U27.7, U32.11
unnamed: U5.12, U12.4
unnamed: P5.4, R12.2
unnamed: P5.6, R10.2
unnamed: P5.10, R11.2
unnamed: U5.13, U30.16
unnamed: U5.2, U29.12
unnamed: K17.1, U45.10
unnamed: U36.1, U45.4
unnamed: U27.5, U30.11
unnamed: U5.9, U12.5
unnamed: U5.7, U12.3
unnamed: U5.14, U29.16
unnamed: U27.4, U29.11
unnamed: U36.2, U45.8
unnamed: U15.11, U39.12
unnamed: U6.3, U32.2
unnamed: U6.4, U12.6
unnamed: U6.6, U32.5
unnamed: U6.9, U12.8
unnamed: U6.10, U32.6
unnamed: U6.12, U12.9
unnamed: U6.13, U32.9
unnamed: U23.3, U23.10
unnamed: U15.14, U16.14, U23.1
unnamed: U15.2, U16.2, U23.4
unnamed: U23.5, U23.13
unnamed: U3.4, U16.9
unnamed: U3.2, U15.9
unnamed: U6.11, U39.6
unnamed: U15.5, U39.15
unnamed: U6.2, U39.2
unnamed: U3.9, U8.12
unnamed: U3.7, U8.7
unnamed: U6.7, U12.7
unnamed: U15.12, U32.12
unnamed: U15.4, U32.15
unnamed: U27.6, U39.11
unnamed: U17.11, U29.1, U30.1, U32.1, U39.1
unnamed: U14.19, U36.3
unnamed: K3.2, U17.2
unnamed: U22.1, U36.8
unnamed: U4.6, U22.2
unnamed: R20.2, U13.1
unnamed: R5.2, U13.27
unnamed: P8.2, U13.26
unnamed: U17.6, U17.10
unnamed: K17.2, U17.9
unnamed: P7.2, U4.10
unnamed: U4.8, U4.11
unnamed: D4.2, R13.2
unnamed: D9.2, R17.2
unnamed: D7.2, R16.2
unnamed: D6.2, R15.2
unnamed: D5.2, R14.2
unnamed: U11.7, U45.5
unnamed: U10.7, U45.6
unnamed: D10.2, R18.2
unnamed: R37.2, U21.16
unnamed: R35.2, U21.18
unnamed: K2.3, U33.6
unnamed: K2.2, U34.12, U34.13
unnamed: U33.2, U45.1
unnamed: U33.8, U45.3
unnamed: P36.2, P36.4, P36.6, U31.5
unnamed: D1.1, R1.1
unnamed: D1.2, Q2.3
unnamed: Q2.1, R2.1
unnamed: D2.1, R3.1
unnamed: D2.2, Q3.3
unnamed: Q3.1, R6.1
unnamed: U10.1, U31.8
unnamed: RR3.5, SW3.12, U10.14
unnamed: RR3.8, SW3.15, U10.5
unnamed: RR3.9, SW3.16, U10.6
unnamed: RR3.6, SW3.13, U10.3
unnamed: RR3.7, SW3.14, U10.4
unnamed: RR4.7, SW4.14, U11.4
unnamed: RR4.6, SW4.13, U11.3
unnamed: RR4.8, SW4.15, U11.5
unnamed: RR4.5, SW4.12, U11.14
unnamed: RR4.9, SW4.16, U11.6
unnamed: U33.9, U37.1, U37.3, U37.5
unnamed: P4.1, U21.13
unnamed: P4.3, U21.12
unnamed: U33.5, U37.9
unnamed: RR2.5, SW2.12, U9.14
unnamed: RR2.9, SW2.16, U9.6
unnamed: RR2.6, SW2.13, U9.3
unnamed: RR2.7, SW2.14, U9.4
unnamed: RR2.8, SW2.15, U9.5
unnamed: U9.7, U45.9
unnamed: U9.1, U31.6
unnamed: U28.13, U36.4
unnamed: D3.1, R8.1
unnamed: D3.2, Q1.3
unnamed: Q1.1, R9.1
unnamed: D8.1, R4.1
unnamed: RR4.3, SW4.10, U11.12
unnamed: RR4.4, SW4.11, U11.13
unnamed: RR4.2, SW4.9, U11.11
unnamed: RR3.4, SW3.11, U10.13
unnamed: RR3.3, SW3.10, U10.12
unnamed: RR3.2, SW3.9, U10.11
unnamed: U11.1, U31.11
unnamed: U19.1, U19.19, U28.3
unnamed: P2.1, U14.12
unnamed: P2.3, U14.14
unnamed: P2.5, U14.16
unnamed: P2.7, U14.18
unnamed: U27.1, U28.11
unnamed: R36.2, U21.17
unnamed: R38.2, U21.15
unnamed: U21.19, U34.8
unnamed: RR2.3, SW2.10, U9.12
unnamed: RR2.4, SW2.11, U9.13
unnamed: RR2.2, SW2.9, U9.11
VCC: C2.1, C3.1, C4.1, C5.1, C6.1, C7.1, C8.1, C9.1, C10.1, C11.1, C13.1, C14.1, C15.1, C18.1, C19.1, C20.1, C21.1, C23.1, C25.1, C26.1, C27.1, C28.1, C30.1, C36.1, C37.1, C38.1, C39.1, C40.1, C41.1, C46.1, C47.1, C51.1, C52.1, C54.1, C59.1, C60.1, C62.1, Cx2.1, IC1.22, IC1.38, IC1.64, IC1.73, IC1.78, P3.1, P3.14, P5.2, P8.1, P11.10, R1.2, R3.2, R4.2, R5.1, R7.1, R8.2, R19.1, R20.1, R41.1, RR2.1, RR3.1, RR4.1, RR5.1, RR6.1, RR7.1, U1.11, U2.20, U3.20, U4.14, U5.16, U6.16, U8.16, U9.10, U9.16, U10.10, U10.16, U11.10, U11.16, U12.20, U13.28, U14.20, U15.16, U16.16, U17.14, U19.20, U20.20, U21.20, U22.20, U23.14, U27.16, U28.14, U29.20, U30.20, U31.14, U32.20, U33.14, U34.14, U36.14, U37.14, U39.20, U45.14, U48.3

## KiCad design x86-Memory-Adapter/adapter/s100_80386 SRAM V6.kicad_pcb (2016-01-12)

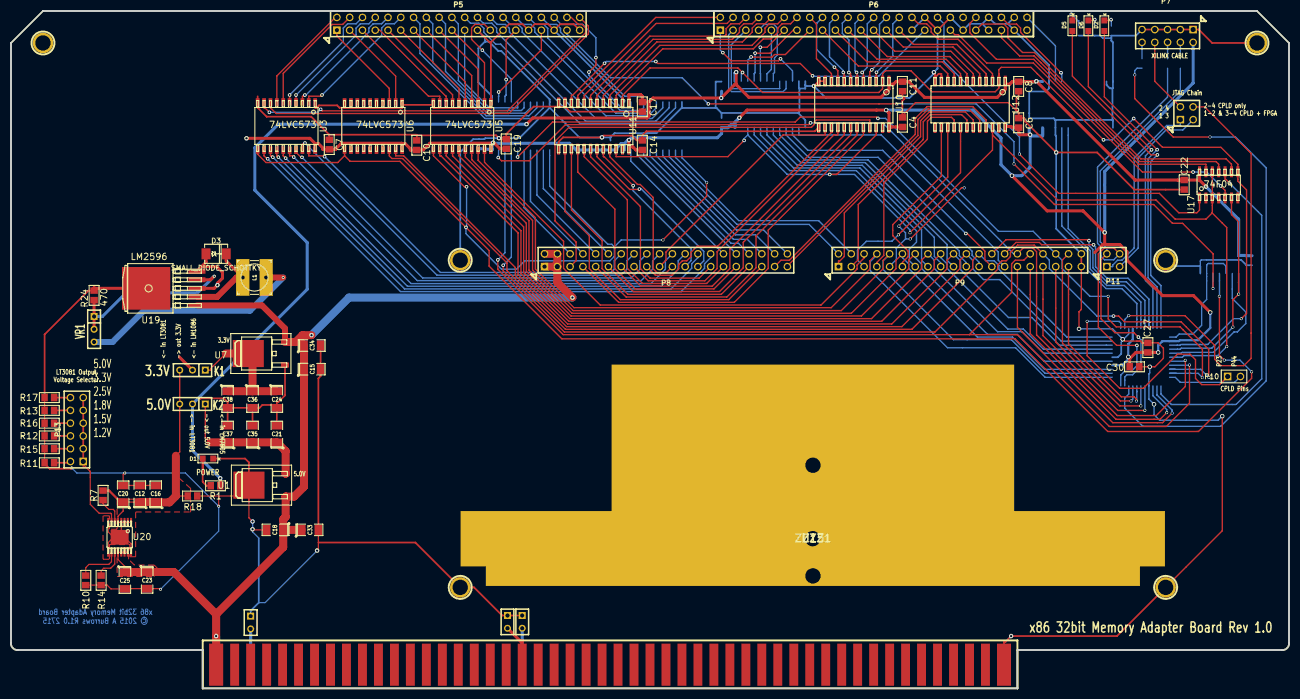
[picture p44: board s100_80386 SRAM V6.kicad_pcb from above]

Board: 2 copper layers, 254.0 x 134.6 mm, 98 parts (0 on the bottom side), 199 nets.

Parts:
C1, C3, C4, C6, C7, C8, C9, C10, C11, C13, C14, C17, C19, C22, C26, C27, C28, C30, C32: 0.1 uF; ^^SMD_Resistor-0805
C12, C15, C16, C18, C20, C21, C23, C24, C25, C33, C34, C35, C36, C37, C38: 10 uF; SM1206_Opendous
D1: POWER; ^^LED-0805
D2, D5, D6: LED; ^^LED-0805
D3: SMALL_DIODE_SCHOTTKY; DO-214AA(SMB)
JP5, JP6, JP7: JUMPER; SIL-2
K1: 3.3V; SIL-3
K2: 5V; SIL-3
L1: SMALL_INDUCTANCE; Inductor_CDRH6D28
P1, P2, P3, P4, P34, P35: CONN_1; 1pin
P5, P8, P9: CONN_20X2; PIN_ARRAY_20X2
P6: CONN_25X2; PIN_ARRAY_30X2
P7: XILINX CABLE2; PIN_ARRAY_5X2
P10: CPLD Spare; PIN_ARRAY_2X1
P11: CONN_2X2; PIN_ARRAY_2X2
P12: JTAG CHAIN; PIN_ARRAY_2X2
P13: LT Output select; PIN_ARRAY_6X2
P20: S100_MALE
R1, R5, R6, R8: 330; ^^SMD_Resistor-0805
R2, R3, R4: 100; ^^SMD_Resistor-0805
R7: 4.53k; ^^SMD_Resistor-0805
R10: 500; ^^SMD_Resistor-0805
R11: 24.3K; ^^SMD_Resistor-0805
R12: 36.5K; ^^SMD_Resistor-0805
R13: 66.5K; ^^SMD_Resistor-0805
R14: 1K; ^^SMD_Resistor-0805
R15: 30.1K; ^^SMD_Resistor-0805
R16: 49.9K; ^^SMD_Resistor-0805
R17: 100K; ^^SMD_Resistor-0805
R18: 300; ^^SMD_Resistor-0805
R24: 470; ^^SMD_Resistor-0805
U1: LDO_REG_7805; ^^L7805C-TO252-2pin+tab
U2, U3, U4, U5, U6: 74LVC573; ^^SO-20wide
U7: LM1086CS_TO252_DPAK; -TO252
U8: 74F14; ^^SO14_wide
U9, U10, U11, U12, U13: 74LVX3245; ^^SO24W
U14: XC9572XL-VQ44; XILINX-VQ44
U15: ZZZZ1; ^^ZZZZZZ1
U17: 74F04; ^^SO14_wide
U19: LM2596; ^^TO263-51
U20: LT3081; ^^LT3081_TSSOP16
VR1: VR1; ^^Variable_Resistor

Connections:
/0V_A: JP5.2, P20.20
/0V_B: JP6.2, P20.53
/0V_C: JP7.2, P20.70
/+8Vi: C15.1, C18.1, C23.1, C25.1, C33.1, C34.1, P8.1, P8.2, P8.3, P8.4, P20.1, P20.51, U1.1, U7.2, U19.1, U20.12, U20.13, U20.14, U20.15
/BOARD_SELECT: D2.1, U14.32
/CLK: U14.1, U17.10
/CPLD1_TCK: P11.4, R2.1, U14.11
/CPLD1_TDI: R3.1, U14.9
/CPLD1_TDO: P12.4, U14.24
/CPLD1_TMS: P11.2, R4.1, U14.10
/CPLD_P2: P9.29, U14.2
/CPLD_P3: P9.31, U14.3
/CPLD_P5: P9.33, U14.5
/CPLD_P6: P9.35, U14.6
/CPLD_P7: P9.37, U14.7
/CPLD_P8: P9.38, U14.8
/CPLD_P12: P9.8, U5.18, U14.12
/CPLD_P13: P9.10, U5.17, U14.13
/CPLD_P14: P9.12, U5.16, U14.14
/CPLD_P16: P9.14, U5.15, U14.16
/CPLD_P18: P9.16, U5.14, U14.18
/CPLD_P19: P9.18, U5.13, U14.19
/CPLD_P20: P9.20, U5.12, U14.20
/CPLD_P21: P9.22, U6.19, U14.21
/CPLD_P22: P9.24, U6.18, U14.22
/CPLD_P23: P10.1, U14.23
/CPLD_P27: U9.21, U14.27
/CPLD_P28: U9.20, U14.28
/CPLD_P29: P9.26, U14.29
/CPLD_P30: P9.28, U14.30
/CPLD_P31: D6.1, U14.31
/CPLD_P33: D5.1, U14.33
/CPLD_P34: U8.3, U8.6, U14.34
/CPLD_P36: U10.2, U11.2, U12.2, U13.2, U14.36, U17.8
/CPLD_P37: U8.1, U14.37, U17.6
/CPLD_P38: U8.2, U14.38
/CPLD_P39: U10.22, U11.22, U12.22, U13.22, U14.39, U17.3, U17.12
/CPLD_P40: P9.30, U2.19, U14.40
/CPLD_P41: P9.32, U2.18, U14.41
/CPLD_P42: P9.34, U2.17, U14.42
/CPLD_P43: P9.36, U2.16, U14.43
/CPLD_P44: P10.2, U14.44
/D0: P6.30, U10.3
/D1: P6.28, U10.4
/D2: P6.26, U10.5
/D3: P6.24, U10.6
/D4: P6.22, U10.7
/D5: P6.20, U10.8
/D6: P6.18, U10.9
/D7: P6.16, U10.10
/D8: P6.14, U11.3
/D9: P6.12, U11.4
/D10: P6.10, U11.5
/D11: P6.8, U11.6
/D12: P6.6, U11.7
/D13: P6.4, U11.8
/D14: P6.2, U11.9
/D15: P6.33, U11.10
/D16: P6.32, U12.3
/D17: P6.29, U12.4
/D18: P6.27, U12.5
/D19: P6.25, U12.6
/D20: P6.23, U12.7
/D21: P6.21, U12.8
/D22: P6.19, U12.9
/D23: P6.17, U12.10
/D24: P6.15, U13.3
/D25: P6.13, U13.4
/D26: P6.11, U13.5
/D27: P6.9, U13.6
/D28: P6.7, U13.7
/D29: P6.5, U13.8
/D30: P6.3, U13.9
/D31: P6.1, U13.10
/DB_ADS: U2.11, U3.11, U4.11, U5.11, U6.11, U8.4
/DB_PHANTOM*: P6.50, U9.3
/DB_WAIT: P6.46, U9.4
/FPGA_TDI: P11.3, P12.3
/FPGA_TDO: P11.1, P12.1
/LM1086 out: C24.1, C36.1, C38.1, K1.1, U7.3
/LM2596output: L1.2, VR1.3
/LM7805 out: C21.1, C35.1, C37.1, K2.1, U1.3
/LTout: C12.1, C16.1, C20.1, K1.3, K2.3, R7.1, R18.1, U20.1, U20.2, U20.3, U20.4, U20.5, U20.8, U20.9, U20.16, U20.17
/S100_SEL*: P6.42, U17.13
/TDO_1: P7.8, P12.2
/V3.3: C1.1, C3.1, C4.1, C6.1, C7.1, C10.1, C13.1, C14.1, C19.1, C26.1, C27.1, C30.1, K1.2, P7.2, U2.20, U3.20, U4.20, U5.20, U6.20, U9.24, U10.24, U11.24, U12.24, U13.24, U14.15, U14.26, U14.35
/bA2: P8.6, U2.15
/bA3: P8.8, U2.14
/bA4: P8.10, U2.13
/bA5: P8.12, U2.12
/bA6: P8.14, U3.19
/bA7: P8.16, U3.18
/bA8: P8.18, U3.17
/bA9: P8.20, U3.16
/bA10: P8.22, U3.15
/bA11: P8.24, U3.14
/bA12: P8.26, U3.13
/bA13: P8.28, U3.12
/bA14: P8.30, U4.19
/bA15: P8.32, U4.18
/bA16: P8.34, U4.17
/bA17: P8.36, U4.16
/bA18: P8.38, U4.15
/bA19: P8.40, U4.14
/bA20: P9.2, U4.13
/bA21: P9.4, U4.12
/bA22: P9.6, U5.19
/bD0: P8.5, U10.21
/bD1: P8.7, U10.20
/bD2: P8.9, U10.19
/bD3: P8.11, U10.18
/bD4: P8.13, U10.17
/bD5: P8.15, U10.16
/bD6: P8.17, U10.15
/bD7: P8.19, U10.14
/bD8: P8.21, U11.21
/bD9: P8.23, U11.20
/bD10: P8.25, U11.19
/bD11: P8.27, U11.18
/bD12: P8.29, U11.17
/bD13: P8.31, U11.16
/bD14: P8.33, U11.15
/bD15: P8.35, U11.14
/bD16: P8.37, U12.21
/bD17: P8.39, U12.20
/bD18: P9.1, U12.19
/bD19: P9.3, U12.18
/bD20: P9.5, U12.17
/bD21: P9.7, U12.16
/bD22: P9.9, U12.15
/bD23: P9.11, U12.14
/bD24: P9.13, U13.21
/bD25: P9.15, U13.20
/bD26: P9.17, U13.19
/bD27: P9.19, U13.18
/bD28: P9.21, U13.17
/bD29: P9.23, U13.16
/bD30: P9.25, U13.15
/bD31: P9.27, U13.14
/cA20: P5.24, U4.8
/cA21: P5.22, U4.9
/cA22: P5.19, U5.2
/cA23: P5.17, U5.3
/cA24: P5.15, U5.4
/cA25: P5.13, U5.5
/cA26: P5.11, U5.6
/cA27: P5.9, U5.7
/cA28: P5.7, U5.8
/cA29: P5.5, U5.9
/cA30: P5.3, U6.2
/cA31: P5.1, U6.3
/mA2: P5.20, U2.6
/mA3: P5.18, U2.7
/mA4: P5.16, U2.8
/mA5: P5.14, U2.9
/mA6: P5.12, U3.2
/mA7: P5.10, U3.3
/mA8: P5.8, U3.4
/mA9: P5.6, U3.5
/mA10: P5.4, U3.6
/mA11: P5.2, U3.7
/mA12: P5.40, U3.8
/mA13: P5.38, U3.9
/mA14: P5.36, U4.2
/mA15: P5.34, U4.3
/mA16: P5.32, U4.4
/mA17: P5.30, U4.5
/mA18: P5.28, U4.6
/mA19: P5.26, U4.7
/mBE0*: P5.33, U2.2
/mBE1*: P5.29, U2.3
/mBE2*: P5.25, U2.4
/mBE3*: P5.21, U2.5
GND: C1.2, C3.2, C4.2, C6.2, C7.2, C8.2, C9.2, C10.2, C11.2, C12.2, C13.2, C14.2, C15.2, C16.2, C17.2, C18.2, C19.2, C20.2, C21.2, C22.2, C23.2, C24.2, C25.2, C26.2, C27.2, C28.2, C30.2, C32.2, C33.2, C34.2, C35.2, C36.2, C37.2, C38.2, D1.2, D3.1, JP5.1, JP6.1, JP7.1, P1.1, P2.1, P3.1, P4.1, P5.23, P5.27, P5.31, P5.35, P5.39, P6.31, P6.34, P6.35, P6.38, P6.39, P6.43, P6.44, P6.47, P6.48, P7.1, P7.3, P7.5, P7.7, P7.9, P9.39, P9.40, P20.50, P20.100, P34.1, P35.1, R5.1, R6.1, R8.1, R10.2, R11.2, R12.2, R13.2, R14.2, R15.2, R16.2, R17.2, R18.2, R24.2, U1.2, U2.1, U2.10, U3.1, U3.10, U4.1, U4.10, U5.1, U5.10, U6.1, U6.10, U7.1, U8.7, U9.2, U9.11, U9.12, U9.13, U9.22, U10.11, U10.12, U10.13, U11.11, U11.12, U11.13, U12.11, U12.12, U12.13, U13.11, U13.12, U13.13, U14.4, U14.17, U14.25, U19.3, U19.5, U19.6
unnamed: P7.6, R2.2
unnamed: P7.4, R4.2
unnamed: P7.10, R3.2
unnamed: D1.1, R1.2
unnamed: P13.2, R11.1
unnamed: R14.1, U20.11
unnamed: P13.4, R15.1
unnamed: P13.6, R12.1
unnamed: P13.8, R16.1
unnamed: P13.1, P13.3, P13.5, P13.7, P13.9, P13.11, U20.7
unnamed: P13.10, R13.1
unnamed: P13.12, R17.1
unnamed: R10.1, U20.10
unnamed: R7.2, U20.6
unnamed: D2.2, R8.2
unnamed: R24.1, U19.4, VR1.1, VR1.2
unnamed: D3.2, L1.1, U19.2
unnamed: D6.2, R5.2
unnamed: D5.2, R6.2
unnamed: P6.41, U17.9
unnamed: P5.37, U8.5
unnamed: P6.37, U17.5
unnamed: P6.36, U17.1
unnamed: P6.45, U17.11
VCC: C8.1, C9.1, C11.1, C17.1, C22.1, C28.1, C32.1, K2.2, R1.1, U8.14, U9.1, U10.1, U11.1, U12.1, U13.1, U17.14

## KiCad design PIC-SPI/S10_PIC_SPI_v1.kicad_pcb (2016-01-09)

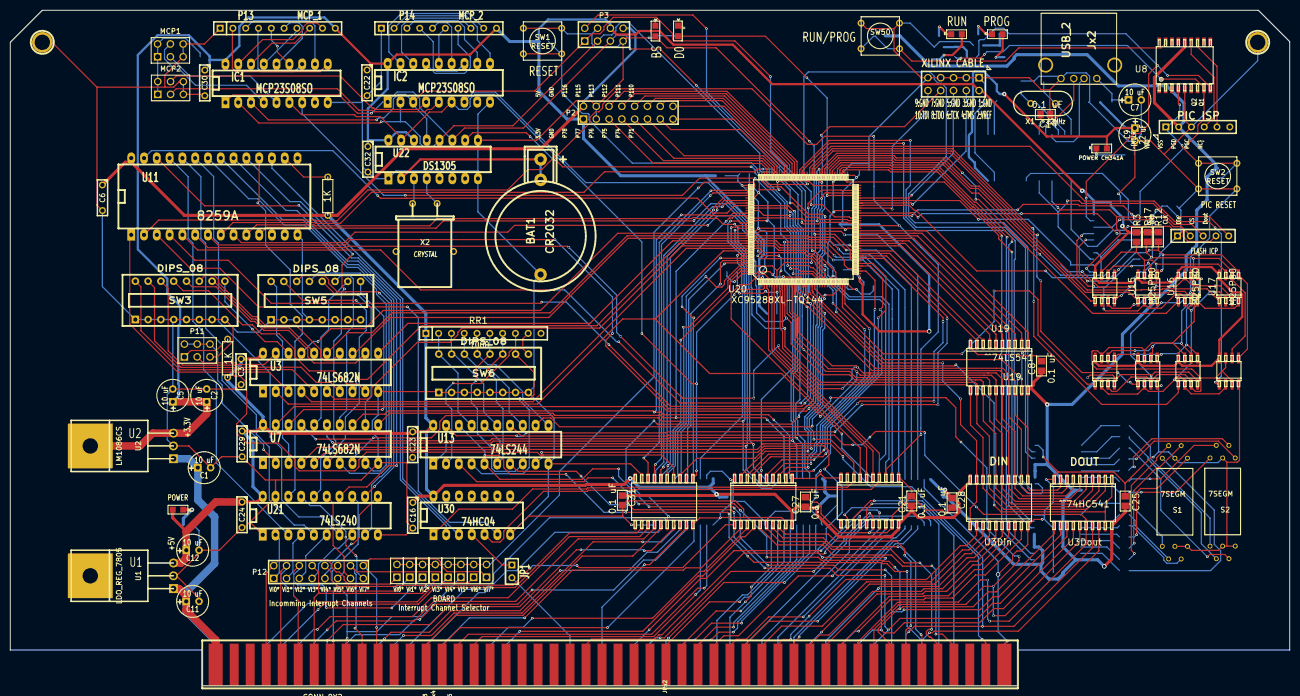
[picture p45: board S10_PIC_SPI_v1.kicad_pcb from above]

Board: 2 copper layers, 254.0 x 134.1 mm, 163 parts (0 on the bottom side), 326 nets.

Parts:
BAT1: CR2032; ^^CR2032H
C1, C2, C5, C7, C11, C12: 10 uF; C1V7
C3, C6, C16, C22, C23, C24, C29, C30, C32: 0.1 uF; C2
C4, C8, C14, C17, C20, C21, C25, C27, C28, C31, C41, C42, C43: 0.1 uF; ^^SMD_Resistor-0805
C9: 22 uF; C1V7
C10, C18: 15 pF; ^^SMD_Resistor-0805
C13, C15: 0.01 uF; ^^SMD_Resistor-0805
C19, C26, C33, C34, C35, C36, C37, C38, C39, C40: C; ^^SMD_Resistor-0805
D1, D4: LED; ^^LED-0805
D5: POWER; ^^LED-0805
D7: BOARD_SELECT; ^^LED-0805
D8: POWER CH341A; ^^LED-0805
D9: D0; ^^LED-0805
IC1, IC2: MCP23S08SO; DIP-18__300_ELL
JP1: JUMPER; SIL-2
JPx1, JPx2, JPx3, JPx4, JPx5, JPx6, JPx7, JPx8: JUMPER; PIN_ARRAY_2X1
Jx2: USB_2; USB_A
MCP1, MCP2: CONN_3X2; PIN_ARRAY_3X2
P1: M25P80 ISP; SIL-5
P2: CONN_8X2; PIN_ARRAY_8x2
P3: EXT SPI; PIN_ARRAY_4X2
P4: S100_MALE
P5: PIC_ISP; SIL-6
P6, P7: CONN_1; 1pin
P8, P9: CONN_2; ^^SMD_Resistor-0805
P11: CONN_3X2; PIN_ARRAY_3X2
P12: CONN_8X2; pin_array_8x2
P13: MCP_1; SIL-10
P14: MCP_2; SIL-10
P19: XILINX CABLE2; PIN_ARRAY_5x2
Q1, Q2: ^^NPN-SOT23; ^^-SOT23
R1, R5, R14, R15, R20, R21, R29: 330; ^^SMD_Resistor-0805
R2, R18, R19, R28: 470; ^^SMD_Resistor-0805
R3, R31, R32, R33, R34, R35, R36, R37, R38, R39, R40, R41, R42, R43, R44: 1K; ^^SMD_Resistor-0805
R4, R8, R10, R30: 10k; ^^SMD_Resistor-0805
R6, R11: 1K; ^^R3
R7: 50; ^^SMD_Resistor-0805
R9, R12, R17: 10K; ^^SMD_Resistor-0805
R25, R26, R27: 100; ^^SMD_Resistor-0805
RR1: 1000; r_pack9
S1, S2: 7SEGM; ^^VQB71_7segment
SW1, SW2: RESET; SW_PUSH_SMALL
SW3, SW5, SW6: DIPS_08; SWDIP8
SW50: FLASH/RUN; SW_PUSH_SMALL
U1: LDO_REG_7805; ^^TO220
U2: LM1086CS; ^^TO220
U3, U7: 74LS682N; DIP-20__300_ELL
U3din1, U3dout1: ^^74HC541; ^^-SO20W
U4, U5, U6, U19, U31: ^^74LS541; ^^-SO20W
U8: PIC18F1330; -SO18-1
U9, U10: 74HC245; ^^-SO20W
U11: 8259A; DIP-28__600_ELL
U12: ^^74LV244; ^^-SO20W
U13: 74LS244; DIP-20__300_ELL
U14, U15, U16, U17, U23, U24, U25, U26: M25P80; -SO8
U18: CH341A; ^^-SO28W
U20: XC95288XL-TQ144; -TQFP144
U21: 74LS240; DIP-20__300_ELL
U22: DS1305; DIP-16__300_ELL
U27, U28: 74HC4511; ^^-SO16W
U30: 74HC04; DIP-14__300_ELL
Ux1: ^^3.3VREG_SOT223; -SOT223
X1: 12MHz; Crystal_HC-49U_Vert
X2: CRYSTAL; Crystal_HC-49U_Horiz

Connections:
/7SEG_0_D0: U20.74, U27.7
/7SEG_0_D1: U20.75, U27.1
/7SEG_0_D2: U20.76, U27.2
/7SEG_0_D3: U20.77, U27.6
/7SEG_1_D0: U20.106, U28.7
/7SEG_1_D1: U20.107, U28.1
/7SEG_1_D2: U20.91, U28.2
/7SEG_1_D3: U20.92, U28.6
/25Pxx_CS: U12.5, U12.14, U20.79
/25Pxx_SEL_0: U14.1, U20.80
/25Pxx_SEL_1: U15.1, U20.81
/25Pxx_SEL_2: U16.1, U20.82
/25Pxx_SEL_3: U17.1, U20.83
/25Pxx_SEL_4: U20.85, U23.1
/25Pxx_SEL_5: U20.86, U24.1
/25Pxx_SEL_6: U20.87, U25.1
/25Pxx_SEL_7: U20.88, U26.1
/+8V: C1.1, C11.1, P4.1, P4.51, U1.1, U2.1
//M1: U9.2, U20.43
/A0: P4.79, U4.2
/A0b: U4.18, U11.27, U20.117
/A1: P4.80, U4.3
/A1b: U4.17, U7.17, U20.118
/A2: P4.81, U4.4
/A2b: U4.16, U7.15, U20.119
/A3: P4.31, U4.5
/A3b: U4.15, U7.13, U20.120
/A4: P4.30, U4.6
/A4b: U4.14, U7.11, U20.121
/A5: P4.29, U4.7
/A5b: U4.13, U7.8, U20.124
/A6: P4.82, U4.8
/A6b: U4.12, U7.6, U20.125
/A7: P4.83, U4.9
/A7b: U4.11, U7.4, U20.126
/A8: P4.84, U5.2
/A8b: U3.17, U5.18, U20.128
/A9: P4.34, U5.3
/A9b: U3.15, U5.17, U20.129
/A10: P4.37, U5.4
/A10b: U3.13, U5.16, U20.130
/A11: P4.87, U5.5
/A11b: U3.11, U5.15, U20.131
/A12: P4.33, U5.6
/A12b: U3.8, U5.14, U20.132
/A13: P4.85, U5.7
/A13b: U3.6, U5.13, U20.133
/A14: P4.86, U5.8
/A14b: U3.4, U5.12, U20.134
/A15: P4.32, U5.9
/A15b: U3.2, U5.11, U20.135
/A16: P4.16, U6.2
/A16b: U6.18, U20.136
/A17: P4.17, U6.3
/A17b: U6.17, U20.137
/A18: P4.15, U6.4
/A18b: U6.16, U20.138
/A19: P4.59, U6.5
/A19b: U6.15, U20.139
/A20: P4.61, U6.6
/A20b: U6.14, U20.140
/A21: P4.62, U6.7
/A21b: U6.13, U20.142
/A22: P4.63, U6.8
/A22b: U6.12, U20.143
/A23: P4.64, U6.9
/A23b: U6.11, U20.116
/BOARD_INTERRUPT_VECTb: JPx1.2, JPx2.2, JPx3.2, JPx4.2, JPx5.2, JPx6.2, JPx7.2, JPx8.2, U20.110
/BOARD_SEL_LED: D7.1, U20.31
/CLOCK*: P4.49, U10.13
/CLOCK*b: U10.7, U20.5
/CPLD2_TCK: R25.1, U20.67
/CPLD2_TDI: R26.1, U20.63
/CPLD2_TDO: P19.8, U20.122
/CPLD2_TMS: R27.1, U20.65
/CPLD_45: U19.9, U20.45
/CPLD_46: U19.8, U20.46
/CPLD_48: U19.7, U20.48
/CPLD_49: U19.6, U20.49
/CPLD_68: D9.1, U20.68
/CPLD_71: P2.15, U20.100
/CPLD_74: P2.13, U20.101
/CPLD_75: P2.11, U20.102
/CPLD_76: P2.9, U20.103
/CPLD_77: P2.7, U20.104
/CPLD_78: P2.5, U20.105
/CPLD_110: P2.16, U20.98
/CPLD_111: P2.14, U20.97
/CPLD_112: P2.12, U20.96
/CPLD_113: P2.10, U20.95
/CPLD_115: P2.8, U20.94
/CPLD_116: P2.6, U20.93
/CPLD_130: U19.5, U20.50
/CPLD_131: U19.4, U20.51
/CPLD_132: U19.3, U20.52
/CPLD_133: U19.2, U20.53
/CPLD_134: U19.1, U19.19, U20.54
/CPLD_M25P80_CLK: U12.2, U20.60
/CPLD_M25P80_CS: U12.6, U20.64
/CPLD_M25P80_Din: U12.4, U20.61
/CPLD_M25P80_Dout: R9.2, U12.12, U20.66
/D0: U3din1.18, U3dout1.2, U11.11, U19.11, U20.9
/D1: U3din1.17, U3dout1.3, U11.10, U19.12, U20.10
/D2: U3din1.16, U3dout1.4, U11.9, U19.13, U20.11
/D3: U3din1.15, U3dout1.5, U11.8, U19.14, U20.12
/D4: U3din1.14, U3dout1.6, U11.7, U19.15, U20.13
/D5: U3din1.13, U3dout1.7, U11.6, U19.16, U20.14
/D6: U3din1.12, U3dout1.8, U11.5, U19.17, U20.15
/D7: U3din1.11, U3dout1.9, U11.4, U19.18, U20.16
/DBUSIN_EN: U3din1.1, U3din1.19, U20.22
/DBUSOUT_EN: U3dout1.1, U3dout1.19, U20.21
/DI0: P4.95, U3dout1.18, U13.18
/DI1: P4.94, U3dout1.17, U13.16
/DI2: P4.41, U3dout1.16, U13.14
/DI3: P4.42, U3dout1.15, U13.12
/DI4: P4.91, U3dout1.14, U13.9
/DI5: P4.92, U3dout1.13, U13.7
/DI6: P4.93, U3dout1.12, U13.5
/DI7: P4.43, U3dout1.11, U13.3
/DO0: P4.36, U3din1.2
/DO1: P4.35, U3din1.3
/DO2: P4.88, U3din1.4
/DO3: P4.89, U3din1.5
/DO4: P4.38, U3din1.6
/DO5: P4.39, U3din1.7
/DO6: P4.40, U3din1.8
/DO7: P4.90, U3din1.9
/INT*: JP1.2, P4.73
/IOREQb: P4.69, U9.14
/IOREQbb: U9.6, U20.39
/M2_MCLR: P5.1, R4.2, SW2.1, U8.4
/M2_PGC: P5.5, U8.12
/M2_PGD: P5.4, U8.13
/MCP1_0: IC1.10, P13.2
/MCP1_1: IC1.11, P13.3
/MCP1_2: IC1.12, P13.4
/MCP1_3: IC1.13, P13.5
/MCP1_4: IC1.14, P13.6
/MCP1_5: IC1.15, P13.7
/MCP1_6: IC1.16, P13.8
/MCP1_7: IC1.17, P13.9
/MCP2_0: IC2.10, P14.2
/MCP2_1: IC2.11, P14.3
/MCP2_2: IC2.12, P14.4
/MCP2_3: IC2.13, P14.5
/MCP2_4: IC2.14, P14.6
/MCP2_5: IC2.15, P14.7
/MCP2_6: IC2.16, P14.8
/MCP2_7: IC2.17, P14.9
/MCP_AddrHi: MCP1.1, MCP1.2, MCP2.1, MCP2.2, R7.1
/MWRT: P4.68, U9.13
/MWRTb: U9.7, U20.40
/NDEF2: P4.65, U9.12
/NDEF2b: U9.8, U20.41
/PHI: P4.24, U10.14
/PHIb: U10.6, U20.4
/PROG_M25P80_CLK: P1.2, U12.11, U18.18
/PROG_M25P80_CS: P1.4, U12.15, U18.15
/PROG_M25P80_Din: P1.3, U12.13, U18.20
/PROG_M25P80_Dout: P1.5, R10.2, U12.3, U18.22
/Q1: R2.2, R18.2, U8.9, U12.19
/Q2: R19.2, R28.2, U8.8, U12.1
/RESET*: P4.75, U31.9
/RESET*b: IC1.6, IC2.6, U20.3, U22.15, U31.11
/SLAVE_CLR*: P4.54, U9.11
/SLAVE_CLR*vv: U9.9, U20.33
/SPI_CLK: IC1.1, IC2.1, P3.5, U20.57, U22.11
/SPI_CS_00: U20.25, U22.10
/SPI_CS_01: IC1.7, U20.26
/SPI_CS_02: IC2.7, U20.27
/SPI_CS_03: P3.2, U20.17
/SPI_Din: IC1.2, IC2.2, P3.3, U20.58, U22.12
/SPI_Dout: IC1.3, IC2.3, P3.1, U20.59, U22.13
/TMA0*: P4.55, U31.2
/TMA0_CPLD: U20.111, U31.18
/TMA1*: P4.56, U31.3
/TMA1_CPLD: U20.112, U31.17
/TMA2*: P4.57, U31.4
/TMA2_CPLD: U20.113, U31.16
/TMA3*: P4.14, U31.5
/TMA3_CPLD: U20.115, U31.15
/USB_VCC1: C7.1, Jx2.1, Ux1.3
/V3.3: C2.1, C4.1, C5.1, C22.1, C30.1, C32.1, IC1.18, IC2.18, P2.1, P3.6, P8.2, P9.2, P13.10, P14.10, P19.2, R3.2, R7.2, R8.1, R12.1, R17.1, U2.3, U2.4, U12.20, U14.8, U15.8, U16.8, U17.8, U22.14, U22.16, U23.8, U24.8, U25.8, U26.8
/V3.3_CLPD_INT: C26.1, C33.1, P8.1, U20.8, U20.42, U20.84, U20.141
/V3.3_CLPD_IO: C19.1, C34.1, C35.1, C36.1, C37.1, C38.1, C39.1, C40.1, P9.1, U20.1, U20.37, U20.55, U20.73, U20.109, U20.127
/V3.3b: C9.1, C13.2, C15.1, D8.1, U18.28, Ux1.2
/VI0: U11.18, U21.18
/VI0*: JPx1.1, P4.4, P12.2
/VI1: U11.19, U21.16
/VI1*: JPx2.1, P4.5, P12.4
/VI2: U11.20, U21.14
/VI2*: JPx3.1, P4.6, P12.6
/VI3: U11.21, U21.12
/VI3*: JPx4.1, P4.7, P12.8
/VI4: U11.22, U21.9
/VI4*: JPx5.1, P4.8, P12.10
/VI5: U11.23, U21.7
/VI5*: JPx6.1, P4.9, P12.12
/VI6: U11.24, U21.5
/VI6*: JPx7.1, P4.10, P12.14
/VI7: U11.25, U21.3
/VI7*: JPx8.1, P4.11, P12.16
/Vbat: BAT1.1, U22.2
/Z80intVectorBusout: U13.1, U13.19, U20.44
/in8259CS*: U7.19, U20.69
/out8259CS*: U20.70, U31.6
/out8259CS*bufferedViaU31: U11.1, U31.14
/pDBIN: P4.78, U10.16
/pDBIN*b: U11.3, U30.6
/pDBINb: U10.4, U20.7, U30.5
/pWR*: P4.77, U10.17
/pWR*b: U10.3, U11.2, U20.56
/sINP: P4.46, U9.16
/sINPb: U9.4, U20.35
/sINTA: P4.96, U10.12
/sINTA*b: U11.26, U30.2
/sINTAb: U10.8, U20.20, U30.1
/sM1: P4.44, U9.18
/sMEMR: P4.47, U9.15
/sMEMRb: U9.5, U20.38
/sOUT: P4.45, U9.17
/sOUTb: U9.3, U20.34
/sWO*: P4.97, U10.15
/sWO*b: U10.5, U20.6
/sXTRQ*: P4.58, U31.7
/sXTRQ*b: U20.23, U31.13
GND: BAT1.2, C1.2, C2.2, C3.2, C4.2, C5.2, C6.2, C7.2, C8.2, C9.2, C10.2, C11.2, C12.2, C14.1, C15.2, C16.2, C17.2, C18.2, C19.2, C20.2, C21.2, C22.2, C23.2, C24.2, C25.2, C26.2, C27.2, C28.2, C29.2, C30.2, C31.2, C32.2, C33.2, C34.2, C35.2, C36.2, C37.2, C38.2, C39.2, C40.2, C41.2, C42.2, C43.2, IC1.9, IC2.9, Jx2.4, MCP1.5, MCP1.6, MCP2.5, MCP2.6, P1.1, P2.3, P2.4, P3.4, P3.7, P4.50, P4.100, P5.3, P6.1, P7.1, P11.5, P13.1, P14.1, P19.1, P19.3, P19.5, P19.7, P19.9, Q1.2, Q2.2, R5.2, R9.1, R10.1, R14.2, R15.1, R20.1, R21.1, S1.3, S1.5, S1.8, S2.3, S2.5, S2.8, SW1.1, SW2.2, SW3.1, SW3.2, SW3.3, SW3.4, SW3.5, SW3.6, SW3.7, SW3.8, SW5.1, SW5.2, SW5.3, SW5.4, SW5.5, SW5.6, SW5.7, SW5.8, SW6.1, SW6.2, SW6.3, SW6.4, SW6.5, SW6.6, SW6.7, SW6.8, SW50.1, U1.2, U2.2, U3.10, U3din1.10, U3dout1.10, U4.1, U4.10, U4.19, U5.1, U5.10, U5.19, U6.1, U6.10, U6.19, U7.10, U8.5, U9.1, U9.10, U9.19, U10.1, U10.10, U10.19, U11.14, U12.10, U13.10, U14.4, U15.4, U16.4, U17.4, U18.12, U18.27, U19.10, U20.18, U20.29, U20.36, U20.47, U20.62, U20.72, U20.89, U20.90, U20.99, U20.108, U20.114, U20.123, U20.144, U21.1, U21.10, U21.19, U22.1, U22.8, U22.9, U23.4, U24.4, U25.4, U26.4, U27.8, U28.8, U30.7, U31.1, U31.10, U31.19, Ux1.1
unnamed: P12.7, U21.8
unnamed: P12.9, U21.11
unnamed: P12.11, U21.13
unnamed: P12.13, U21.15
unnamed: P12.15, U21.17
unnamed: P12.5, U21.6
unnamed: P12.1, U21.2
unnamed: P12.3, U21.4
unnamed: RR1.5, SW6.13, U13.11
unnamed: RR1.4, SW6.14, U13.13
unnamed: RR1.3, SW6.15, U13.15
unnamed: P11.3, U3.19
unnamed: RR1.7, SW6.11, U13.6
unnamed: RR1.8, SW6.10, U13.4
unnamed: RR1.6, SW6.12, U13.8
unnamed: RR1.2, SW6.16, U13.17
unnamed: RR1.9, SW6.9, U13.2
unnamed: SW3.11, U3.14
unnamed: SW3.12, U3.12
unnamed: SW3.13, U3.9
unnamed: SW3.14, U3.7
unnamed: SW3.15, U3.5
unnamed: SW3.16, U3.3
unnamed: SW3.10, U3.16
unnamed: SW3.9, U3.18
unnamed: JP1.1, U30.4
unnamed: IC2.4, MCP2.4
unnamed: IC1.5, MCP1.3
unnamed: IC1.4, MCP1.4
unnamed: IC2.5, MCP2.3
unnamed: SW5.9, U7.18
unnamed: SW5.10, U7.16
unnamed: SW5.11, U7.14
unnamed: SW5.12, U7.12
unnamed: SW5.13, U7.9
unnamed: SW5.14, U7.7
unnamed: SW5.15, U7.5
unnamed: SW5.16, U7.3
unnamed: U22.3, X2.1
unnamed: U22.4, X2.2
unnamed: P11.2, P11.4, P11.6, U7.2
unnamed: D1.2, Q1.3
unnamed: D9.2, R21.2
unnamed: D4.2, Q2.3
unnamed: Jx2.3, U18.10
unnamed: C10.1, U18.13, X1.1
unnamed: C18.1, U18.14, X1.2
unnamed: Jx2.2, U18.11
unnamed: R15.2, U18.1
unnamed: D8.2, R14.1
unnamed: R8.2, SW1.2, U20.24
unnamed: R36.1, S1.9
unnamed: R31.1, S1.7
unnamed: R32.1, S1.6
unnamed: R33.1, S1.4
unnamed: R34.1, S1.2
unnamed: R35.1, S1.1
unnamed: R37.1, S1.10
unnamed: R38.1, S2.7
unnamed: R39.1, S2.6
unnamed: R40.1, S2.4
unnamed: R41.1, S2.2
unnamed: R42.1, S2.1
unnamed: R43.1, S2.9
unnamed: R44.1, S2.10
unnamed: R42.2, U28.9
unnamed: R37.2, U27.14
unnamed: R31.2, U27.13
unnamed: R32.2, U27.12
unnamed: R33.2, U27.11
unnamed: R34.2, U27.10
unnamed: R35.2, U27.9
unnamed: R36.2, U27.15
unnamed: R38.2, U28.13
unnamed: R39.2, U28.12
unnamed: R40.2, U28.11
unnamed: R41.2, U28.10
unnamed: R43.2, U28.15
unnamed: R44.2, U28.14
unnamed: D7.2, R20.2
unnamed: C14.2, U18.9
unnamed: C13.1, U18.2
unnamed: P11.1, R11.2
unnamed: U11.17, U30.3
unnamed: R6.1, U11.16
unnamed: D1.1, R1.1
unnamed: R3.1, U14.3, U14.7, U15.3, U15.7, U16.3, U16.7, U17.3, U17.7, U23.3, U23.7, U24.3, U24.7, U25.3, U25.7, U26.3, U26.7
unnamed: D4.1, R29.1
unnamed: P19.10, R26.2
unnamed: P19.6, R25.2
unnamed: P19.4, R27.2
unnamed: D5.2, R5.1
unnamed: R30.2, SW50.2, U8.17
unnamed: R17.2, U12.9, U12.18, U14.6, U15.6, U16.6, U17.6, U23.6, U24.6, U25.6, U26.6
unnamed: Q1.1, R2.1, R19.1
unnamed: Q2.1, R18.1, R28.1
unnamed: R12.2, U12.7, U12.16, U14.5, U15.5, U16.5, U17.5, U23.5, U24.5, U25.5, U26.5
unnamed: U12.8, U12.17, U14.2, U15.2, U16.2, U17.2, U23.2, U24.2, U25.2, U26.2
VCC: C3.1, C6.1, C8.1, C12.1, C16.1, C17.1, C20.1, C21.1, C23.1, C24.1, C25.1, C27.1, C28.1, C29.1, C31.1, C41.1, C42.1, C43.1, D5.1, P2.2, P3.8, P5.2, R1.2, R4.1, R6.2, R11.1, R29.2, R30.1, RR1.1, U1.3, U3.20, U3din1.20, U3dout1.20, U4.20, U5.20, U6.20, U7.20, U8.14, U9.20, U10.20, U11.28, U13.20, U19.20, U21.20, U27.3, U27.4, U27.5, U27.16, U28.3, U28.4, U28.5, U28.16, U30.14, U31.20

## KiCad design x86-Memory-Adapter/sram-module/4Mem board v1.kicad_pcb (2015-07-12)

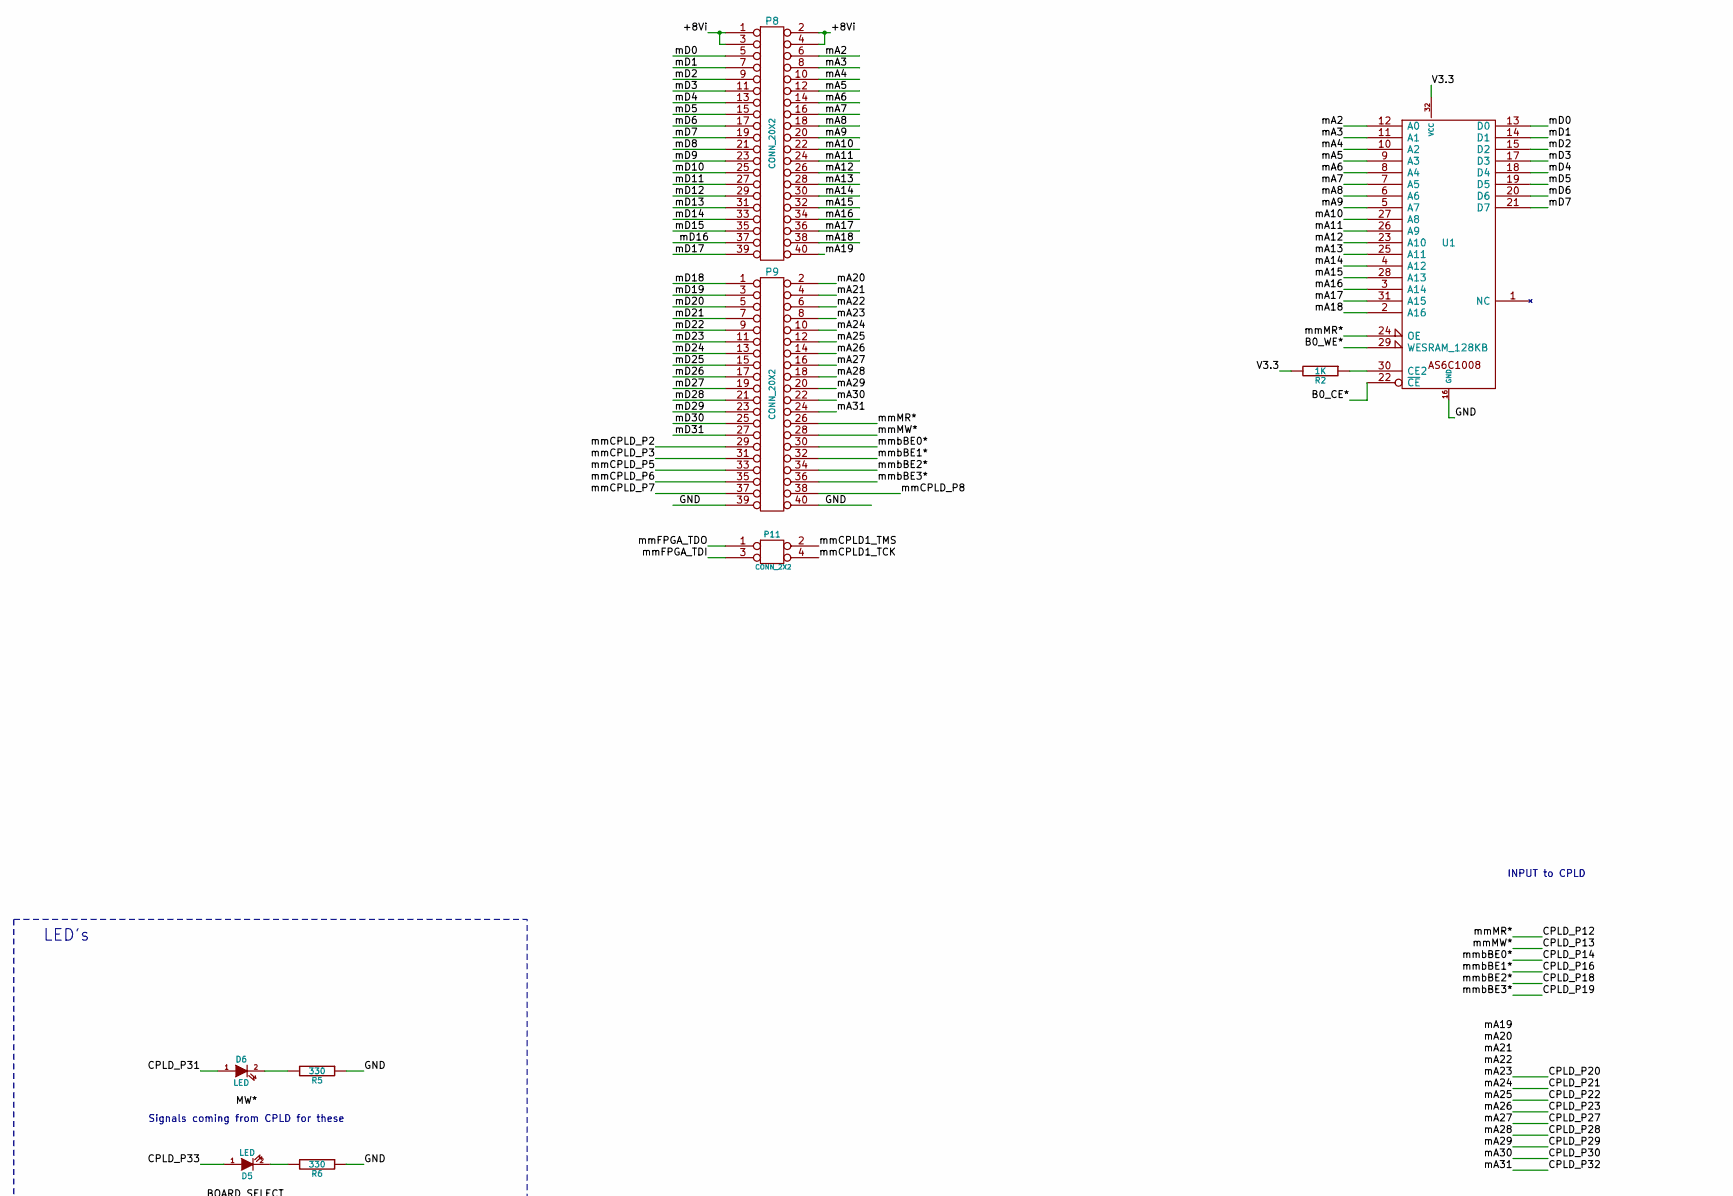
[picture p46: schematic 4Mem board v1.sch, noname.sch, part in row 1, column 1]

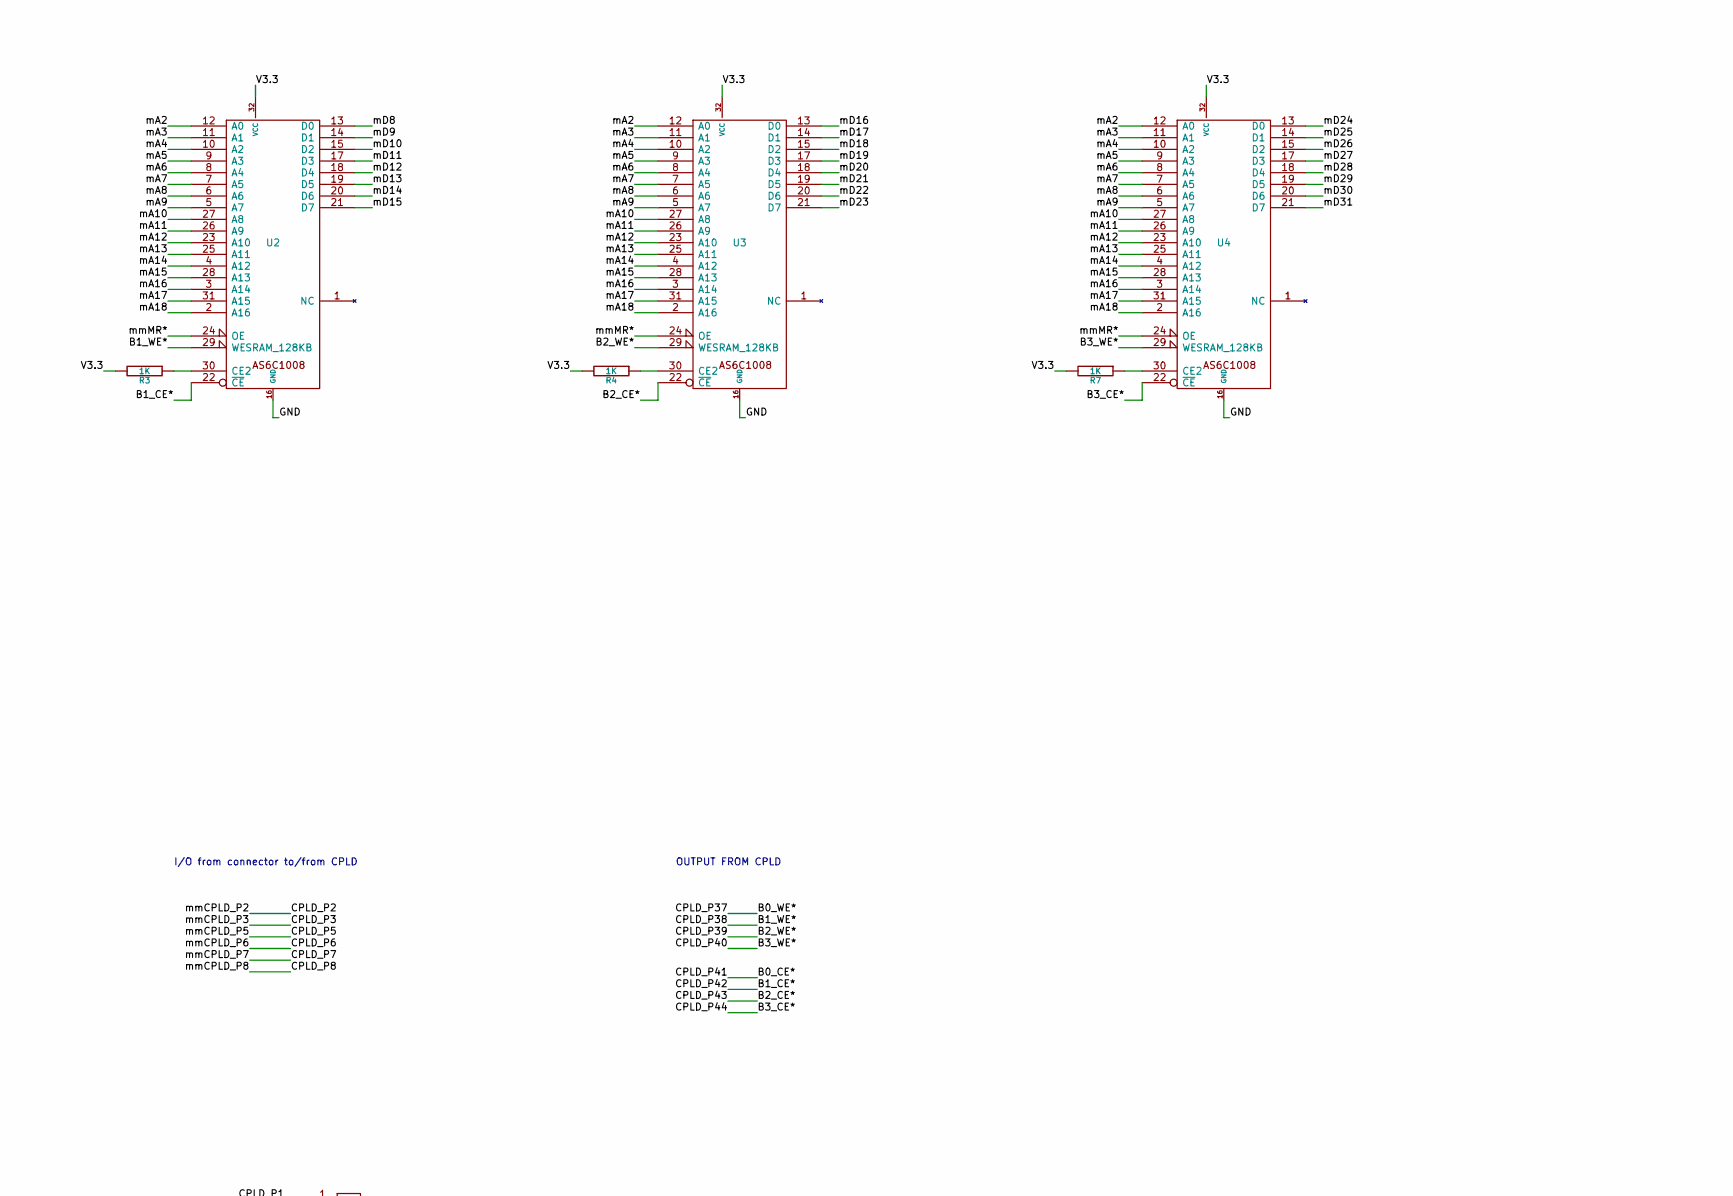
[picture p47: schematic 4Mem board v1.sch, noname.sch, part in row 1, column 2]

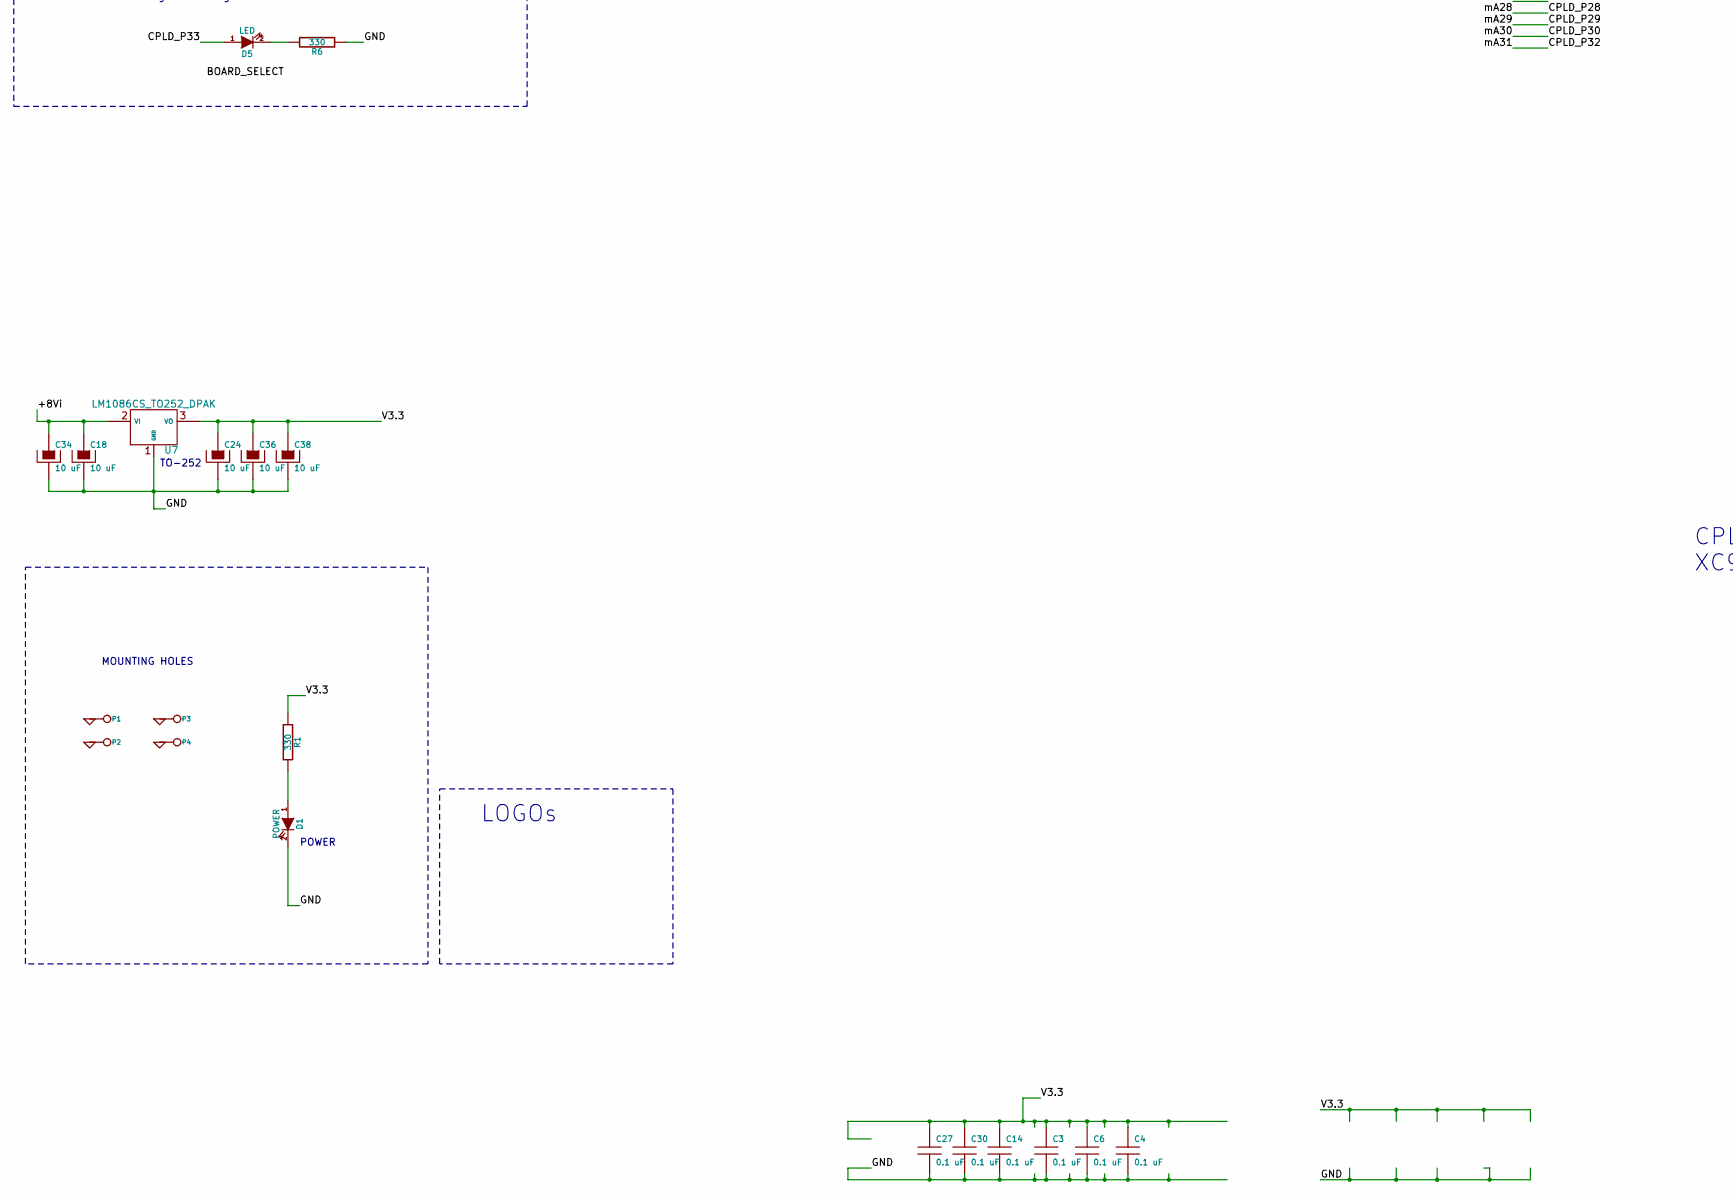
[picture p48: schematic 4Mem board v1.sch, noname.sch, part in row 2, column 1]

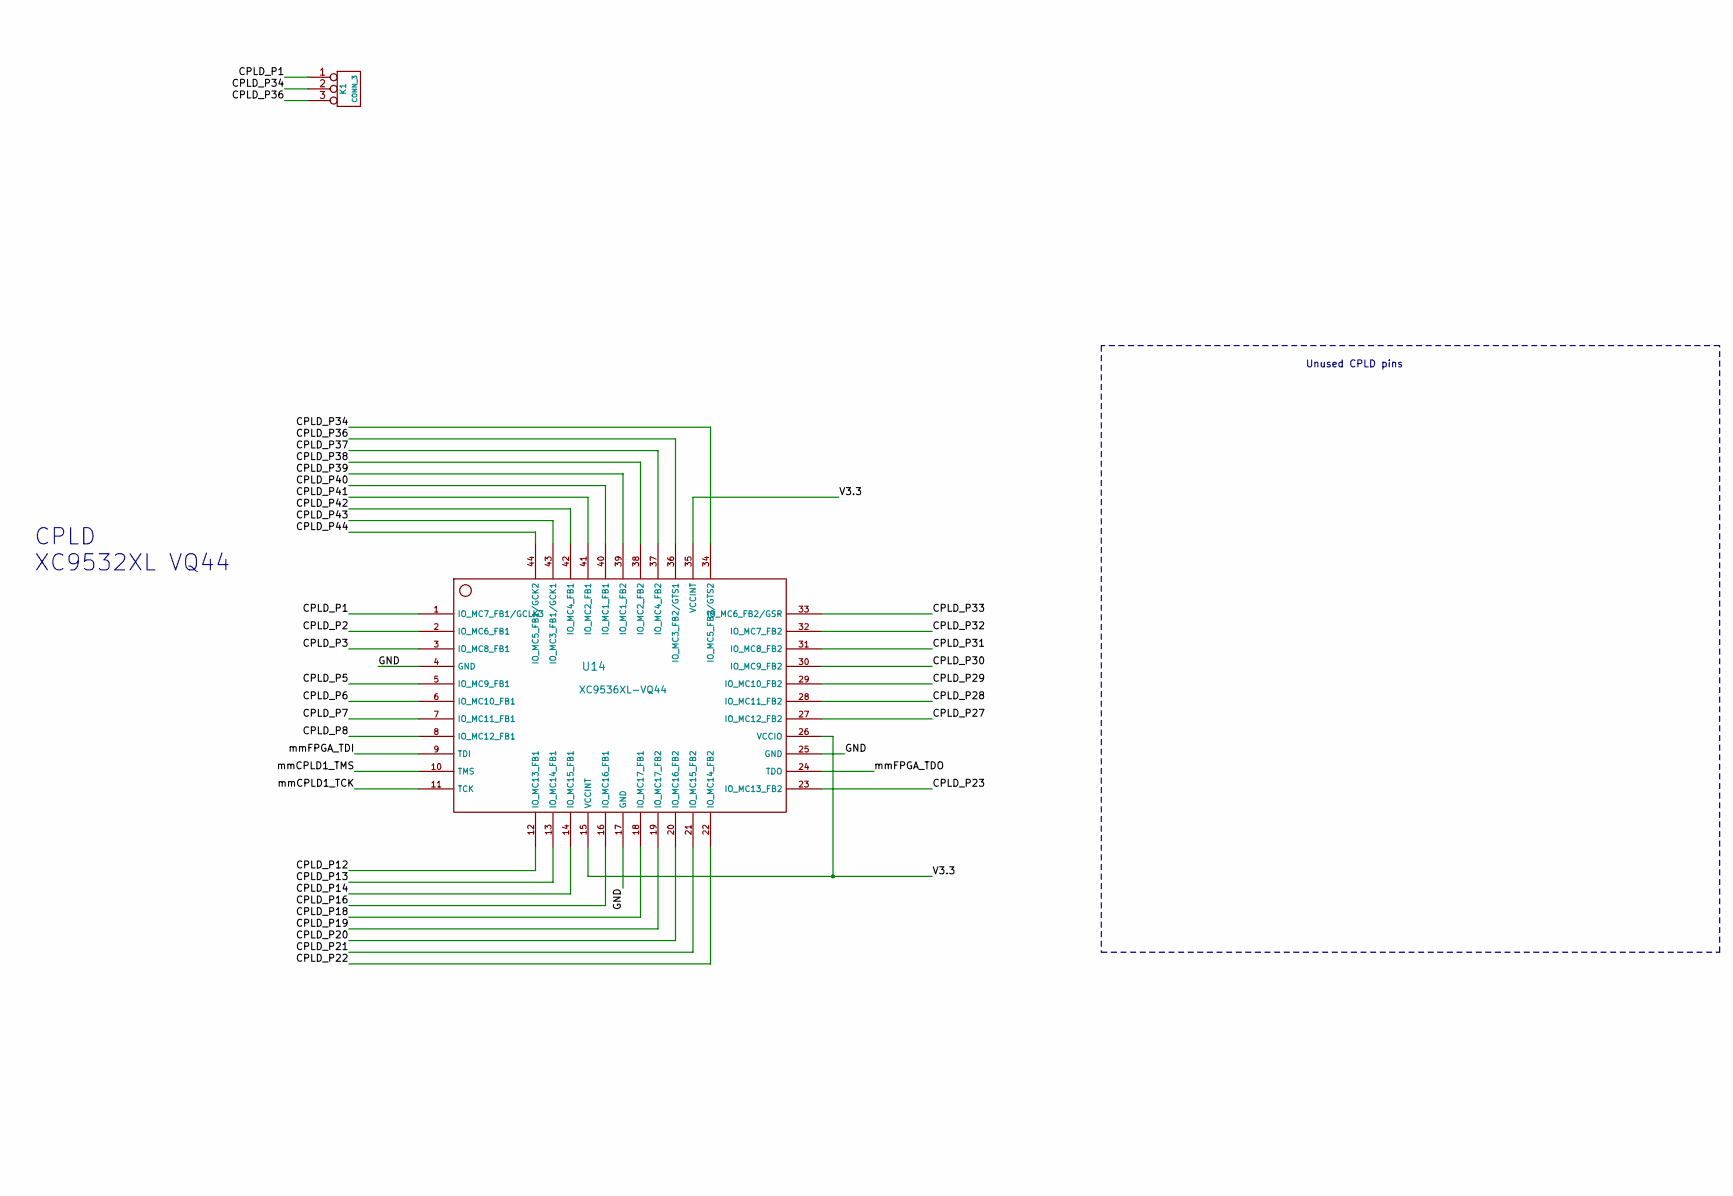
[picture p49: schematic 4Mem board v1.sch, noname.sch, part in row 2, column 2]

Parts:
C3, C4, C6, C14: 0.1 uF; C2
C18, C24, C34, C36, C38: 10 uF
C27, C30: 0.1 uF
D1: POWER
D5, D6: LED; LEDV
K1: CONN_3
P1, P2, P3, P4: CONN_1
P8, P9: CONN_20X2; 8MB_SRAM
P11: CONN_2X2
R1, R5, R6: 330
R2, R3, R4, R7: 1K
U1, U2, U3, U4: SRAM_128KB
U7: LM1086CS_TO252_DPAK
U14: XC9536XL-VQ44

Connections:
/+8Vi: C18.1, C34.1, P8.1, P8.2, P8.3, P8.4, U7.2 (VI)
/B0_CE*: U1.22 (~CE), U14.41 (IO_MC2_FB1)
/B0_WE*: U1.29 (WE), U14.37 (IO_MC4_FB2)
/B1_CE*: U2.22 (~CE), U14.42 (IO_MC4_FB1)
/B1_WE*: U2.29 (WE), U14.38 (IO_MC2_FB2)
/B2_CE*: U3.22 (~CE), U14.43 (IO_MC3_FB1/GCK1)
/B2_WE*: U3.29 (WE), U14.39 (IO_MC1_FB2)
/B3_CE*: U4.22 (~CE), U14.44 (IO_MC5_FB1/GCK2)
/B3_WE*: U4.29 (WE), U14.40 (IO_MC1_FB1)
/CPLD_P1: K1.1, U14.1 (IO_MC7_FB1/GCLK3)
/CPLD_P2: P9.29, U14.2 (IO_MC6_FB1)
/CPLD_P3: P9.31, U14.3 (IO_MC8_FB1)
/CPLD_P5: P9.33, U14.5 (IO_MC9_FB1)
/CPLD_P6: P9.35, U14.6 (IO_MC10_FB1)
/CPLD_P7: P9.37, U14.7 (IO_MC11_FB1)
/CPLD_P8: P9.38, U14.8 (IO_MC12_FB1)
/CPLD_P12: P9.26, U1.24 (OE), U2.24 (OE), U3.24 (OE), U4.24 (OE), U14.12 (IO_MC13_FB1)
/CPLD_P13: P9.28, U14.13 (IO_MC14_FB1)
/CPLD_P14: P9.30, U14.14 (IO_MC15_FB1)
/CPLD_P16: P9.32, U14.16 (IO_MC16_FB1)
/CPLD_P18: P9.34, U14.18 (IO_MC17_FB1)
/CPLD_P19: P9.36, U14.19 (IO_MC17_FB2)
/CPLD_P20: P9.8, U14.20 (IO_MC16_FB2)
/CPLD_P21: P9.10, U14.21 (IO_MC15_FB2)
/CPLD_P22: P9.12, U14.22 (IO_MC14_FB2)
/CPLD_P23: P9.14, U14.23 (IO_MC13_FB2)
/CPLD_P27: P9.16, U14.27 (IO_MC12_FB2)
/CPLD_P28: P9.18, U14.28 (IO_MC11_FB2)
/CPLD_P29: P9.20, U14.29 (IO_MC10_FB2)
/CPLD_P30: P9.22, U14.30 (IO_MC9_FB2)
/CPLD_P31: D6.1 (A), U14.31 (IO_MC8_FB2)
/CPLD_P32: P9.24, U14.32 (IO_MC7_FB2)
/CPLD_P33: D5.1 (A), U14.33 (IO_MC6_FB2/GSR)
/CPLD_P34: K1.2 (PM), U14.34 (IO_MC5_FB2/GTS2)
/CPLD_P36: K1.3, U14.36 (IO_MC3_FB2/GTS1)
/V3.3: C3.1, C4.1, C6.1, C14.1, C24.1, C27.1, C30.1, C36.1, C38.1, R1.1, R2.2, R3.2, R4.2, R7.2, U1.32 (VCC), U2.32 (VCC), U3.32 (VCC), U4.32 (VCC), U7.3 (VO), U14.15 (VCCINT), U14.26 (VCCIO), U14.35 (VCCINT)
/mA2: P8.6, U1.12 (A0), U2.12 (A0), U3.12 (A0), U4.12 (A0)
/mA3: P8.8, U1.11 (A1), U2.11 (A1), U3.11 (A1), U4.11 (A1)
/mA4: P8.10, U1.10 (A2), U2.10 (A2), U3.10 (A2), U4.10 (A2)
/mA5: P8.12, U1.9 (A3), U2.9 (A3), U3.9 (A3), U4.9 (A3)
/mA6: P8.14, U1.8 (A4), U2.8 (A4), U3.8 (A4), U4.8 (A4)
/mA7: P8.16, U1.7 (A5), U2.7 (A5), U3.7 (A5), U4.7 (A5)
/mA8: P8.18, U1.6 (A6), U2.6 (A6), U3.6 (A6), U4.6 (A6)
/mA9: P8.20, U1.5 (A7), U2.5 (A7), U3.5 (A7), U4.5 (A7)
/mA10: P8.22, U1.27 (A8), U2.27 (A8), U3.27 (A8), U4.27 (A8)
/mA11: P8.24, U1.26 (A9), U2.26 (A9), U3.26 (A9), U4.26 (A9)
/mA12: P8.26, U1.23 (A10), U2.23 (A10), U3.23 (A10), U4.23 (A10)
/mA13: P8.28, U1.25 (A11), U2.25 (A11), U3.25 (A11), U4.25 (A11)
/mA14: P8.30, U1.4 (A12), U2.4 (A12), U3.4 (A12), U4.4 (A12)
/mA15: P8.32, U1.28 (A13), U2.28 (A13), U3.28 (A13), U4.28 (A13)
/mA16: P8.34, U1.3 (A14), U2.3 (A14), U3.3 (A14), U4.3 (A14)
/mA17: P8.36, U1.31 (A15), U2.31 (A15), U3.31 (A15), U4.31 (A15)
/mA18: P8.38, U1.2 (A16), U2.2 (A16), U3.2 (A16), U4.2 (A16)
/mD0: P8.5, U1.13 (D0)
/mD1: P8.7, U1.14 (D1)
/mD2: P8.9, U1.15 (D2)
/mD3: P8.11, U1.17 (D3)
/mD4: P8.13, U1.18 (D4)
/mD5: P8.15, U1.19 (D5)
/mD6: P8.17, U1.20 (D6)
/mD7: P8.19, U1.21 (D7)
/mD8: P8.21, U2.13 (D0)
/mD9: P8.23, U2.14 (D1)
/mD10: P8.25, U2.15 (D2)
/mD11: P8.27, U2.17 (D3)
/mD12: P8.29, U2.18 (D4)
/mD13: P8.31, U2.19 (D5)
/mD14: P8.33, U2.20 (D6)
/mD15: P8.35, U2.21 (D7)
/mD16: P8.37, U3.13 (D0)
/mD17: P8.39, U3.14 (D1)
/mD18: P9.1, U3.15 (D2)
/mD19: P9.3, U3.17 (D3)
/mD20: P9.5, U3.18 (D4)
/mD21: P9.7, U3.19 (D5)
/mD22: P9.9, U3.20 (D6)
/mD23: P9.11, U3.21 (D7)
/mD24: P9.13, U4.13 (D0)
/mD25: P9.15, U4.14 (D1)
/mD26: P9.17, U4.15 (D2)
/mD27: P9.19, U4.17 (D3)
/mD28: P9.21, U4.18 (D4)
/mD29: P9.23, U4.19 (D5)
/mD30: P9.25, U4.20 (D6)
/mD31: P9.27, U4.21 (D7)
/mmCPLD1_TCK: P11.4, U14.11 (TCK)
/mmCPLD1_TMS: P11.2, U14.10 (TMS)
/mmFPGA_TDI: P11.3, U14.9 (TDI)
/mmFPGA_TDO: P11.1, U14.24 (TDO)
GND: C3.2, C4.2, C6.2, C14.2, C18.2, C24.2, C27.2, C30.2, C34.2, C36.2, C38.2, D1.2 (K), P1.1, P2.1, P3.1, P4.1, P9.39, P9.40, R5.1, R6.1, U1.16 (GND), U2.16 (GND), U3.16 (GND), U4.16 (GND), U7.1 (GND), U14.4 (GND), U14.17 (GND), U14.25 (GND)
unnamed: R3.1, U2.30 (CE2)
unnamed: R2.1, U1.30 (CE2)
unnamed: R4.1, U3.30 (CE2)
unnamed: R7.1, U4.30 (CE2)
unnamed: D5.2 (K), R6.2
unnamed: D6.2 (K), R5.2
unnamed: D1.1 (A), R1.2

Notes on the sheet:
CPLD XC9532XL VQ44
POWER
TO-252
MOUNTING HOLES
LOGOs
OUTPUT FROM CPLD
INPUT to CPLD
Unused CPLD pins
LED's
Signals coming from CPLD for these
I/O from connector to/from CPLD

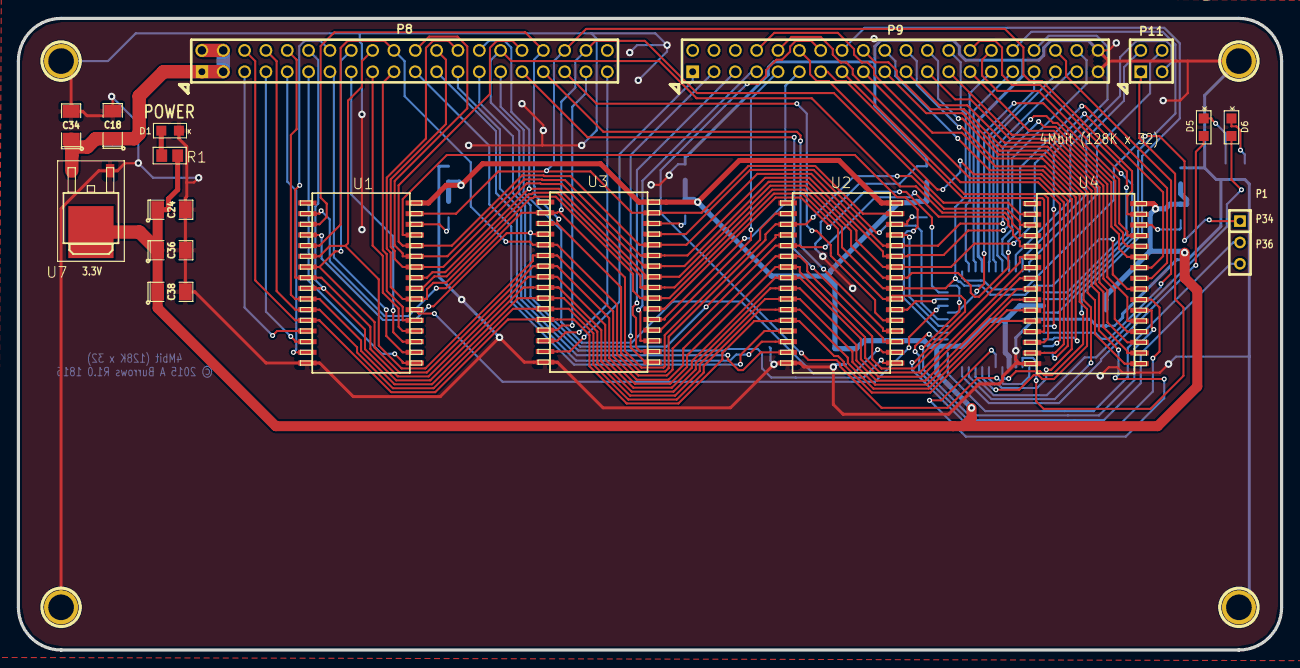
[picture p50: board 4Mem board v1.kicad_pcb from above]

Board: 2 copper layers, 150.4 x 75.2 mm, 35 parts (0 on the bottom side), 97 nets.

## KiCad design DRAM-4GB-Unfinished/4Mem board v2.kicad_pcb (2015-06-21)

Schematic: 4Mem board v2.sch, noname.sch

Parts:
C1, C4, C6, C14, C22, C23, C25, C26, C28, C29, C30, C31, C32, C33, C35, C37, C39, C40, C41, C42, C43, C45: 0.1 uF; C2
C2, C27: 0.1 uF
C3, C5, C7, C8, C9, C10, C11, C12, C13, C15, C16, C17, C18, C19, C20, C21, C24, C34, C36, C38, C44, C46, C47, C48: 10 uF
D1: POWER
D2: LED
D5, D6: LED; LEDV
P1, P2, P3, P4: CONN_1
P5: CONN_6X2
P8, P9: CONN_20X2; 8MB_SRAM
P11: CONN_2X2
Q1: ^^NPN-BC817-SOT323
R1, R2, R5, R6, R11: 330
R3, R4, R7, R9, R10: 4K7
R8: 0
R12, R13: 10K
SW1: PROG_B
U1: XC6SLX45-2FGG484C
U2: DDR3_DIMM_240PIN
U3: XCF08P-VO48/TSOP48
U4: LM1117MP-1.8
U5: AZ1084
U6: NCP565
U7: LT1764EQ-1.5
U8: RT9026_MSOP-10
U9: FPGA_CLK_0; Digikey CTX285LVCT-ND
U10: LM1117MP-2.5
U12: PIC18F2520-28QFN

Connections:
/+8Vi: C5.1, C7.1, C9.1, C10.1, C18.1, C34.1, P8.1, P8.2, P8.3, P8.4, U5.3 (VI), U6.1 (VI), U7.1 (~SHDN), U7.2 (VI)
/+8Vitemp: C3.1, C8.1, C44.1, U4.3 (VI), U10.3 (VI)
/DDR3_A0: U1.G19 (IO_L33P_A15_M1A10_1), U2.188 (A0)
/DDR3_A1: U1.A21 (IO_L20N_1), U2.181 (A1)
/DDR3_A2: U1.A20 (IO_L20P_1), U2.61 (A2)
/DDR3_A3: U1.A2 (IO_L83P_3), U2.180 (A3)
/DDR3_A4: U1.H8 (IO_L59N_3), U2.59 (A4)
/DDR3_A5: U1.G6 (IO_L55P_M3A13_3), U2.58 (A5)
/DDR3_A6: U1.F5 (IO_L55N_M3A14_3), U2.178 (A6)
/DDR3_A7: U1.G4 (IO_L51P_M3A10_3), U2.56 (A7)
/DDR3_A8: U1.H6 (IO_L49P_M3A7_3), U2.177 (A8)
/DDR3_A9: U1.J7 (IO_L59P_3), U2.175 (A9)
/DDR3_A10: U1.H19 (IO_L34P_A13_M1WE_1), U2.70 (A10/AP)
/DDR3_A11: U1.H5 (IO_L49N_M3A2_3), U2.55 (A11)
/DDR3_A12: U1.J6 (IO_L45N_M3ODT_3), U2.174 (A12/BC)
/DDR3_A13: U1.M20 (IO_L42P_GCLK7_M1UDM_1), U2.196 (A13)
/DDR3_A14: U1.K4 (IO_L43N_GCLK22_IRDY2_M3CASN_3), U2.172 (A14)
/DDR3_A15: U1.K3 (IO_L44P_GCLK21_M3A5_3), U2.171 (A15)
/DDR3_BA0: U1.J17 (IO_L36P_A9_M1BA0_1), U2.71 (BA0)
/DDR3_BA1: U1.H18 (IO_L34N_A12_M1BA2_1), U2.190 (BA1)
/DDR3_BA2: U1.J4 (IO_L44N_GCLK20_M3A6_3), U2.52 (BA2)
/DDR3_CAS: U1.K18 (IO_L61N_1), U2.74 (~CAS)
/DDR3_CK0h: U1.F18 (IO_L30P_A21_M1RESET_1), U2.184 (CK0)
/DDR3_CK0l: U1.F19 (IO_L30N_A20_M1A11_1), U2.185 (~CK0)
/DDR3_CK1h: U1.B21 (IO_L19P_1), U2.63 (CK1)
/DDR3_CK1l: U1.B22 (IO_L19N_1), U2.64 (~CK1)
/DDR3_CKE0: U1.K5 (IO_L43P_GCLK23_M3RASN_3), U2.50 (CKE0)
/DDR3_CKE1: U1.K6 (IO_L45P_M3A3_3), U2.169 (CKE1)
/DDR3_DM0: U1.V1 (IO_L32N_M3DQ15_3), U2.125 (DM0)
/DDR3_DM1: U1.P1 (IO_L36N_M3DQ9_3), U2.134 (DM1)
/DDR3_DM2: U1.J1 (IO_L41N_GCLK26_M3DQ5_3), U2.143 (DM2)
/DDR3_DM3: U1.E3 (IO_L52P_M3A8_3), U2.152 (DM3)
/DDR3_DM4: U1.D22 (IO_L31N_A18_M1A12_1), U2.203 (DM4)
/DDR3_DM5: U1.H22 (IO_L41N_GCLK8_M1CASN_1), U2.212 (DM5)
/DDR3_DM6: U1.M19 (IO_L53P_1), U2.221 (DM6)
/DDR3_DM7: U1.U22 (IO_L51N_M1DQ13_1), U2.230 (DM7)
/DDR3_DQ0: U1.W3 (IO_L2P_3), U2.3 (DQ0)
/DDR3_DQ1: U1.W1 (IO_L2N_3), U2.4 (DQ1)
/DDR3_DQ2: U1.U3 (IO_L33P_M3DQ12_3), U2.9 (DQ2)
/DDR3_DQ3: U1.T1 (IO_L34N_M3UDQSN_3), U2.10 (DQ3)
/DDR3_DQ4: U1.Y2 (IO_L1P_3), U2.122 (DQ4)
/DDR3_DQ5: U1.V2 (IO_L32P_M3DQ14_3), U2.123 (DQ5)
/DDR3_DQ6: U1.U1 (IO_L33N_M3DQ13_3), U2.128 (DQ6)
/DDR3_DQ7: U1.T2 (IO_L34P_M3UDQS_3), U2.129 (DQ7)
/DDR3_DQ8: U1.T4 (IO_L9P_3), U2.12 (DQ8)
/DDR3_DQ9: U1.R3 (IO_L35P_M3DQ10_3), U2.13 (DQ9)
/DDR3_DQ10: U1.M1 (IO_L38N_M3DQ3_3), U2.18 (DQ10)
/DDR3_DQ11: U1.L1 (IO_L39N_M3LDQSN_3), U2.19 (DQ11)
/DDR3_DQ12: U1.T3 (IO_L9N_3), U2.131 (DQ12)
/DDR3_DQ13: U1.R1 (IO_L35N_M3DQ11_3), U2.132 (DQ13)
/DDR3_DQ14: U1.M2 (IO_L38P_M3DQ2_3), U2.137 (DQ14)
/DDR3_DQ15: U1.L3 (IO_L39P_M3LDQS_3), U2.138 (DQ15)
/DDR3_DQ16: U1.K1 (IO_L40N_M3DQ7_3), U2.21 (DQ16)
/DDR3_DQ17: U1.K2 (IO_L40P_M3DQ6_3), U2.22 (DQ17)
/DDR3_DQ18: U1.H2 (IO_L47P_M3A0_3), U2.27 (DQ18)
/DDR3_DQ19: U1.G1 (IO_L48N_M3BA1_3), U2.28 (DQ19)
/DDR3_DQ20: U1.M5 (IO_L31P_3), U2.140 (DQ20)
/DDR3_DQ21: U1.J3 (IO_L41P_GCLK27_M3DQ4_3), U2.141 (DQ21)
/DDR3_DQ22: U1.H1 (IO_L47N_M3A1_3), U2.146 (DQ22)
/DDR3_DQ23: U1.G3 (IO_L48P_M3BA0_3), U2.147 (DQ23)
/DDR3_DQ24: U1.F1 (IO_L50N_M3BA2_3), U2.30 (DQ24)
/DDR3_DQ25: U1.E1 (IO_L52N_M3A9_3), U2.31 (DQ25)
/DDR3_DQ26: U1.C3 (IO_L54P_M3RESET_3), U2.36 (DQ26)
/DDR3_DQ27: U1.B2 (IO_L60P_3), U2.37 (DQ27)
/DDR3_DQ28: U1.F3 (IO_L51N_M3A4_3), U2.149 (DQ28)
/DDR3_DQ29: U1.F2 (IO_L50P_M3WE_3), U2.150 (DQ29)
/DDR3_DQ30: U1.C1 (IO_L54N_M3A11_3), U2.155 (DQ30)
/DDR3_DQ31: U1.B1 (IO_L60N_3), U2.156 (DQ31)
/DDR3_DQ32: U1.C22 (IO_L32N_A16_M1A9_1), U2.81 (DQ32)
/DDR3_DQ33: U1.C20 (IO_L32P_A17_M1A8_1), U2.82 (DQ33)
/DDR3_DQ34: U1.E20 (IO_L35P_A11_M1A7_1), U2.87 (DQ34)
/DDR3_DQ35: U1.F22 (IO_L37N_A6_M1A1_1), U2.88 (DQ35)
/DDR3_DQ36: U1.C19 (IO_L1P_A25_1), U2.200 (DQ36)
/DDR3_DQ37: U1.D21 (IO_L31P_A19_M1CKE_1), U2.201 (DQ37)
/DDR3_DQ38: U1.E22 (IO_L35N_A10_M1A2_1), U2.206 (DQ38)
/DDR3_DQ39: U1.F21 (IO_L37P_A7_M1A0_1), U2.207 (DQ39)
/DDR3_DQ40: U1.G22 (IO_L39N_M1ODT_1), U2.90 (DQ40)
/DDR3_DQ41: U1.H21 (IO_L41P_GCLK9_IRDY1_M1RASN_1), U2.91 (DQ41)
/DDR3_DQ42: U1.J20 (IO_L43P_GCLK5_M1DQ4_1), U2.96 (DQ42)
/DDR3_DQ43: U1.K21 (IO_L44P_A3_M1DQ6_1), U2.97 (DQ43)
/DDR3_DQ44: U1.F20 (IO_L33N_A14_M1A4_1), U2.209 (DQ44)
/DDR3_DQ45: U1.G20 (IO_L39P_M1A3_1), U2.210 (DQ45)
/DDR3_DQ46: U1.J22 (IO_L43N_GCLK4_M1DQ5_1), U2.215 (DQ46)
/DDR3_DQ47: U1.K22 (IO_L44N_A2_M1DQ7_1), U2.216 (DQ47)
/DDR3_DQ48: U1.L20 (IO_L45P_A1_M1LDQS_1), U2.99 (DQ48)
/DDR3_DQ49: U1.M21 (IO_L46P_FCS_B_M1DQ2_1), U2.100 (DQ49)
/DDR3_DQ50: U1.P21 (IO_L48P_HDC_M1DQ8_1), U2.105 (DQ50)
/DDR3_DQ51: U1.R22 (IO_L49N_M1DQ11_1), U2.106 (DQ51)
/DDR3_DQ52: U1.L22 (IO_L45N_A0_M1LDQSN_1), U2.218 (DQ52)
/DDR3_DQ53: U1.M22 (IO_L46N_FOE_B_M1DQ3_1), U2.219 (DQ53)
/DDR3_DQ54: U1.P22 (IO_L48N_M1DQ9_1), U2.224 (DQ54)
/DDR3_DQ55: U1.R20 (IO_L49P_M1DQ10_1), U2.225 (DQ55)
/DDR3_DQ56: U1.T22 (IO_L50N_M1UDQSN_1), U2.108 (DQ56)
/DDR3_DQ57: U1.U20 (IO_L51P_M1DQ12_1), U2.109 (DQ57)
/DDR3_DQ58: U1.V21 (IO_L52P_M1DQ14_1), U2.114 (DQ58)
/DDR3_DQ59: U1.W22 (IO_L60N_1), U2.115 (DQ59)
/DDR3_DQ60: U1.P19 (IO_L59P_1), U2.227 (DQ60)
/DDR3_DQ61: U1.T21 (IO_L50P_M1UDQS_1), U2.228 (DQ61)
/DDR3_DQ62: U1.V22 (IO_L52N_M1DQ15_1), U2.233 (DQ62)
/DDR3_DQ63: U1.W20 (IO_L60P_1), U2.234 (DQ63)
/DDR3_DQS0h: U1.U4 (IO_L10P_3), U2.7 (DQS0)
/DDR3_DQS0l: U1.V3 (IO_L10N_3), U2.6 (~DQS0)
/DDR3_DQS1h: U1.N1 (IO_L37N_M3DQ1_3), U2.16 (DQS1)
/DDR3_DQS1l: U1.N3 (IO_L37P_M3DQ0_3), U2.15 (~DSQ1)
/DDR3_DQS2h: U1.H3 (IO_L46N_M3CLKN_3), U2.25 (DQS2)
/DDR3_DQS2l: U1.H4 (IO_L46P_M3CLK_3), U2.24 (~DQS2)
/DDR3_DQS3h: U1.D2 (IO_L53P_M3CKE_3), U2.34 (DQS3)
/DDR3_DQS3l: U1.D1 (IO_L53N_M3A12_3), U2.33 (~DQS3)
/DDR3_DQS4h: U1.D19 (IO_L29P_A23_M1A13_1), U2.85 (DQS4)
/DDR3_DQS4l: U1.D20 (IO_L29N_A22_M1A14_1), U2.84 (~DQS4)
/DDR3_DQS5h: U1.J19 (IO_L38N_A4_M1CLKN_1), U2.94 (DQS5)
/DDR3_DQS5l: U1.H20 (IO_L38P_A5_M1CLK_1), U2.93 (~DQS5)
/DDR3_DQS6h: U1.N20 (IO_L47P_FWE_B_M1DQ0_1), U2.103 (DQS6)
/DDR3_DQS6l: U1.N22 (IO_L47N_LDC_M1DQ1_1), U2.102 (~DQS6)
/DDR3_DQS7h: U1.T19 (IO_L74P_AWAKE_1), U2.112 (DQS7)
/DDR3_DQS7l: U1.T20 (IO_L74N_DOUT_BUSY_1), U2.111 (~DQS7)
/DDR3_ODT0: U1.L19 (IO_L42N_GCLK6_TRDY1_M1LDM_1), U2.195 (~DQS0)
/DDR3_OFT1: U1.P20 (IO_L59N_1), U2.77 (OFT1)
/DDR3_RAS: U1.K17 (IO_L36N_A8_M1BA1_1), U2.192 (~RAS)
/DDR3_S0l: U1.K19 (IO_L40N_GCLK10_M1A6_1), U2.193 (~SO)
/DDR3_S1l: U1.L17 (IO_L61P_1), U2.76 (~S1)
/DDR3_SCL: R12.1, U2.118 (SCL), U12.11 (SCK/SCL/RC3)
/DDR3_SDA: R13.1, U2.238 (SDA), U12.12 (SDI/SDA/RC4)
/DDR3_VREF: C23.1, C26.1, C29.1, C31.1, U2.1 (VREF), U2.67 (VREF), U8.6 (VTTREF)
/DDR3_VTT: C22.1, C25.1, C28.1, C30.1, U2.120 (VTT), U2.240 (VTT), U8.3 (VTT), U8.5 (VTTSNS)
/DDR3_WE: U1.K20 (IO_L40P_GCLK11_M1A5_1), U2.73 (~WE)
/DONE_LED_SIGNAL: Q1.1 (B), R8.1, U2.168 (~RESET)
/FPGA_CCLK_2: R3.2, R4.1, U1.Y21 (IO_L1P_CCLK_2), U3.12 (CLK)
/FPGA_CLK_0: U1.M3 (IO_L42P_GCLK25_TRDY2_M3UDM_3), U9.3 (OUT)
/FPGA_DONE: R8.2, R11.2, U1.Y22 (DONE_2), U3.13 (CE)
/FPGA_INIT_B: R7.2, U1.T6 (IO_L65P_INIT_B_2), U3.11 (OE/RST)
/FPGA_PROGRAM_B: R10.2, SW1.2, U1.AA1 (PROGRAM_B_2)
/FPGA_TDI: P11.3, U1.E18 (TDI)
/FPGA_TDO: U1.A19 (TDO), U3.19 (TDI)
/IO_000: P8.13, U1.B14 (IO_L50P_0)
/IO_001: P8.15, U1.A14 (IO_L50N_0)
/IO_002: P8.17, U1.A17 (IO_L64N_SCP4_0)
/IO_003: P8.19, U1.B18 (IO_L65P_SCP3_0)
/IO_004: P8.21, U1.A16 (IO_L63N_SCP6_0)
/IO_005: P8.23, U1.C17 (IO_L64P_SCP5_0)
/IO_006: P8.25, U1.C16 (IO_L62N_VREF_0)
/IO_007: P8.27, U1.B16 (IO_L63P_SCP7_0)
/IO_008: P8.29, U1.B6 (IO_L4P_0)
/IO_009: P8.31, U1.A6 (IO_L4N_0)
/IO_010: P8.33, U1.C7 (IO_L5P_0)
/IO_011: P8.35, U1.A7 (IO_L5N_0)
/IO_012: P8.37, U1.B8 (IO_L6P_0)
/IO_013: P8.39, U1.A8 (IO_L6N_0)
/IO_014: P9.1, U1.B10 (IO_L34P_GCLK19_0)
/IO_015: P9.3, U1.A10 (IO_L34N_GCLK18_0)
/IO_016: P9.5, U1.AB9 (IO_L43N_2)
/IO_017: P9.7, U1.Y9 (IO_L43P_2)
/IO_018: P9.9, U1.Y10 (IO_L44N_2)
/IO_019: P9.11, U1.W10 (IO_L44P_2)
/IO_020: P9.13, U1.Y16 (IO_L17P_2)
/IO_021: P9.15, U1.W15 (IO_L17N_2)
/IO_022: P9.17, U1.B12 (IO_L37P_GCLK13_0)
/IO_023: P9.19, U1.A12 (IO_L37N_GCLK12_0)
/IO_024: P9.21, U1.C13 (IO_L38P_0)
/IO_025: P9.23, U1.A13 (IO_L38N_VREF_0)
/IO_026: P9.25, U1.D14 (IO_L49P_0)
/IO_027: P9.27, U1.C14 (IO_L49N_0)
/IO_028: P9.29, U1.U16 (IO_L8N_2)
/IO_029: P9.31, U1.U17 (IO_L8P_2)
/IO_030: P9.33, U1.W8 (IO_L46P_2)
/IO_031: P9.35, U1.Y8 (IO_L47N_2)
/IO_032: P9.37, U1.C6 (IO_L3N_0)
/IO_033: P9.34, U1.D6 (IO_L3P_0)
/IO_034: P9.36, U1.A5 (IO_L2N_0)
/IO_035: P9.38, U1.C5 (IO_L2P_0)
/IO_072: P8.5, U1.AA18 (IO_L14P_D11_2)
/IO_073: P8.7, U1.AB18 (IO_L14N_D12_2)
/IO_074: P8.9, U1.U10 (IO_L52N_2)
/IO_075: P8.11, U1.T10 (IO_L52P_2)
/IO_076: P9.18, U1.W14 (IO_L20P_2)
/IO_077: P9.20, U1.Y14 (IO_L20N_2)
/IO_078: P9.22, U1.Y15 (IO_L21P_2)
/IO_079: P9.24, U1.AB15 (IO_L21N_2)
/IO_080: P9.26, U1.AB12 (IO_L31N_GCLK30_D15_2)
/IO_081: P9.28, U1.AA12 (IO_L31P_GCLK31_D14_2)
/IO_082: P9.30, U1.AB11 (IO_L32N_GCLK28_2)
/IO_083: P9.32, U1.Y11 (IO_L32P_GCLK29_2)
/IO_084: P9.6, U1.AB5 (IO_L54N_2)
/IO_085: P9.8, U1.Y5 (IO_L54P_2)
/IO_086: P9.10, U1.AB3 (IO_L58N_2)
/IO_087: P9.12, U1.Y3 (IO_L58P_2)
/IO_088: P9.14, U1.Y6 (IO_L53N_2)
/IO_089: P9.16, U1.W6 (IO_L53P_2)
/IO_090: P8.38, U1.AB10 (IO_L41N_VREF_2)
/IO_091: P8.40, U1.AA10 (IO_L41P_2)
/IO_092: P9.2, U1.AB4 (IO_L57N_2)
/IO_093: P9.4, U1.AA4 (IO_L57P_2)
/IO_094: P8.6, U1.W12 (IO_L29P_GCLK3_2)
/IO_095: P8.8, U1.Y12 (IO_L29N_GCLK2_2)
/IO_096: P8.10, U1.AA16 (IO_L19P_2)
/IO_097: P8.12, U1.AB16 (IO_L19N_2)
/IO_098: P8.14, U1.AA14 (IO_L16P_2)
/IO_099: P8.16, U1.AB14 (IO_L16N_VREF_2)
/IO_100: P8.18, U1.Y19 (IO_L5P_2)
/IO_101: P8.20, U1.AB19 (IO_L5N_2)
/IO_102: P8.22, U1.Y17 (IO_L15P_2)
/IO_103: P8.24, U1.AB17 (IO_L15N_2)
/IO_104: P8.26, U1.W18 (IO_L6P_2)
/IO_105: P8.28, U1.Y18 (IO_L6N_2)
/IO_106: P8.30, U1.U6 (IO_L63P_2)
/IO_107: P8.32, U1.V5 (IO_L63N_2)
/IO_108: P8.34, U1.AB8 (IO_L45N_2)
/IO_109: P8.36, U1.AA8 (IO_L45P_2)
/PF_D0: U1.AA20 (IO_L3P_D0_DIN_MISO_MISO1_2), U3.28 (D0)
/PF_D1: U1.U14 (IO_L12P_D1_MISO2_2), U3.29 (D1)
/PF_D2: U1.U13 (IO_L12N_D2_MISO3_2), U3.32 (D2)
/PF_D3: U1.AA6 (IO_L49P_D3_2), U3.33 (D3)
/PF_D4: U1.AB6 (IO_L49N_D4_2), U3.43 (D4)
/PF_D5: U1.W4 (IO_L62P_D5_2), U3.44 (D5)
/PF_D6: U1.Y4 (IO_L62N_D6_2), U3.47 (D6)
/PF_D7: U1.Y7 (IO_L48P_D7_2), U3.48 (D7)
/PF_TDO: P11.1, U3.22 (TDO)
/PIC_IO1: U1.W11 (IO_L42N_2), U12.18 (INT0/FLT0/AN12/RB0)
/PIC_IO2: U1.V11 (IO_L42P_2), U12.19 (INT1/AN10/RB1)
/PIC_IO3: U1.V19 (IO_L9P_2), U12.20 (INT2/AN8/RB2)
/PIC_IO4: U1.V18 (IO_L9N_2), U12.21 (CCP2/AN9/RB3)
/PIC_IO5: U1.R16 (IO_L10P_2), U12.8 (T1OSO/T13CKI/RC0)
/PIC_IO6: U1.R15 (IO_L10N_2), U12.9 (CCP2/T1OSI/CCP2/RC1)
/PIC_MCLR: P5.1, U12.26 (_MCLR/VPP/RE3)
/PIC_PGC: P5.9, U12.24 (KBI2/PGC/RB6)
/PIC_PGD: P5.7, U12.25 (KBI3/PGD/RB7)
/PIC_RX: P5.4, P5.10, U12.15 (RX/DT/RC7)
/V1.2: C12.1, C16.1, C20.1, U6.3 (VO)
/V1.2temp: C2.1, C33.1, C37.1, C40.1, C41.1, C43.1, U1.J8 (VCCINT), U1.J10 (VCCINT), U1.J12 (VCCINT), U1.J14 (VCCINT), U1.K9 (VCCINT), U1.K11 (VCCINT), U1.K13 (VCCINT), U1.L10 (VCCINT), U1.L12 (VCCINT), U1.L14 (VCCINT), U1.M9 (VCCINT), U1.M11 (VCCINT), U1.M13 (VCCINT), U1.N10 (VCCINT), U1.N12 (VCCINT), U1.N14 (VCCINT), U1.P9 (VCCINT), U1.P11 (VCCINT), U1.P13 (VCCINT), U1.R14 (VCCINT)
/V1.5: C13.1, C17.1, C21.1, U2.51 (VCC), U2.54 (VCC), U2.57 (VCC), U2.60 (VCC), U2.62 (VCC), U2.65 (VCC), U2.66 (VCC), U2.69 (VCC), U2.72 (VCC), U2.75 (VCC), U2.78 (VCC), U2.170 (VCC), U2.173 (VCC), U2.176 (VCC), U2.179 (VCC), U2.182 (VCC), U2.183 (VCC), U2.186 (VCC), U2.189 (VCC), U2.191 (VCC), U2.194 (VCC), U2.197 (VCC), U7.4 (VO), U7.5 (SENSE/ADJ), U8.1 (VDDQSNS), U8.2 (VLDOIN)
/V1.5temp: U1.C2 (VCCO_3), U1.C21 (VCCO_1), U1.E19 (VCCO_1), U1.F4 (VCCO_3), U1.F6 (VCCO_3), U1.G2 (VCCO_3), U1.G21 (VCCO_1), U1.J5 (VCCO_3), U1.J18 (VCCO_1), U1.L2 (VCCO_3), U1.L7 (VCCO_3), U1.L16 (VCCO_1), U1.L21 (VCCO_1), U1.N5 (VCCO_3), U1.N18 (VCCO_1), U1.R2 (VCCO_3), U1.R21 (VCCO_1), U1.U5 (VCCO_3), U1.U18 (VCCO_1), U1.W2 (VCCO_3), U1.W21 (VCCO_1)
/V1.8: C11.1, C15.1, C19.1, U3.4 (VCCINT), U3.15 (VCCINT), U3.34 (VCCINT), U4.2 (VO)
/V2.5: C46.1, C47.1, C48.1, U9.1 (OE/StandBy), U9.4 (VDD), U10.2 (VO)
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

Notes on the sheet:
CPLD XC9532XL VQ44
POWER
3.3V Fixed 5A, 6.3 V- 12 V TO-232-3 Digi# AZ1084CS2-3.3TRE1DICT-ND
MOUNTING HOLES
LOGOs
Unused CPLD pins
LED's
Signals coming from CPLD for these
I/O from connector to/from CPLD
D11 C12 A3 A4 D7 D8 B8 A8 D6 C6 C5 A5 B6 A6 C7 A7
XCF16P - VOG48
FPGA pin D0 -> AA20 D1 -> U14 D2 -> U13 D3 -> AA6 D4 -> AB6 D5 -> W4 D6 -> Y4 D7 -> Y7 M0 -> AA22 M1 -> U15 HSWAPEN -> A3 DONE_2 -> Y22 CCLK -> Y21 INIT_B -> T6 CSI_B -> AB20 CSO_B -> T5 PROGRAM_B -> AA1 RDWR_B -> AB7 DOUT_BUSY -> T20 SUSPEND -> N15 TCK -> G15 TDI -> E18 TMS -> C18 TDO -> A19
output from PF -> into Adapter board from Adapter board -> input to FPGA
W12 Y12 AA14 AB14 AA21 AB21 Y19 AB19 U15 V15 Y21 AA22 T6 T5 AA20 AB20
1.2V
1.2V Fixed 1.5A , Vin 2.5 V-9 V TO-232-3 Digi# NCP565D2T12GOS-ND
3.3V
2+tab
1.5V
1.5V Fixed 3A , Vin 2.7 V- 20 V TO-263-6, D²Pak (5 Leads + Tab), TO-263BA LT1764EQ-1.5#PBF-ND
1.8V Fixed 800mA, up to 15 V SOT-223 Digi# LM1117MP-1.8/NOPBCT-ND
1.8V
from Adapter board -> input to FPGA
output from PF -> into Adapter board
JTAG Chain
DONE_LED
PROG_B
Leave unconnected or pull to VCCO_2
2.5V Fixed 1.5A, up to 15 Vin SOT-223 Digi# LM1117MPX-2.5/NOPBCT-ND or ebay: AMS1117-2.5
2.5V
FPGA DONE Signal: Active-High signal indicating configuration is complete: 0 = FPGA not configured 1 = FPGA configured

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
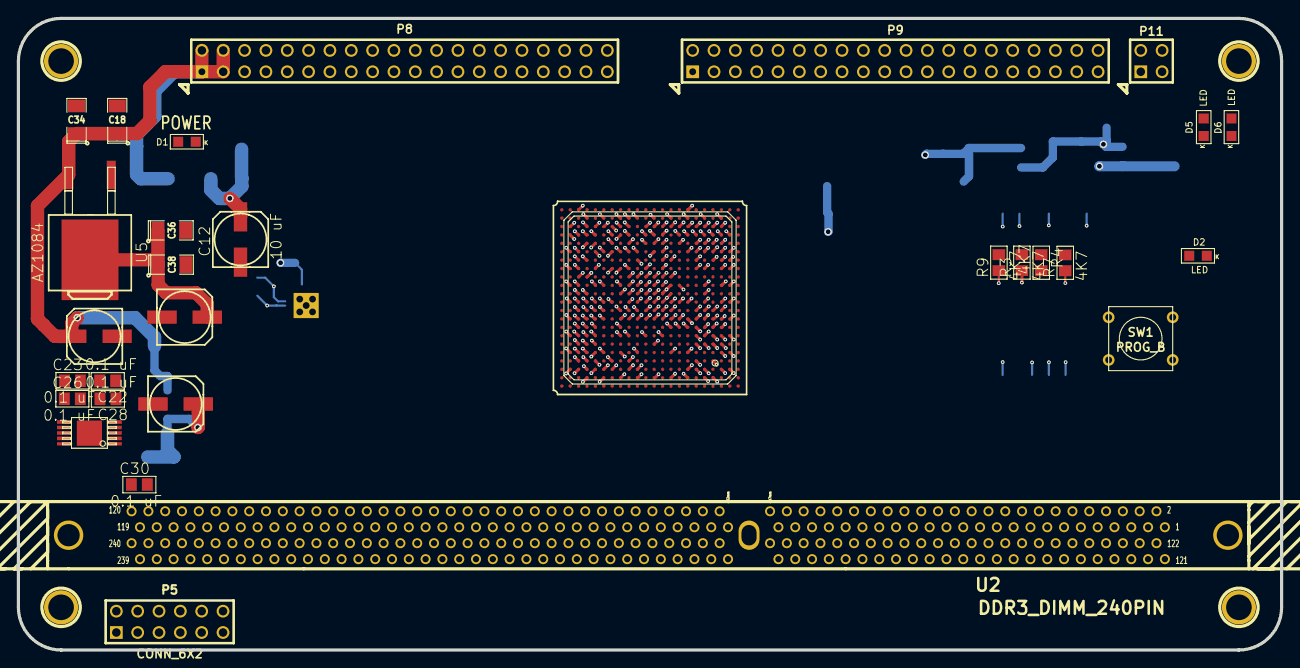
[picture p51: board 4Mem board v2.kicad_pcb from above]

Board: 6 copper layers, 150.4 x 75.2 mm, 86 parts (0 on the bottom side), 246 nets.

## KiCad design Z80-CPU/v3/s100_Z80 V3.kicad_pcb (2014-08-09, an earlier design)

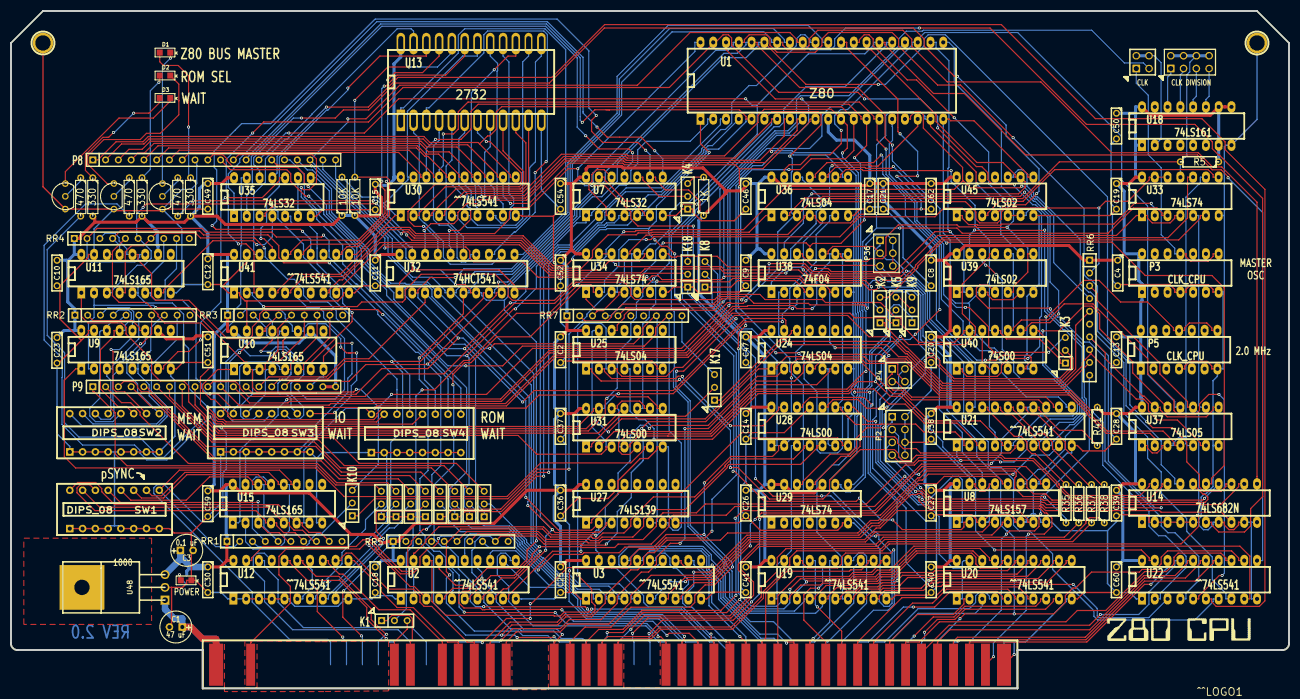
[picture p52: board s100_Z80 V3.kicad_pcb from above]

Board: 2 copper layers, 254.0 x 134.6 mm, 140 parts (0 on the bottom side), 291 nets.

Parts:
C1: 47 uF; C1V7
C2, C4, C8, C9, C10, C11, C12, C13, C14, C15, C17, C18, C19, C20, C23, C25, C26, C27, C28, C30, C36, C37, C38, C39, C40, C41, C46, C47, C49, C50, C51, C52, C54, C59, C60, C62: 0.1 uF; C2
C3: 0.1 uF; C1V7
C21: 100nF; C2
D1, D2: DONE; ^^LED-0805
D3: WAIT; ^^LED-0805
D8: D2-1; ^^LED-0805
K1, K2, K4: CONN_3; SIL-3
K3: pSYNCdata; SIL-3
K5: pSYNC; SIL-3
K6: bA15; SIL-3
K7: bA14; SIL-3
K8: WRstrobe; SIL-3
K9: U29B Q; SIL-3
K10: U15 Clock; SIL-3
K11: bA13; SIL-3
K12: bA12; SIL-3
K13: bA19; SIL-3
K14: bA18; SIL-3
K15: bA16; SIL-3
K16: bA17; SIL-3
K17: EN_WAITS; SIL-3
K18: ROM_E-; SIL-3
P1: S100_MALE
P2: CONN_4X2; pin_array_4x2
P3, P5: CLK_CPU; DIP-14__300_ELL
P4: CONN_2X2; PIN_ARRAY_2X2
P6: MASTER_OSC; PIN_ARRAY_2X2
P7: CLK_SEL; Pin_Array_4X2
P8, P9: CONN_20; ^^SIL-20
P34, P35: CONN_1; 1pin
P36: CONN_3X2; pin_array_3x2
Q1, Q2, Q3: NPN; ^^TO92-inline
R1, R3, R5, R8: 330; R3
R2, R6, R9: 470; R3
R4: 330; ^^SMD_Resistor-0805
R7: 1K; R3
R11, R16: 10K; R3
R35, R36, R37, R38: 10; R3
R41: 4700; R3
RR1, RR2, RR3, RR4, RR5, RR6: 1000; r_pack9
RR7: 4700; r_pack9
SW1, SW2, SW3, SW4: DIPS_08; SWDIP8
U1: Z80; DIP-40__600_ELL
U2, U3, U12, U19, U20, U21, U22, U30, U41: ^^74LS541; DIP-20__300_ELL
U7, U35: 74LS32; DIP-14__300_ELL
U8: 74LS157; DIP-16__300_ELL
U9, U10, U11, U15: 74LS165; DIP-16__300_ELL
U13: 2732; ^^DIP-24-ZIF
U14: 74LS682N; DIP-20__300_ELL
U18: 74LS161; DIP-16__300_ELL
U24, U25, U36: 74LS04; DIP-14__300_ELL
U26: ^^LOGO1; ***Z80cpuV32
U27: 74LS139; DIP-16__300_ELL
U28, U31: 74LS00; DIP-14__300_ELL
U29, U33, U34: 74LS74; DIP-14__300_ELL
U32: 74HCT541; DIP-20__300_ELL
U37: 74LS05; DIP-14__300_ELL
U38: 74F04; DIP-14__300_ELL
U39, U45: 74LS02; DIP-14__300_ELL
U40: 74S00; DIP-14__300_ELL
U48: LDO_REG_7805; ^^TO220

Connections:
/2MHZ_CLOCK: P5.8, P5.11, U21.7
/27_ROM_OE: U28.10, U36.5, U40.8, U41.8
/+8V: C1.1, P1.1, P1.51, U48.1
/A0: P1.79, U2.11
/A1: P1.80, U2.12
/A2: P1.81, U2.13
/A3: P1.31, U2.14
/A4: P1.30, U2.15
/A5: P1.29, U2.16
/A6: P1.82, U2.17
/A7: P1.83, U2.18
/A8: P1.84, U3.11
/A9: P1.34, U3.12
/A10: P1.37, U3.13
/A11: P1.87, U3.14
/A12: P1.33, U3.15
/A13: P1.85, U3.16
/A14: P1.86, U3.17
/A15: P1.32, U3.18
/A16: P1.16, U12.11
/A17: P1.17, U12.12
/A18: P1.15, U12.13
/A19: P1.59, U12.14
/A20: P1.61, U12.15
/A21: P1.62, U12.16
/A22: P1.63, U12.17
/A23: P1.64, U12.18
/ADSB: U2.19, U3.19, U12.19, U24.2
/ADSB*: P1.22, RR5.9, U24.1, U37.4
/BUSAK*: U1.23, U36.13, U37.11
/BUSRQ*: U1.25, U34.5
/CDSB*: P1.19, RR6.7, U37.8, U37.13
/CLK_CPU: K10.3, P7.2, P7.4, P7.6, P7.8, R5.2, U1.6, U9.2, U10.2, U11.2, U33.11, U36.3
/CLOCK*: P1.49, P4.2
/D0: P8.8, U1.14, U19.9, U20.11, U30.18
/D1: P8.7, U1.15, U19.8, U20.12, U30.17
/D2: P8.6, U1.12, U19.7, U20.13, U30.16
/D3: P8.5, U1.8, U19.6, U20.14, U30.15
/D4: P8.4, U1.7, U19.5, U20.15, U30.14
/D5: P8.3, U1.9, U19.4, U20.16, U30.13
/D6: P8.2, U1.10, U19.3, U20.17, U30.12
/D7: P8.1, U1.13, U19.2, U20.18, U30.11
/DATA_OUT_ENABLE: K8.3, U20.1, U20.19, U28.8
/DI0: P1.95, U20.9
/DI1: P1.94, U20.8
/DI2: P1.41, U20.7
/DI3: P1.42, U20.6
/DI4: P1.91, U20.5
/DI5: P1.92, U20.4
/DI6: P1.93, U20.3
/DI7: P1.43, U20.2
/DO0: P1.36, U19.11
/DO1: P1.35, U19.12
/DO2: P1.88, U19.13
/DO3: P1.89, U19.14
/DO4: P1.38, U19.15
/DO5: P1.39, U19.16
/DO6: P1.40, U19.17
/DO7: P1.90, U19.18
/DODSB*: P1.23, RR5.8, U28.2, U37.2
/ERROR*: P1.98, RR6.10
/HALT*: U1.18, U38.1
/HOLD*: P1.74, RR5.4, U34.2, U45.2
/INT*: P1.73, RR5.3, U21.9
/IORQ*: P9.10, U1.20, U38.5, U39.3, U39.6, U40.5, U40.13, U45.8
/IORQ+: P8.15, U8.1, U31.10, U38.6
/M1*: U1.27, U38.13, U45.9
/M1+: P36.5, U22.7, U38.12
/MREQ*: P9.9, U1.19, U38.11, U39.9
/MREQ+: P36.3, U38.10, U40.2
/MWRT: P1.68, P4.4
/MWRTb: U21.8, U39.13
/NDEF3: P1.66, P6.3
/NMI*: K1.2, RR6.4, U1.17
/NMI*s100: K1.3, P1.12
/PHI: P1.24, R41.2, U21.14
/PU1K-D: P1.72, RR5.5, U28.4
/PU1K-E: P1.3, RR5.6, U28.5
/PU1K-F: RR5.7, U21.1, U37.12
/PU1K-J: RR6.2, U33.12, U33.13, U36.12
/PU1K-JJ: P1.60, RR5.2
/PU1K-K: P1.26, RR6.3, U37.10
/PU1K-N: K2.1, RR6.5
/PU1K-T: P1.18, RR6.8, U25.3, U37.6
/PU1K-Y: P1.58, RR6.9
/PU1K-cp1: P8.17, RR7.8, U27.6
/PU1K-cp2: P8.16, RR7.9, U27.7
/PU1K-waits: K17.3, RR7.10
/PU5K-A: RR7.2, U33.10
/PU5K-B: RR7.3, U34.1, U34.4
/PU5K-C: P8.14, RR7.4, U1.26, U22.11, U34.10
/PU5K-D: RR7.5, U33.1, U33.4
/PWRFAIL*: K1.1, P1.13
/RD*: P9.12, U1.21, U38.9, U39.5, U39.8
/RD+: U21.2, U28.9, U38.8
/REFSH*: U1.28, U40.1, U45.5, U45.6
/RESET*: P1.75, U22.9
/ROM_E-: K18.3, U7.9, U41.14
/ROM_E-33: P9.17, U41.6
/ROM_SELECT: R6.2, U31.13, U36.6
/U4p7: K12.3, P9.8
/U4p9: K11.3, P9.7
/U5p4: K13.3, P9.1
/U5p7: K14.3, P9.2
/U5p9: K16.3, P9.4
/U5p12: K15.3, P9.3
/U6p7: K7.3, P9.6
/U6p9: K6.3, P9.5
/WAIT*: U1.24, U25.12
/WAIT+: R9.2, U25.13, U31.3
/WR*: P9.11, U1.22, U35.13, U38.3, U39.2
/WR+: K8.1, U24.3, U38.4
/Z80_ACTIVE: R2.2, U34.9
/bA0: P9.13, U1.30, U2.9, U27.2, U32.2
/bA1: P9.14, U1.31, U2.8, U27.3, U32.3
/bA2: P8.18, U1.32, U2.7, U14.6, U32.4
/bA3: P8.19, U1.33, U2.6, U14.8, U32.5
/bA4: U1.34, U2.5, U14.11, U32.6
/bA5: P8.20, U1.35, U2.4, U14.13, U32.7
/bA6: P9.15, U1.36, U2.3, U14.15, U32.8
/bA7: P9.16, U1.37, U2.2, U14.17, U32.9
/bA8: U1.38, U8.14, U41.2
/bA9: U1.39, U8.11, U41.3
/bA10: U1.40, U8.5, U41.4
/bA11: U1.1, U8.2, U41.5
/bA12: K12.1, P8.10, U1.2, U7.1
/bA13: K11.1, P8.11, U1.3, U7.2
/bA14: K7.1, P8.12, U1.4, U7.4
/bA15: K6.1, P8.13, U1.5, U7.5
/bA16: K15.2, U12.9
/bA17: K16.2, U12.8
/bA18: K14.2, U12.7
/bA19: K13.2, U12.6
/bINT*: U1.16, U21.11
/pDBIN: P1.78, R35.1
/pSTVAL*: P1.25, R37.1
/pSYNC: P1.76, R36.1
/pSYNCb: K5.2, U21.3, U31.4, U31.9, U31.12
/pWR*: P1.77, R38.1
/pWR*b: U21.5, U24.4, U39.12
/sHLTA: P1.48, U22.18
/sINP: P1.46, U22.16
/sINTA: P1.96, P36.1, U22.12
/sINTAb: U22.8, U45.10
/sM1: P1.44, U22.13
/sMEMR: P1.47, U22.15
/sMEMRb: U22.5, U39.10, U40.10
/sOUT: P1.45, U22.17
/sOUTb: U22.3, U28.12, U39.1, U39.11
/sWO*: P1.97, U22.14
/sWO*b: U22.6, U35.11
GND: C1.2, C2.2, C3.2, C4.2, C8.2, C9.2, C10.2, C11.2, C12.2, C13.2, C14.2, C15.2, C17.2, C18.2, C19.2, C20.2, C21.2, C23.2, C25.2, C26.2, C27.2, C28.2, C30.2, C36.2, C37.2, C38.2, C39.2, C40.2, C41.2, C46.2, C47.2, C49.2, C50.2, C51.2, C52.2, C54.2, C59.2, C60.2, C62.2, D8.2, K4.1, K13.1, K14.1, K15.1, K16.1, K18.1, P1.50, P1.100, P2.2, P2.4, P2.6, P2.8, P3.4, P3.7, P5.4, P5.7, P8.9, P9.18, P34.1, P35.1, Q1.1, Q2.1, Q3.1, SW1.1, SW1.2, SW1.3, SW1.4, SW1.5, SW1.6, SW1.7, SW1.8, SW2.1, SW2.2, SW2.3, SW2.4, SW2.5, SW2.6, SW2.7, SW2.8, SW3.1, SW3.2, SW3.3, SW3.4, SW3.5, SW3.6, SW3.7, SW3.8, SW4.1, SW4.2, SW4.3, SW4.4, SW4.5, SW4.6, SW4.7, SW4.8, U1.29, U2.1, U2.10, U3.1, U3.10, U7.7, U8.3, U8.6, U8.8, U8.10, U8.13, U8.15, U9.8, U9.15, U10.8, U10.15, U11.8, U11.15, U12.1, U12.2, U12.3, U12.4, U12.5, U12.10, U13.12, U14.2, U14.3, U14.4, U14.5, U14.7, U14.9, U14.10, U15.8, U15.15, U18.8, U19.10, U20.10, U21.10, U22.1, U22.10, U24.7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
unnamed: U22.19, U25.4
unnamed: U19.1, U19.19, U28.3
unnamed: R36.2, U21.17
unnamed: U21.19, U34.8
unnamed: U40.3, U40.4, U40.12
unnamed: P4.3, U21.12
unnamed: P4.1, U21.13
unnamed: R38.2, U21.15
unnamed: K12.2, U3.5
unnamed: K7.2, U3.3
unnamed: K11.2, U3.4
unnamed: U3.6, U8.4
unnamed: U3.7, U8.7
unnamed: U3.8, U8.9
unnamed: U3.9, U8.12
unnamed: D2.2, Q3.3
unnamed: D2.1, R3.1
unnamed: Q3.2, R6.1
unnamed: RR3.4, SW3.11, U10.13
unnamed: RR3.3, SW3.10, U10.12
unnamed: RR3.2, SW3.9, U10.11
unnamed: U10.1, U31.8
unnamed: U11.1, U31.11
unnamed: RR3.5, SW3.12, U10.14
unnamed: RR3.6, SW3.13, U10.3
unnamed: RR3.7, SW3.14, U10.4
unnamed: RR3.9, SW3.16, U10.6
unnamed: RR3.8, SW3.15, U10.5
unnamed: P6.2, P6.4, U18.2
unnamed: P7.7, U18.11
unnamed: P7.5, U18.12
unnamed: P7.3, U18.13
unnamed: P7.1, U18.14
unnamed: RR2.4, SW2.11, U9.13
unnamed: RR2.3, SW2.10, U9.12
unnamed: RR2.2, SW2.9, U9.11
unnamed: RR2.9, SW2.16, U9.6
unnamed: RR2.8, SW2.15, U9.5
unnamed: RR2.7, SW2.14, U9.4
unnamed: RR2.6, SW2.13, U9.3
unnamed: RR2.5, SW2.12, U9.14
unnamed: RR4.2, SW4.9, U11.11
unnamed: RR4.5, SW4.12, U11.14
unnamed: RR4.4, SW4.11, U11.13
unnamed: RR4.3, SW4.10, U11.12
unnamed: RR4.9, SW4.16, U11.6
unnamed: RR4.8, SW4.15, U11.5
unnamed: RR4.7, SW4.14, U11.4
unnamed: RR4.6, SW4.13, U11.3
unnamed: K8.2, U28.1
unnamed: U33.5, U37.9
unnamed: U7.8, U35.1
unnamed: U7.6, U7.13
unnamed: U7.3, U7.12
unnamed: U7.11, U35.2
unnamed: U35.3, U36.1
unnamed: K4.2, U7.10
unnamed: D1.2, Q2.3
unnamed: D1.1, R1.1
unnamed: Q2.2, R2.1
unnamed: P3.8, P3.11, P6.1
unnamed: U9.7, U35.10
unnamed: U13.1, U32.11
unnamed: U13.2, U32.12
unnamed: U13.3, U32.13
unnamed: U13.4, U32.14
unnamed: U13.5, U32.15
unnamed: U13.6, U32.16
unnamed: U13.7, U32.17
unnamed: U13.8, U32.18
unnamed: U24.5, U28.6
unnamed: U24.6, U31.2
unnamed: R16.2, U13.20, U41.12
unnamed: U13.23, U41.18
unnamed: U13.22, U41.17
unnamed: U13.19, U41.16
unnamed: U13.21, U41.15
unnamed: K18.2, U41.9
unnamed: U13.13, U30.5
unnamed: U13.9, U30.2
unnamed: U13.10, U30.3
unnamed: U13.11, U30.4
unnamed: D8.1, R4.1
unnamed: U13.14, U30.6
unnamed: U13.15, U30.7
unnamed: U13.16, U30.8
unnamed: U13.17, U30.9
unnamed: K17.2, U31.1
unnamed: K17.1, U24.12
unnamed: R11.2, U13.18, U30.1, U30.19, U41.11
unnamed: K4.3, R7.2
unnamed: U35.12, U45.4
unnamed: D3.1, R8.1
unnamed: D3.2, Q1.3
unnamed: Q1.2, R9.1
unnamed: K10.2, U15.2
unnamed: K5.1, U15.7
unnamed: RR1.4, SW1.11, U15.13
unnamed: RR1.3, SW1.10, U15.12
unnamed: RR1.2, SW1.9, U15.11
unnamed: U15.1, U36.8
unnamed: RR1.9, SW1.16, U15.6
unnamed: RR1.8, SW1.15, U15.5
unnamed: RR1.7, SW1.14, U15.4
unnamed: RR1.6, SW1.13, U15.3
unnamed: RR1.5, SW1.12, U15.14
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

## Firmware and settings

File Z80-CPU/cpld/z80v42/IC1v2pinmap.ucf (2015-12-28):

#PIN MAP OF IC1 on Z80 Board V4
#Date: 30-06-2015
# Target XC9572 PC84

#24+22+16=62

#29+33

#------ OUTPUTS ------------------------------------------------------;24


NET "CPLD_CLKout1"    	LOC =  "P10";   #Clock output
NET "CPLD_CLKout2"    	LOC =  "P12";   #Clock output

NET "RomEn"    	LOC =  "P37";   #Rom enable line from U36 pin5

NET "SINPb"    	LOC =  "P13";   #active high - I/O RD (s100 Pin 46)
NET "sMEMRb"    	LOC =  "P18";   #active high - MEM RD (s100 Pin 47)
NET "sWOb"    		LOC =  "P20";   #active low - Write Output (s100 Pin 97)
NET "SOUTb"    LOC =  "P48";   #active high - I/O WR (s100 Pin 45)
NET "sINTAb"    	LOC =  "P14";   # interrupt ack (s100 Pin 96)

NET "Resout"    LOC =  "P23";   #CPLD reset output- made from button and/or slave clr . i.e via button on board

#NET "U17OE"    LOC =  "P32";   #U17 OE
#NET "U17A"    	LOC =  "P31";   #Data input to bufffer (data 0).

NET "M1pos"    	LOC =  "P19"; 	# negated M1* from CPU
NET "pSYNCb"   	LOC =  "P46";   # (s100 Pin 76)
NET "WAITen"    	LOC =  "P44";   #(s100 Pin 25)
NET "pWRb"    		LOC =  "P51";   #active low - when processor Writes to I/O or MEM (s100 Pin 77)
NET "WRpos"    	LOC =  "P52"; 	# negated WR* from CPU
NET "MREQpos"    LOC =  "P47"; 	# negated MREQ* from CPU
NET "IORQpos"    LOC =  "P54"; 	# negated IORQ* from CPU
NET "RDpos"    	LOC =  "P55"; 	# negated RD* from CPU
NET "PartialLatch"    		LOC =  "P66"; 	# partial latch output 
NET "MWRTb"    	LOC =  "P69";   #active high - MEM WR (s100 Pin 68)

NET "LED_D4"    	LOC =  "P39";   # LED D4
NET "LED_D5"    	LOC =  "P40";   # LED D5
NET "LED_D6"    	LOC =  "P41";   # LED D6
NET "LED_D7"    	LOC =  "P81";   # LED D7
#NET "LED_D9"    	LOC =  "P62";   # LED D9
#NET "LED_D10"    	LOC =  "P50";   # LED D10

NET "P75"    	LOC =  "P75";   #pin 75 i/o pin on board header
NET "P79"    	LOC =  "P79";   #pin 79 i/o pin on board header
NET "P77"    	LOC =  "P77";   #pin 77 i/o pin on board header
NET "P3"    	LOC =  "P3";    #pin 3 i/o pin on board header



#------ INPUTS -------------------------------------------------------;22


NET "RomAddr"    	LOC =  "P45";   #Rom Address range being addresses by CPU - Active HIGH

NET "CLKin"    LOC =  "P9"; 	# MASTER CPU clock input

NET "WRneg"    	LOC =  "P1"; 	# WR* from CPU
NET "MREQneg"    LOC =  "P6"; 	# MREQ* from CPU
NET "REFSHneg"   LOC =  "P11"; 	# REFSH* from CPU
NET "WAITpos"    	LOC =  "P25";   # WAIT+ signal from wait generators
#NET "slaveCLRneg"    LOC =  "P15";   #Slave CLEAR (pin54 S100)
NET "RESb"    LOC =  "P17";   # Reset into CPU from onboard logic
NET "Resbut"  LOC =  "P76";   #Slave clear button on board
NET "IORQneg"    LOC =  "P63"; 	# IORQ* from CPU
#NET "PortD1b7"    LOC =  "P67"; 	# from PortD1 bit 7 on board.
NET "RDneg"    	LOC =  "P72"; 	# RD* from CPU
NET "M1neg"    	LOC =  "P84"; 	# M1* from CPU
#NET "PortD0b7"    LOC =  "P65"; 	# from PortD0 bit 7 on board.

NET "A0"    	LOC =  "P80";   	#Address Line 
NET "A1"    	LOC =  "P83";   	#Address Line 
NET "A2"    	LOC =  "P82";   	#Address Line 
NET "A3"    	LOC =  "P7";   	#Address Line 
NET "A4"    	LOC =  "P2";   	#Address Line 
NET "A5"    	LOC =  "P43";   	#Address Line 
NET "A6"    	LOC =  "P36";   	#Address Line 
NET "A7"    	LOC =  "P71";   	#Address Line 

NET "D0in"    	LOC =  "P33";   #Data Line 


NET "PortD0b7LED"    	LOC =  "P65";   #Port D0 bit 7 (to LED D6)
NET "PortD1b7LED"    	LOC =  "P67";   #Port D1 bit 7 (to LED D7)

#------ I/O -------------------------------------------------------;16

#NET "P8_1"    	LOC =  "P34"; 	# 
#NET "P8_2"    	LOC =  "P35"; 	# 
#NET "P8_3"    	LOC =  "P21"; 	# 
#NET "P8_4"    	LOC =  "P26"; 	# 
#NET "P8_5"    	LOC =  "P68"; 	# 
#NET "P8_6"    	LOC =  "P70"; 	# 
#NET "P8_7"    	LOC =  "P57"; 	# 
#NET "P8_8"    	LOC =  "P53"; 	# 
#NET "P8_9"    	LOC =  "P58"; 	# 
#NET "P8_10"    LOC =  "P61"; 	# 
#NET "P8_11"    LOC =  "P74"; 	# 

#NET "P11_2"    LOC =  "P75"; 	# 
#NET "P11_3"    LOC =  "P79"; 	# 
#NET "P11_4"    LOC =  "P4"; 	#
#NET "P11_5"    LOC =  "P77"; 	#  
#NET "P11_6"    LOC =  "P3"; 	# 

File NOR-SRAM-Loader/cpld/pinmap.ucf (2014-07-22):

#PIN MAP OF U11 on 8Mb Serial NOR to 1MB SRAM board


#------ OUTPUTS ------------------------------------------------------

NET "RESET"    LOC =  "P1";
#NET "CPLD53WAIT"    LOC =  "P53";   #to S100 bus pin72 - WAIT* to MASTER board
NET "BSELLED"    LOC =  "P8";   #Board Select LED output
NET "BROMLED"    LOC =  "P54";   #Board ROM LED output
NET "BMEMLED"    LOC =  "P55";   #Board MEM - SRAM selected LED
NET "DONELED"    LOC =  "P6";   #Board load to Memory DONE LED

NET "CPLDP12ROM1OE"    LOC =  "P12";   #to UVEPROM OE active low
NET "CPLDP92ROM1CS"    LOC =  "P92";   #to UVEPROM CS active low

NET "DBUSOUTEN"    	LOC =  "P13";   #active low - for slave Data OUTPUT
NET "DBUSINEN"    	LOC =  "P18";   #active low - for slave Data INPUT


NET "CPLD_59"    	LOC =  "P59";   #active low output to pin19 of U26, U25, U24 - RAM/ROM2 Buffers
NET "U23DIR"    	LOC =  "P56";   #U23 Direction - Data Bus Buffer to RAM/ROM2
NET "U23CE"    	LOC =  "P58";   #U23 Chip Enable  - active low -

NET "ROM2_0_CS"   LOC =  "P9";   # ROM2 low bank CS
NET "ROM2_1_CS"   LOC =  "P11";   #ROM2 high bank CS
NET "ROM2_OE"    	LOC =  "P10";   #ROM2 OE
NET "ROM2_WE"    	LOC =  "P78";   #ROM2 WE

NET "PINCPLD79"    	LOC =  "P79";   #out pin header to pin 79 of cpld
NET "PINCPLD90"    	LOC =  "P90";   #out pin header to pin 90 of cpld
NET "PINCPLD89"    	LOC =  "P89";   #out pin header to pin 89 of cpld

NET "NOR_CLK"    		LOC =  "P93";   	#
NET "NOR_DIN"    		LOC =  "P95";   	#(Data from System to 25P80) at 0x81
NET "NOR_CS"    		LOC =  "P96";   	#
NET "NOR_DOUT"    	LOC =  "P97";   	#Dout (Data from 25P80 into System at 0x83


#------ INPUTS -------------------------------------------------------


NET "BOARDSELECT"    LOC =  "P41";   #board select from 74LS682

NET "sM1"    			LOC =  "P16";   #sM1 active high when processor is in instruction fetch
NET "sOUT"    			LOC =  "P65";   #active high - I/O WR
NET "sINP"    			LOC =  "P67";   #active high - I/O RD
NET "sMEMR"    		LOC =  "P71";   #active high - MEM RD
NET "IOREQb"    		LOC =  "P72";   #active low - IORQ
NET "MWRT"    			LOC =  "P68";   #active high - MEM WR
NET "NDEF2"    		LOC =  "P76";   #active low - MREQ
NET "SLAVECLRvv"    	LOC =  "P85";   #reset input from another board - from the MASTER

NET "pWR"    			LOC =  "P70";   #active low - when processor Writes to I/O or MEM
NET "pDBIN"    		LOC =  "P66";   #active high - when processor Reads from I/O or MEM
NET "sWO"    			LOC =  "P81";   #
NET "CLOCK"    		LOC =  "P23";   #clock line from another board - s100 pin49
NET "PHI"    			LOC =  "P27";   #Primary Processor Clock line - S100 pin24

NET "A0"    		LOC =  "P14";   #
NET "A1"    		LOC =  "P15";   #
NET "A2"    		LOC =  "P25";   #
NET "A3"    		LOC =  "P17";   #
NET "A4"    		LOC =  "P28";   #
NET "A5"    		LOC =  "P33";   #
NET "A6"    		LOC =  "P74";   #
NET "A7"    		LOC =  "P82";   #
NET "A8"    		LOC =  "P61";   #
NET "A9"    		LOC =  "P50";   #
NET "A10"    		LOC =  "P42";   #
NET "A11"    		LOC =  "P60";   #
NET "A12"    		LOC =  "P64";   #
NET "A13"    		LOC =  "P77";   #
NET "A14"    		LOC =  "P63";   #
NET "A15"    		LOC =  "P86";   #

NET "A20"    		LOC =  "P32";   #
NET "A21"    		LOC =  "P49";   #
NET "A22"    		LOC =  "P35";   #
NET "A23"    		LOC =  "P37";   #

NET "D0"    		LOC =  "P36";   #
NET "D1"    		LOC =  "P29";   #
NET "D2"    		LOC =  "P39";   #
NET "D3"    		LOC =  "P30";   #
NET "D4"    		LOC =  "P40";   #
NET "D5"    		LOC =  "P87";   #
NET "D6"    		LOC =  "P94";   #
NET "D7"    		LOC =  "P91";   #

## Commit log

2013-07-22 Z80-FPGA-SBC: REV 1.0 layout and fab gerbers (XC9572XL CPLD2 + MAX3002 translators)
    Source: Z80 Board ANTS_MOD 2/ECB SBC V2/gerbers/ (plotted 2013-07-22 15:39) and
    ECB SBC V2/SBC.000, committed as rev1.0/SBC_rev1.0.brd.
    SBC.000 is the last save of the REV 1.0 board by PCBNEW 2011-07-08 (header
    '7/22/2013 3:35:24 PM'), kept by KiCad as a backup copy when the board was later
    re-saved by a newer KiCad. It is the only surviving REV 1.0 layout: its vias +
    through-hole pads (1249 + 457 = 1706) match the 1706 holes in gerbers/SBC.drl.
    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
    [SBC-Bottom.gbl, SBC-Mask_Back.gbs, SBC-Mask_Front.gts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]
2013-08-02 Backplane-18-Slot rev1: start from the N8VEM S-100 backplane v02 project: 17 slots, active terminator, XC9572XL bus extras
    Source: S100 Backplane ANTS_MOD/S100 Backplane-001/BACKUPS/backup 03082013 0353/S100 Backplane-001
    [S100-Backplane.brd, S100-Backplane.sch]
2013-08-02 Backplane-18-Slot rev1: PCB layout
    Source: S100 Backplane ANTS_MOD/S100 Backplane-001/BACKUPS/backup 03082013 0543/S100 Backplane-001
    [S100-Backplane.brd]
2013-08-04 Backplane-18-Slot rev1: add logo and resistors; board 406x216 mm
    Source: S100 Backplane ANTS_MOD/S100 Backplane-001/BACKUPS/backup 04082013 1842/S100 Backplane-001
    [S100-Backplane.brd, S100-Backplane.sch]
2013-08-04 Backplane-18-Slot rev1: add second logo; layout
    Source: S100 Backplane ANTS_MOD/S100 Backplane-001/BACKUPS/backup 05082013 0041/S100 Backplane-001
    [S100-Backplane.brd, S100-Backplane.sch]
2013-08-21 Backplane-18-Slot rev1: add ATX PSU section and experimental logic (MSX slot, 27C801); RESET(s) jumper
    Source: S100 Backplane ANTS_MOD/S100 Backplane-001/BACKUPS/backup 21082013 1727/S100 Backplane-001
    From here to 20-10-2013 the schematic and board also hold the ATX PSU sub-board (refs 9xxx).
    [S100-Backplane.brd, S100-Backplane.csv, S100-Backplane.sch]
2013-08-25 Z80-FPGA-SBC: REV 2 rework: drop CPLD2/MAX3002s, 74LS245/541 S-100 buffers, new regulators
    Source: Z80 Board ANTS_MOD 2/backyp 26082013 1143/ECB SBC V2 (folder name typo 'backyp' is original).
    Schematic started from the N8VEM SBC V2 (Andrew Lynch / N8VEM); see README credits.
    Layout text still reads 'REV 1.0' at this point.
    [SBC.brd, SBC.csv, SBC.sch]
2013-08-26 Z80-FPGA-SBC: REV 2 layout edits (midday backup)
    Source: Z80 Board ANTS_MOD 2/backup 26082013 1325/ECB SBC V2.
    Only SBC.brd changed since the previous backup.
    [SBC.brd]
2013-08-26 Z80-FPGA-SBC: REV 2 layout edits (afternoon backup)
    Source: Z80 Board ANTS_MOD 2/backup 26082013 1452/ECB SBC V2.
    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
    [SBC.brd]
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2013-09-09 Z80-FPGA-SBC: REV 2.0 layout
    Source: Z80 Board ANTS_MOD 2/ECB SBC V2 (working folder): SBC.brd.
    [SBC.brd]
2013-09-12 Z80-FPGA-SBC: schematic edits
    Source: Z80 Board ANTS_MOD 2/ECB SBC V2 (working folder): SBC.sch, SBC-cache.lib.
    [SBC.sch]
2013-10-07 Backplane-18-Slot rev1: 18 slots; PIC18F2550 PSU control; XC6SLX9/FT232R experiments; first gerbers
    Source: S100 Backplane ANTS_MOD/S100 Backplane-001/BACKUPS/backup 07102013 1647/S100 Backplane-001
    [S100-Backplane.brd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]
2013-10-07 Backplane-18-Slot rev1: drop SRAM/JTAG extras; 74LVC245 buffers
    Source: S100 Backplane ANTS_MOD/S100 Backplane-001/BACKUPS/backup 07102013 2322/S100 Backplane-001
    [S100-Backplane.brd, S100-Backplane.sch]
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2013-10-16 Backplane-18-Slot rev1: layout
    Source: S100 Backplane ANTS_MOD/S100 Backplane-001/BACKUPS/backup 17102013 0136/S100 Backplane-001
    Dated from the .brd (2013-10-16): the .sch and -cache.lib in this backup were re-saved later (2013-10-26) without schematic changes.
    [S100-Backplane.brd]
2013-10-18 Backplane-18-Slot rev1: remove FPGA/USB section; PIC18F1330 PSU; trimpot, D44C/D45C; new gerbers
    Source: S100 Backplane ANTS_MOD/S100 Backplane-001/BACKUPS/backup 18102013 1134/S100 Backplane-001
    [S100-Backplane.brd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]
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2013-10-19 Backplane-18-Slot rev1: add P25-P28 bus headers; reset RC 10R/10uF
    Source: S100 Backplane ANTS_MOD/S100 Backplane-001/BACKUPS/backup 19102013 1942/S100 Backplane-001
    [S100-Backplane.brd, S100-Backplane.sch]
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2013-10-19 Backplane-18-Slot rev1: layout and project settings
    Source: S100 Backplane ANTS_MOD/S100 Backplane-001/BACKUPS/backup 20102013 1136/S100 Backplane-001
    [S100-Backplane.brd]
2013-11-02 S6LX9-FPGA-IO: first schematic and PCB placement (XC6SLX9-TQ144 S-100 I/O board)
    Source: S100 FPGA_TIMER_INT_CONTROLLER/backups/03112013 0447 (KiCad project TMRINT, original folder name FPGA_TIMER_INT_CONTROLLER)
    [TMRINT.brd, TMRINT.sch]
2013-11-02 S6LX9-FPGA-IO: schematic tweaks (R1 4K8 to 6K8), placement
    Source: S100 FPGA_TIMER_INT_CONTROLLER/backups/03112013 0658 (KiCad project TMRINT, original folder name FPGA_TIMER_INT_CONTROLLER)
    [TMRINT.brd, TMRINT.sch]
2013-11-02 S6LX9-FPGA-IO: add six FPGA LEDs and FPGA I/O header P3
    Source: S100 FPGA_TIMER_INT_CONTROLLER/backups/03112013 1002 (KiCad project TMRINT, original folder name FPGA_TIMER_INT_CONTROLLER)
    [TMRINT.brd, TMRINT.sch]
2013-11-16 S6LX9-FPGA-IO: add data buffer U8, U18 74LS541 to 74HC245; first routed PCB
    Source: S100 FPGA_TIMER_INT_CONTROLLER/backups/17112013 1254 (KiCad project TMRINT, original folder name FPGA_TIMER_INT_CONTROLLER)
    [TMRINT.brd, TMRINT.sch]
2014-03-11 Backplane-18-Slot rev1: Rev 1.0 final: ATX PSU split off, 15.7x8.0 in board, gerbers and BOM
    Source: S100 Backplane ANTS_MOD/S100 Backplane-001/S100 Backplane-001
    S100-Backplane.pro is taken from S100 Backplane ANTS_MOD/V1 - backup 22-10-2015 (same content, saved 2013-10-20); the working-folder copy was only re-saved in 2016.
    [S100-Backplane.brd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]
2014-03-11 S6LX9-FPGA-IO: 1.2 V LDO replaces LTC3419, add M25P80, final routing, gerbers and BOM
    Source: S100 FPGA_TIMER_INT_CONTROLLER (working folder). TMRINT.sch and TMRINT-cache.lib carry a 2015-08-04 re-save mtime; TMRINT.sch is byte-identical to TMRINT.bak (2014-06-23) and its part list matches TMRINT.net (2014-03-11), so the commit is dated from the PCB, netlist, gerbers and BOM.
    [TMRINT.brd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]
2014-03-20 SRAM-8MB rev1: first schematic and layout
    Source: S100 8MB SRAM proto1/BACKUPS/20032014 1803
    [s100_SRAM.brd, s100_SRAM.sch]
2014-03-20 SRAM-8MB rev1: schematic and layout update (C38 removed)
    Source: S100 8MB SRAM proto1/BACKUPS/20032014 1941
    [s100_SRAM.brd, s100_SRAM.sch]
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2014-04-11 SRAM-8MB rev2: CPLD-based redesign, first layout
    Source: S100 8MB SRAM Proto2/BACKUPS/11042014 1823 (KiCad files; the copied rev1 BOM/ and other/ are left out)
    [s100_SRAMp2.brd, s100_SRAMp2.sch]
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2014-06-04 Flash-UART cpld: ISE project, reset logic, port EEh TMA0-3 register
    Source: Xilinx Projects/S100_BFU1_Rev1/backups/04-06-2014 1656
    [U20v1.sch]
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2014-07-16 Z80-CPU v3: schematic and placement rework
    Source: S100 Z80 version3/backups/17-07-2014 0138
    [s100_Z80 V3.kicad_pcb, s100_Z80 V3.sch]
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2015-05-03 DRAM-4GB-Unfinished: annotate power flags
    Source: S100 4GB DRAM BOARD/4Mem board v2/backups/04-05-2015 0939 (04-05-2015 1910 is byte-identical and is skipped; _autosave file left out)
    [4Mem board v2.sch]
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2015-07-22 Flash-UART cpld: port 95h selects flash U16 (smaller 25L020) or U14; PIC line joins reset
    Source: Xilinx Projects/S100_BFU1_Rev1/backups/10-08-2015 1907 (overlay: this backup has no outdated/ folder)
    Change started in "16-17-2015 changing flash cs to use smaller flash" (16 Jul 2015).
    [U20v1.sch]
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2015-08-10 Z80-CPU v2: schematic notes and rework wiring (WR+/RD+)
    Source: S100 Z80 version2/s100_Z80 V2.sch and -cache.lib (working folder).
    [s100_Z80 V2.sch]
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2016-01-09 PIC-SPI: schematic wiring fix, pre-route tracks before autorouting
    Source: S100 PIC_SPI_v1/backups/09-01-2016 1545
    [S10_PIC_SPI_v1.kicad_pcb, S10_PIC_SPI_v1.sch]
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

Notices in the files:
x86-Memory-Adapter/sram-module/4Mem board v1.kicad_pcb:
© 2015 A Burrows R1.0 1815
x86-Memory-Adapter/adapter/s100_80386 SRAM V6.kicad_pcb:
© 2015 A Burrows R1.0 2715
